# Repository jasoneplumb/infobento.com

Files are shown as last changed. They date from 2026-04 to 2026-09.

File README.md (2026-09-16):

# InfoBento

> _See what matters. Skip the spiral._












A small, solar-powered eInk decorator that lives on a counter, shelf, or windowsill. Configure once on a web page; it shows what matters most: weather, hourly and daily forecasts (configurable, 3 periods by default), air quality, UV index, pollen, quote, countdown, stocks, QR code, text, date, moon phase, sunrise/sunset, year progress, horoscope, on this day, holidays.

**Prototype, not a shipping product.** Firmware is bench-verified on a Seeed reTerminal E1001 (ESP32-S3) development board; the production ESP32-C3 hardware, the solar harvester, and the unattended run time that follows from them are design targets that have not been built or measured. Everything below marked _(target)_ is a specification, not an observed result. The product description is the design intent; [Status](#status) is what exists today.

## Overview

InfoBento is a small calm surface for the room. The information you check most often (whether it's going to rain, whether the air is clear enough to open the windows, days until something you're looking forward to) sits there in crisp eInk, visible at a glance from across the room. One-time Wi-Fi and sign-in setup, then no batteries to swap and nothing to fiddle with day to day.

Building a layout in the web editor needs no account; it saves to your browser.
Binding a device to that layout does: you claim it with a passkey or a Google/Apple
sign-in, so the server knows whose config to render for it.

Set it on a kitchen counter, a desk, or a shelf. The body is its own stand, with a fold-out kickstand to angle the display toward you if needed. The upper portion of the back is a solar panel intended to charge the device from indirect light through a window _(target; no energy balance has been measured)_. It refreshes a few times a day, which is plenty for the things you actually look at it for. Planned Kickstarter pricing: $109 early bird (first 500), $129 standard, or $239 for a pair ($119.50 each; ≈ $46.40 BOM at volume, the 5.76" panel is over half of it).

### Hardware

- **Display:** Good Display GDEH0576T81, 5.76" eInk, 920x680 pixels, 198 DPI, SSD2677 driver
- **Renderer:** eInk framebuffer with antialiased TTF fonts (Inter via opentype.js), SDF-based rounded box borders, configurable corner radius (0-7) and padding (0-10), font size stepper (8-42px)
- **MCU:** ESP32-C3 _(target)_ (Wi-Fi 4 + BLE 5; BLE radio reserved for a possible v2 bridge mode). Firmware bring-up runs on a reTerminal E1001 (ESP32-S3) bench board; the C3 port is pending.
- **Power:** ~100 mAh LiPo + AEM10941 solar harvester _(target)_. Deep-sleep current is still unmeasured: the bench USB meter resolves 10 mA and reads 0.00 A asleep, which cannot confirm a µA-class floor. Unattended run time follows from that measurement and is not yet claimed.
- **Solar panel:** mounted on the upper portion of the back side, ~70×100 mm
- **Connectivity:** Wi-Fi direct + captive-portal setup; no companion phone app. Web editor at `www.infobento.com` is the only configuration surface. See `docs/hardware/CONNECTIVITY.md`.
- **Recovery:** recessed pinhole reset (~2mm) on the back-lower grip area; press with paperclip for 5s = factory reset.
- **Form factor:** monolithic body, no hinge. The body stands on its own, with a fold-out kickstand to angle the display if needed.
- **Orientation:** two ball-in-tube tilt switches mounted at 90° on GPIO interrupts; firmware auto-rotates the layout across landscape, portrait, and inverted variants. Zero standby current, ~$0.10 BOM.
- **Industrial design:** white housing, thin bezel (≤4mm visible)
- **Drop survival:** designed to survive a 4-foot drop onto a hard surface: soft polymer bumper between glass and housing, edge-radiused corners, inset display recess

### Form factor

```
┌────────────────────┐  ◄── thin white bezel
│                    │
│   eInk             │      Front: display recessed below bezel rim
│   panel            │             so the rim shields the glass on
│                    │             a face-down drop
│                    │
└────────────────────┘
       ▲                   Back-upper: solar panel
       │ ~12-15° tilt      Back-lower: ESP32 + battery + grip area
       │ when set down
```

### Architecture

```
┌─────────────────┐    Wi-Fi     ┌──────────────┐
│     Device       │◄────────────►│  Cloud API   │
│  eInk            │              │ Hono + SQLite│
│  ESP32 + solar   │              └──────────────┘
└─────────────────┘                      ▲
                                         │
                                   ┌─────┴─────┐
                                   │  Web UI    │
                                   │  (config)  │
                                   └───────────┘
```

Rendering is a pure function of config: `POST /api/render` takes a BentoConfig and returns a frame buffer, and the web editor's preview uses exactly that path. The device never sends a config; it identifies itself with its device id and the server renders from the config it holds for that device. If Wi-Fi is unavailable the panel keeps showing its last frame (stale display, not blank). eInk holds its image with no power and no redraw. First-time setup via captive portal; on each refresh the device polls `www.infobento.com/api/device/{device-id}/frames` for a freshly rendered frame (both orientations in one response), using its device id as a bearer secret. Both orientations are written to a LittleFS partition so the green button can redraw the other one locally with the radio off ([firmware README](firmware/README.md)); that cache serves the flip, not a fallback render: the device never renders a frame itself. The web editor is where you set up your boxes; configuration lives in browser localStorage, and once a device is paired to an account it is also stored server-side and pushed via `PUT /api/device/{device-id}/config`.

## Quick Start

```bash
# Clone and install
git clone https://github.com/jasoneplumb/infobento.com.git
cd infobento.com
npm install

# Build and verify
npm run build
npm test
npm run lint

# Run the dev servers (two terminals)
npm run dev -w @infobento/api    # Hono API on :4000
npm run dev -w @infobento/web    # Vite editor on :5173, proxies /api to :4000
```

## Monorepo Structure

| Package | Name | Purpose |
| --- | --- | --- |
| `packages/core/` | `@infobento/core` | Types, bento box definitions, layout engine |
| `packages/data/` | `@infobento/data` | Box-data providers (weather, quote, …) + cache |
| `packages/renderer/` | `@infobento/renderer` | eInk frame buffer generation |
| `packages/api/` | `@infobento/api` | Render API, auth + pairing (SQLite), static files |
| `packages/web/` | `@infobento/web` | Web configuration interface |

## Self-hosting & auth env vars

The hosted SaaS (`infobento.com`) is the default path, but the API code is
public so you can run it yourself. The auth flows in `@infobento/api` need
the following env vars at runtime:

| Variable | Purpose |
| --- | --- |
| `SESSION_SECRET` | HMAC key for session + challenge cookies. Required. ≥16 chars, generate randomly. |
| `RP_ID` | WebAuthn Relying Party ID: your domain (e.g. `infobento.com`). |
| `RP_ORIGIN` | Origin(s) the browser will use, comma-separated (e.g. `https://www.infobento.com`). |
| `OAUTH_REDIRECT_BASE`  | Base URL for OAuth callbacks (e.g. `https://www.infobento.com/api/auth/oauth`). |
| `GOOGLE_CLIENT_ID` | Google OAuth client ID. Get from console.cloud.google.com → Credentials. |
| `GOOGLE_CLIENT_SECRET` | Google OAuth client secret. |
| `APPLE_CLIENT_ID` | Apple "Service ID" identifier (e.g. `com.example.signin`). |
| `APPLE_TEAM_ID` | Apple Developer team ID (10-char alphanumeric). |
| `APPLE_KEY_ID` | Apple "Sign in with Apple" private key ID (10-char alphanumeric). |
| `APPLE_PRIVATE_KEY` | PEM-encoded ES256 private key (PKCS8) for Apple. Multi-line; use the literal value. |
| `INFOBENTO_DB_PATH` | (Optional) SQLite file path. Default `/var/lib/infobento/data.db`. |

Setting up the OAuth credentials:

- **Google:** create an OAuth 2.0 Client ID (Web application) at
  [console.cloud.google.com → APIs & Services → Credentials](https://console.cloud.google.com/apis/credentials).
  Authorized redirect URI: `https://<your-domain>/api/auth/oauth/google/callback`.
- **Apple:** at [developer.apple.com → Certificates, Identifiers & Profiles](https://developer.apple.com/account/resources/identifiers/list):
  1. Create an App ID with "Sign in with Apple" capability.
  2. Create a Services ID (this is your `APPLE_CLIENT_ID`); enable Sign in with Apple
     and configure return URLs: `https://<your-domain>/api/auth/oauth/apple/callback`.
  3. Create a Key with "Sign in with Apple" enabled; download the `.p8` and note the
     Key ID (`APPLE_KEY_ID`). Your team ID is in the top-right of the Developer portal.

If neither OAuth provider is configured, the app falls back to passkey-only
auth (still usable on any modern browser/OS). Passkey login does not require
OAuth credentials at all.

## Manufacturing: device stickers

Each device ships with a sticker carrying a QR code that opens its pairing page
(`/pair/<pair_code>`) plus the human-readable pair code as a camera-free fallback.
Generate sticker artwork from a CSV of minted devices:

```bash
# CSV columns: device_id,pair_code  (header row optional)
npm run gen-stickers -- scripts/sample-devices.csv stickers/

# Add a tiled, print-ready batch sheet (A4 by default; --page letter for US):
npm run gen-stickers -- devices.csv stickers/ --sheet --page letter

# Point the QR at a non-production origin (self-host / staging):
npm run gen-stickers -- devices.csv stickers/ --base-url https://staging.infobento.com
```

Output is one `<device_id>.svg` per row (designed to print at 25mm × 25mm) and,
with `--sheet`, page-sized `sheet.svg` (or `sheet-1.svg`, `sheet-2.svg`, … when
the roster spans multiple pages) you can open in a browser and Print → PDF. Pair
codes and device ids are validated, so a typo in the CSV fails loudly instead of
producing an unscannable sticker or escaping the output directory. The QR encodes
only the pair code, never the device id, which is the firmware's bearer secret.

Mint the devices first with [`scripts/mint-device.ts`](scripts/mint-device.ts).

## Documentation

See [docs/README.md](docs/README.md) for the full documentation index.

## Contributing

See [CONTRIBUTING.md](CONTRIBUTING.md) for development workflow and guidelines.

## License

InfoBento is open-source hardware. Each part of the repo uses the license that
fits the work, and **all of them permit building and selling devices based on
this design**:

- **Software** (`packages/`, `scripts/`, root): [Apache-2.0](LICENSE)
- **Hardware** (`hardware/`): [CERN-OHL-P-2.0](hardware/LICENSE)
- **Documentation** (`docs/`): [CC-BY-4.0](docs/LICENSE)

See [LICENSING.md](LICENSING.md) for the full breakdown. Copyright © 2026 Jason
E Plumb and InfoBento contributors.

## Results

| | |
| --- | --- |
| **Contribution** | Sole author of the renderer, web service, device-pairing flow, and firmware sketches, AI-assisted under CI and bench verification. Third-party: the Seeed reTerminal E1001 bench board, Good Display panel, AEM10941 harvester, and the box-data providers' upstream APIs. |
| **Status** | Prototype. Firmware bench-verified on a reTerminal E1001 (ESP32-S3); production ESP32-C3 hardware not built. No manufacturing, no Kickstarter launched, no users. |
| **Verification** | Firmware phases 0–7 bench-verified on the E1001 (epic #106): blink, static frame, Wi-Fi device pull, deep sleep, resilience, captive-portal provisioning, and the integrated build, including `304 -> skip` conditional-refresh behavior, dual-orientation LittleFS caching with radio-off button flip, empty-store guard, and factory reset. Per-phase records in [`firmware/README.md`](firmware/README.md#phase-status). |
| **Reproduction** | Web service: see Quick Start. Firmware: the per-phase procedures in `firmware/README.md` on a reTerminal E1001. Power figures need µA-grade instrumentation the bench does not have. |
| **Limitations**  | Deep-sleep current is unmeasured: the bench USB meter resolves 10 mA and reads 0.00 A asleep, which cannot distinguish ~50 µA from a hidden ~10 mA, and the E1001's always-on peripherals read higher than the C3 target regardless. Solar autonomy and unattended run time are therefore design targets, not results. The firmware's TLS certificate validation gap is a known production-readiness defect (see `firmware/README.md`). Pricing and BOM figures are estimates for hardware that has not been built. |

## Status

Active development. Renderer produces framebuffers with 18 box types. Web editor at localhost:5173 for configuration. Passkey + Apple/Google OAuth and the SaaS device-pairing flow are shipped in `@infobento/api` (epic #77 complete). Firmware bring-up is dev-first on the reTerminal E1001: Phases 0–7 are bench-verified (epic #106) - blink, static-frame, Wi-Fi device-pull, deep-sleep, resilience, captive-portal provisioning, and the integrated firmware ([`firmware/integrated/integrated.ino`](firmware/integrated/integrated.ino), #174). The remaining production-hardware step is sourcing the GDEH0576T81 panel + ESP32-C3 (dev work continues on the E1001). Per-phase status lives in [`firmware/README.md`](firmware/README.md#phase-status).

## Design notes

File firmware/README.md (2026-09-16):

# InfoBento firmware (bench bring-up)

Dev-first firmware for epic #106. These are **bench sketches**, not a structured
firmware project yet: each is a single self-contained Arduino `.ino` that proves
one capability on the dev hardware before the next builds on it.

- **Dev board:** Seeed reTerminal E1001, ESP32-S3, 7.5" 800×480 grayscale panel
  driven by a UC8179 controller.
- **Production target (not yet sourced):** GDEH0576T81 5.76" 920×680 + ESP32-C3
  (#57 closed; 4-level gray proven on the E1001, panel sourcing remains). The
  production port re-points the integrated build to it.

The reTerminal maps 1:1 onto the renderer's 2-bit output and hits the **identical**
cloud endpoints, so everything proven here ports directly to production.

## Toolchain

[`arduino-cli`](https://arduino.github.io/arduino-cli/) with the `esp32` core.
All sketches build for `esp32:esp32:esp32s3` (ESP32S3 Dev Module).

```bash
arduino-cli core install esp32:esp32
arduino-cli compile --fqbn esp32:esp32:esp32s3 firmware/<sketch>
arduino-cli upload  -p /dev/cu.usbserial-XXXX --fqbn esp32:esp32:esp32s3 firmware/<sketch>
arduino-cli monitor -p /dev/cu.usbserial-XXXX -c baudrate=115200
```

Serial routes to UART0 (the onboard USB-UART bridge, `/dev/cu.usbserial-*`) because
the core's `USB CDC On Boot` defaults to Disabled. If you enable CDC-on-boot, Serial
moves to the native USB port (`/dev/cu.usbmodem*`) and bridge-port prints vanish.

## Phase status

| Phase | Sketch | Proves | Status |
| ----- | --- | --- | --- |
| 0 | (server) `scripts/mint-device.ts` | mint device, `/frame` returns 200 | ✅ done (PR #109) |
| 1 | [`blink/`](blink/blink.ino) | toolchain + boot + serial, no panel | ✅ bench-verified |
| 2 | [`static-frame/`](static-frame/static-frame.ino) | framebuffer-translation path: native 2bpp → UC8179 two-plane upload (4-band gray ramp) | ✅ bench-verified |
| 3 | [`device-pull/`](device-pull/device-pull.ino) | Wi-Fi + `GET /api/device/<id>/frame` poll loop with `If-Modified-Since`/304 skip | ✅ bench-verified |
| 4 | [`deep-sleep/`](deep-sleep/deep-sleep.ino) | deep sleep + RTC wake; RTC-persisted `Last-Modified` so a 304 wake skips the refresh | ✅ bench-verified |
| 5 | [`resilient/`](resilient/resilient.ino) | resilience: graceful 404/429/5xx/Wi-Fi-fail handling, brownout recovery, clean draw-abort | ✅ bench-verified |
| 6 | [`provisioning/`](provisioning/provisioning.ino) | captive-portal provisioning: AP-mode first boot, Wi-Fi scan/entry → NVS, OS auto-launch probes, pinhole factory reset → #39 | ✅ bench-verified |
| 7 | [`integrated/`](integrated/integrated.ino) | integrated build → #173: provisioning + dual-orientation deep-sleep pull (`GET /frames`) + green-button flip + two-white-button (5 s) factory reset (#171/#172) | ✅ merged (PR #174) |
| N/A | N/A | port to production GDEH0576T81 + ESP32-C3 (#57 closed; gray proven on the E1001; panel not yet sourced) | ⬜ (awaiting panel) |
| ★ | [`orientation/`](orientation/orientation.ino) | manual orientation toggle → #160: `GET /frames` caches BOTH orientations in LittleFS, green button (GPIO3, ext1) flips locally with Wi-Fi off | ✅ folded into `integrated/` (#174) |

"Bench-verified" = run on real E1001 hardware. Phase 3 evidence lives in the
(gitignored) `dev/serial.log`: a live run shows `GET → 200`, `drew frame in
4486 ms`, then steady `304 → skip refresh`.

**Phase 4 bench-verified on the E1001** (`IB_SLEEP_SECONDS` = 30 s bench cadence).
A live run captured the full state machine on serial:

- each wake boots from deep sleep (`rst:0x5 (DSLEEP)`, `wake cause 4 (RTC timer)`)
  and the `boot #N` counter increments across sleeps, proving the RTC-persisted
  state (`RTC_DATA_ATTR`: boot counter + cached `Last-Modified`) survives;
- steady state (no server change): `GET -> 304 ... skip refresh` then straight
  back to `deep sleep`: **no `drew frame`, panel does not flash**;
- push a new config server-side → the next wake logs `GET -> 200`, the new
  `Last-Modified`, and `drew frame in 4486 ms`; the wake _after_ that returns to
  `304 -> skip`, confirming the new token was cached to RTC and the panel redraws
  exactly once per change.

To reproduce the 200-draw: `firmware/dev/push-config.sh <config> <device-id>`
(point `INFOBENTO_DB_PATH` at the DB the running API opened; `lsof` it if unsure).

Bench power snapshot (USB inline meter, 10 mA resolution, DROK VB26VA), board
level over USB:

- **304 wake** (no redraw): **≈ 80 mA for ~2 s** (the Wi-Fi blip), then sleep.
  ≈ 0.04 mAh per wake.
- **200 wake** (panel refresh): the Wi-Fi blip **plus** a **4.5 s draw at ≈ 60 mA
  sustained, peaking ≈ 150 mA** in the final ~1 s (last waveform phase / booster).
  ≈ 0.15 mAh per wake.
- **Deep sleep:** reads `0.00 A`, i.e. **< 10 mA** at the board level.

So the active side is cheap: even at a worst-case "redraw every wake," 1–2 wakes/
day is well under 1 mAh/day, and the daily budget is dominated entirely by the
sleep floor.

Still open: that floor is **below this meter's 10 mA resolution**, so the real
**single-digit-µA** figure remains unmeasured: the gap is decisive (≈50 µA →
~1 mAh/day vs a hidden ~10 mA → ~240 mAh/day). Capturing it needs a µA-grade
instrument on the **battery/supply line** (not USB): the reTerminal dev board
reads higher than the ~10 µA production target because of its always-on
peripherals + USB-UART bridge, so the definitive number is an ESP32-C3
measurement deferred to the production port.

**Phase 5 bench-verified on the E1001** (`IB_SLEEP_SECONDS` = 30 s bench cadence). A
live run walked all five cases on serial; in every failure case the panel kept its
last good frame and the device slept and recovered on its own:

- **API down** → `GET -> -1` → `keep last frame, retry next wake` → `deep sleep 30 s`;
  restarting the server → a later wake reconnects (`304 -> skip`).
- **Unprovisioned id** (config cleared in the DB) → `GET -> 404 ... unprovisioned ->
keep last frame`, no draw.
- **Wi-Fi failure** (bogus SSID) → `Wi-Fi FAILED -> keep last frame, retry next wake`,
  sleeps without hanging.
- **Rate limit** (device id hammered past 10/min) → `GET -> 429 -> honor Retry-After,
sleep 60 s`; note the **60 s** back-off, distinct from the normal 30 s.
- **Normal** (bumped `last_modified`) → exactly one `GET -> 200 ... drew frame`, then
  `304 -> skip` on the next wake (token committed to RTC only after the confirmed draw).

**Phase 5 bench check (operator).** Flash `resilient/` and force each failure: in
every case the panel must keep its last good frame (never blank/garble) and the
device must sleep and recover on its own:

- **API down:** stop the Hono server → `GET -> <negative>` → `keep last frame,
retry next wake` → `deep sleep`. Restart the server → a later wake draws normally.
- **Unprovisioned id:** point `secrets.h` at a device with no config (or clear it in
  the DB: `UPDATE devices SET config_json=NULL WHERE id=…`) → `GET -> 404 ...
unprovisioned` → sleep, no draw.
- **Wi-Fi failure:** break the **SSID** (point at a non-existent network) → `Wi-Fi
FAILED` → `keep last frame` → sleep (no hang, no crash). Note: breaking `WIFI_PASS`
  does **not** work on an **open** network: an open AP associates with any password
  string, so it would falsely "pass". Break the SSID (works on any network), or break
  the password only against a **WPA2** AP.
- **Rate limit:** hammer the device id past 10/min (e.g. burst `curl …/config` for it)
  → `GET -> 429 ... honor Retry-After, sleep 60 s`. The bucket is per-device-id and
  shared across `/config` + `/frame`, and refills 1 token/6 s, so sustain the burst
  across a wake.
- **Normal:** unchanged config still `304 -> skip`; a pushed config (or a bumped
  `last_modified`) still draws once then returns to 304 (token committed only after
  the confirmed draw).

**Phase 6 bench-verified on the E1001.** A live run walked the full out-of-box
flow on serial: first boot → `no creds -> AP mode, SSID 'InfoBento-C93F'` →
`captive portal up`; an iPhone auto-launched the setup page; scan + join saved
creds and rebooted into `provisioned=1`, which then rejoined silently
(`provisioned + online -> hand off to pull loop`). The pinhole factory reset,
wrong-password rejection, and unreachable-network AP fallback all behaved as
specified (see the checklist below). Two bench notes: the wrong-password path is
only meaningful against a **WPA2** network: an open AP (no auth) associates with
any password string, so test it with a password-protected 2.4 GHz hotspot (the
ESP32-S3 has no 5 GHz radio; on iPhone enable Personal Hotspot → Maximize
Compatibility to force 2.4 GHz). Use a separate device as the portal client: a
phone serving the hotspot can't simultaneously join the `InfoBento-XXXX` AP.

**Phase 6 bench check (operator).** Provisioning needs AP mode + a phone, so it
can't be CI-verified; flash `provisioning/` and walk the out-of-box flow. The
sketch has NO `secrets.h` (it has no creds to begin with). Watch serial at
115200:

- **First boot (no creds):** `no creds -> AP mode, SSID 'InfoBento-XXXX'` then
  `captive portal up`. A factory device must always land here.
- **Auto-launch:** join the open `InfoBento-XXXX` network from a phone/laptop:
  the OS should pop a browser straight onto the setup page (Apple
  `hotspot-detect.html`, Android `generate_204`, Windows `ncsi.txt` all 302 to
  the portal). If it doesn't auto-open, browse to `http://192.168.4.1`.
- **Scan + join:** the network dropdown is populated server-side (no JS). Pick
  your home Wi-Fi, type the password, **Connect** → `joining '<ssid>' ...` →
  `joined, IP …` → `provisioned -> creds saved` → the success page shows the
  Device ID → `rebooting into provisioned mode`. (Pairing actually happens at
  `www.infobento.com/pair/<code>` after sign-in; the sketch still prints a dead
  `infobento.com/onboard?device=<id>` URL here; the sketch-side fix is tracked
  in #241.)
- **Wrong password:** the portal must re-render with a retry banner and NOT
  persist the bad creds (`join FAILED`, no `creds saved`).
- **Returning boot (creds saved):** after the reboot, `provisioned=1` → it
  rejoins the saved network silently (`hand off to pull loop`), no AP. Move the
  device to an unreachable network → it falls back to AP mode for re-setup.
- **Pinhole reset:** ground the pinhole pin for 5 s →
  `PINHOLE 5s hold -> factory reset (clearing creds)` → reboot → back to AP
  mode. A momentary tap must NOT reset (the hold timer resets on release). On the
  E1001 the pinhole maps to **GPIO2** (expansion header J2 pin 4, one pin from
  GND on pin 2; note the header is numbered in reverse of the silk/spec table);
  GPIO9 is the production-C3 pin but on the E1001 it is the panel SPI MOSI line.
- **Page budget:** the setup page is a few KB of inlined HTML/CSS, no JS, no
  external assets, comfortably inside the <30 KB-gzipped target.

`PINHOLE_GPIO` and the AP/NVS specifics are marked MCU-specific in the sketch for
the ESP32-C3 production port. Production uses **GPIO9** (the C3 strapping pin with a
natural pull-up: the reason #39 picked it); the `IB_DEV_E1001` branch swaps in
**GPIO2** for bench bring-up because on the E1001 dev board GPIO9 is the panel SPI
MOSI line (and GPIO0/BOOT is tied to the USB-serial auto-reset), so neither can
serve as the pinhole there. Note the later `integrated/` build (#171/#172) moved
factory reset off the pinhole entirely: holding the **two white buttons** for 5 s
(GPIO4+GPIO5) is now the reset gesture; the pinhole story above applies to this
provisioning-era sketch.

**Orientation toggle (`orientation/`, #160 / RFC 0002).** This behavior now lives
in the integrated sketch (`integrated/`, PR #174); the notes below cover the
standalone bench sketch. Extends the Phase 4 deep-sleep pull: each network wake fetches BOTH orientations in
one `GET /api/device/<id>/frames` and stores them to a LittleFS partition; a green-
button press (GPIO3, ext1 deep-sleep wake) redraws the other cached orientation with
the radio off. The server delivers both frames in the panel's landscape raster
(portrait pre-rotated server-side, PR #164), so `uploadFrame` is orientation-agnostic.
The GPIO2 reset pinhole is untouched: a distinct input from the toggle button.

Flash with the 8 MB partition scheme **and declare `FlashSize=8M`**: the FQBN
defaults to 4 MB, which overflows the `default_8MB` table and boot-loops
(`partition N ... exceeds flash chip size 0x400000`). The E1001 is physically 32 MB;
Seeed's Arduino guidance is to select 8 MB. Then provide `orientation/secrets.h`
(gitignored, mirror `deep-sleep/`'s):

```
arduino-cli compile -u -p /dev/cu.usbserial-XXXX \
  --fqbn 'esp32:esp32:esp32s3:UploadSpeed=115200,FlashSize=8M,PartitionScheme=default_8MB' firmware/orientation
```

(Fallback if that ever boot-loops: drop `FlashSize` and use `PartitionScheme=default`;
the 4 MB scheme still carries a ~1.4 MB LittleFS partition, plenty for the ~192 KB
pair.)

**Orientation bench check (operator).** Watch serial at 115200:

- **First network wake (cold boot / timer):** `GET /frames -> 200` → `stored both
frames` → `drew frame` in landscape. A second wake within the window logs
  `304 -> keep cached frames, no redraw` (the Phase 4 power win still holds).
- **Button flip:** press the green button → `(green button)` wake, `flip landscape to
portrait`, `drew frame`: **with no `GET`** (radio stays off). Press again → flips
  back. Confirm the flip is ~one refresh, not a Wi-Fi cycle.
- **Orientation is up-right:** if portrait shows upside-down, flip the server-side
  rotation direction from `'cw'` to `'ccw'` in `getDeviceFramesForPull` (`device.ts`),
  not a firmware change.
- **Empty store guard:** press the button before the first network wake ever ran →
  `no cached frame to flip to (empty store) -> no-op` (no garbage drawn).
- **Persistence across power loss:** flip to portrait, pull the battery/USB, repower →
  cold boot restores `portrait` from NVS (not silently back to landscape).
- **Reset pinhole unaffected:** the GPIO2 pinhole still factory-resets via the
  provisioning sketch; the toggle button (GPIO3) never clears creds.

MCU-specific for the ESP32-C3 production port: the green-button GPIO and the ext1
wake API (C3 uses `esp_deep_sleep_enable_gpio_wakeup`) are re-mapped; the toggle logic
is otherwise identical.

## Framebuffer translation (the key risk Phase 2 retired)

The renderer emits **native** 2bpp, MSB-first, 4px/byte, `0=white … 3=black`. The
UC8179 grayscale path wants `0=black … 3=white`. Because the packing is identical,
the per-pixel `3 - level` flip is exactly a per-byte bitwise NOT
(`0x00↔0xFF`, `0x55↔0xAA`); see `drawFrame()`. The UC8179 driver (pins, LUTs,
init, two-plane upload, refresh, sleep) is vendored verbatim from Seeed's
`GxEPD2_reTerminal_E1001_Gray4` example, including its internal `3 - gray`
waveform-polarity inversion. Pin map: SCK 7, MOSI 9, CS 10, DC 11, RES 12, BUSY 13.

## Secrets & dev tooling (gitignored)

`device-pull` needs a `secrets.h` in its sketch dir:
`firmware/device-pull/secrets.h` (Arduino resolves `#include "secrets.h"`
relative to the `.ino`). Not committed; `firmware/**/secrets.h` is gitignored:

```c
// LAN dev server (plain HTTP):
#define WIFI_SSID   "your-ssid"
#define WIFI_PASS   "your-pass"
#define IB_API_HOST "192.168.x.x"   // dev machine running the Hono API
#define IB_API_PORT "4000"
#define IB_DEVICE_ID "<id from `npm run mint -w @infobento/api`>"
#define IB_API_TLS  0               // deep-sleep only: 0 = http (LAN dev)
```

For the **production** server (`deep-sleep` sketch), keep the same `WIFI_SSID` /
`WIFI_PASS` as above and change the API fields to point at `www.infobento.com`
over HTTPS (mint the device id on the host; see `docs/DEPLOY.md`):

```c
#define WIFI_SSID   "your-ssid"     // same Wi-Fi creds as above — still required
#define WIFI_PASS   "your-pass"
#define IB_API_HOST "www.infobento.com"
#define IB_API_PORT "443"
#define IB_DEVICE_ID "<id minted on the prod host>"
// IB_API_TLS defaults to 1 (https) — omit, or set explicitly:
#define IB_API_TLS  1
```

`IB_API_TLS` is a build-time **switch**, not a statement about which sketches can
speak HTTPS. How each one chooses its transport:

| Sketch | Transport |
| --- | --- |
| `deep-sleep`, `orientation` | `IB_API_TLS` macro, defaults to `1` (https); set `0` in `secrets.h` for LAN dev |
| `integrated` | runtime: HTTPS iff the stored server URL starts with `https` |
| `device-pull`, `resilient`  | HTTP only, by design (LAN bench tools) |

So three sketches can reach production over TLS, and none of them verifies the
certificate; see the warning below.

> ### ⚠️ These sketches do not verify TLS certificates
>
> Every sketch that speaks HTTPS (`deep-sleep`, `orientation`, `integrated`)
> calls `client.setInsecure()`, which disables certificate validation entirely.
> Combined with the fact that **the device id is a bearer secret carried in the
> URL path** (`/api/device/<device-id>/frames`), an attacker positioned between
> the device and the network (a hostile Wi-Fi access point, a compromised
> router, an ARP-spoofing neighbour) can present any certificate, read the
> device id, and from then on impersonate the device or pull its owner's
> rendered frames.
>
> This is acceptable for **bench work on a network you control**, which is all
> these sketches are currently used for. It is **not** acceptable for firmware
> shipped on hardware in other people's homes.
>
> Hardening is tracked in **#145**: pin the ISRG Root X1 CA via
> `client.setCACert(...)`, add an explicit `http.setTimeout()` so the TLS
> handshake has margin, and optionally persist the TLS session ticket in RTC
> memory across wakes. Anyone building on this firmware for real deployment
> should do that first.

`provisioning` is the **exception**; it has no `secrets.h` and needs none: the
whole point of captive-portal setup is that the device starts with no creds and
obtains them from the user, so it compiles and runs with nothing pre-baked.

`firmware/dev/` (also gitignored) holds bench helpers: `push-config.sh`,
`serial-boot.sh`, `config-e1001.json`, and captured `serial.log`.

## Forward plan

1. **Phase 4 - deep sleep + RTC.** ✅ bench-verified (`deep-sleep/`). The
   `loop()` `delay(IB_POLL_MS)` busy-wait is gone: the whole
   cycle runs in `setup()` and ends in `esp_deep_sleep_start()` for the
   `IB_SLEEP_SECONDS` build constant. `Last-Modified` persists across sleeps in
   RTC slow memory (`RTC_DATA_ATTR`), so a 304 wake returns to sleep without
   touching the panel. This is what makes the solar/battery budget real.
2. **Phase 5 - resilience.** ✅ bench-verified (`resilient/`). Every failure mode
   degrades gracefully: Wi-Fi down / wrong
   creds / 404 (unprovisioned) / 5xx / transport error → don't draw, sleep the
   normal cadence, retry next wake (eInk holds the last good frame for free, so no
   flash framebuffer cache is needed); 429 → honor `Retry-After`; brownout reset →
   skip the fetch and sleep a longer recovery interval. Two correctness fixes over
   Phase 4: `checkBusy` records a timeout so `drawFrame()` aborts cleanly on a stuck
   panel, and the cached `Last-Modified` is committed to RTC **only after a
   confirmed draw** (else a failed refresh would 304 the next wake and strand the
   panel on a frame that never rendered).
3. **Phase 6 - captive portal (#39).** ✅ bench-verified (`provisioning/`).
   AP mode on first boot, on-device no-JS setup
   page (server-side Wi-Fi scan → creds + optional custom server URL self-host
   hatch), NVS storage, OS auto-launch probes, and a pinhole factory
   reset (GPIO2 on the E1001; GPIO9 is the production-C3 pin; see the Phase 6
   bench check above; the later `integrated/` build moved factory reset to the
   two white buttons held 5 s, #171/#172). Creds persist only after a confirmed join, so a wrong password never
   strands un-joinable creds in NVS; a returning device with un-joinable saved
   creds falls back to AP for re-provisioning. The web-side "forget Wi-Fi"
   counterpart (`POST /api/device/:id/forget`, same effect as the pinhole) is
   the server half, merged separately (#39). This is the gate to a shippable
   out-of-box flow.
4. **Phase 7 - integrated build (#173).** ✅ merged (PR #174, `integrated/`):
   provisioning + dual-orientation deep-sleep pull + green-button flip +
   two-white-button factory reset in one sketch.
5. **Production port.** Re-point pins/dimensions to GDEH0576T81
   (920×680, 156,400-byte frame) on ESP32-C3 once the panel is sourced
   (#57 closed; gray rendering proven on the E1001).

### Shared UC8179 driver - extraction deferred (decision)

The UC8179 driver (pins, 5 gray LUTs, `initGrayMode`/`uploadFrame`/`refresh`/
`sleep`) is still copy-pasted across `static-frame`, `device-pull`, `deep-sleep`,
and now `resilient` (5 copies). Phase 4 was the nominal time to extract it, but
**it stays vendored per-sketch on purpose**: Arduino's build model can't share a
header across sibling
sketch folders without breaking the documented zero-flag build. `arduino-cli
compile firmware/<sketch>` only sees the sketch dir (and its `src/` subfolder) plus
_installed_ libraries: a real shared header needs either a library + a
`--libraries firmware/libraries` flag (changes the build command everyone runs and
adds a library-management step that fights the "self-contained bench sketch"
philosophy) or a copy in each sketch's `src/` (not actually shared). The clean home
for this is a proper Arduino library when the firmware graduates from bench sketches
(Phase 6/7), where a real project layout earns the build-command change.

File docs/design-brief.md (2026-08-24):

---
title: 'InfoBento Design Brief'
subtitle: 'UX model, requirements, and design decisions'
date: 'June 2026'
---

# InfoBento Design Brief

_A calm bento dashboard for counters, desks, and shelves._

**Domain:** Consumer electronics
**Phase:** Campaign (pre-Kickstarter)
**Last reviewed:** 2026-08-23, against v0.38.3

---

## Product Overview

InfoBento is a small, solar-powered eInk bento dashboard for counters, desks, and shelves. It is glance-first: a calm multi-box dashboard that configures once and refreshes on schedule.

- **Positioning:** A lean, calm bento dashboard for counters, desks, and shelves.
- **UI model:** Multi-box bento dashboard — up to 10 boxes (no fixed constant: the layout engine derives the row cap as `min(10, max(4, floor(height / (fontSize × 3))))`), multi-column.
- **Display:** Good Display **GDEH0576T81**, 5.76" eInk, **920×680 px**, **198 DPI**, **SSD2677** driver IC, eInk. Framebuffer **156,400 bytes** (packed 2-bit, 4 levels per pixel). Refresh 1–3×/day (default 3); 0.75 s full / 0.3 s partial (datasheet). Active area 117.7×87.0 mm; module 125.4×99.5×0.9 mm.
- **Enclosure:** white monolithic housing ≈14×11 cm sized to fit the GDEH0576T81 closely; thin bezel ≤4 mm; body-as-stand, with a fold-out kickstand to angle it ≈12–15° if needed.
- **MCU:** ESP32-C3 (Wi-Fi + BLE; BLE reserved for a possible v2 bridge). Captive-portal setup; no companion app v1; config via the infobento.com web editor.
- **Power:** ≈70×100 mm solar panel on the upper back + ≈100 mAh LiPo + AEM10941 solar harvester; 1–3 refreshes/day (default 3).
- **Orientation:** two ball-in-tube tilt switches for orientation auto-rotate.
- **Interaction:** minimal device interaction — two controls in the shipped firmware: a green button flips orientation, and holding the two white buttons for 5s factory-resets.

Configure once at the infobento.com web editor; the display then runs quietly on solar power, refreshing on schedule.

---

## 1. Work Roles

### Device Owner

Individual who owns an InfoBento display and places it on a counter, shelf, or windowsill.

**Responsibilities:**

- Configure bento boxes via web UI
- Place device on a counter or shelf with the solar panel exposed to indirect window light
- Complete first-time captive-portal Wi-Fi setup
- Update configuration occasionally as priorities change

### Gifter

Person who purchases and pre-configures an InfoBento as a gift for someone else.

**Responsibilities:**

- Select and order device
- Configure initial bento layout for recipient
- Share config JSON with recipient (export/import in the web editor), or claim the device to an account and save the layout server-side before gifting

---

## 2. User Classes

### Desk Decorator (Primary)

Person who values aesthetic, minimal desk or counter accessories and wants a bento-box-sized eInk display that shows a multi-box dashboard of useful status boxes -- standing on its own, the body is the stand.

**Goals:**

- Have a visually pleasing desk or counter accessory that is also functional
- Show countdown to meaningful events
- Display a personal link or QR code for networking
- A device that charges itself near a window without any cables

**Frustrations:**

- Digital photo frames are too large and power-hungry
- Sticky notes with countdowns look unprofessional
- No small, elegant way to display a personal QR code
- Desk gadgets always need cables or batteries

### Daily Glancer (Secondary)

Busy professional who wants a calm passive display of key daily info -- weather, next event, a quote -- visible at a glance from across the room. The founder is this user.

**Goals:**

- See today's weather and schedule without picking up a phone
- Reduce screen time by offloading ambient info to a passive display
- Customize what info matters most to them

**Frustrations:**

- Checking phone for simple info leads to distraction rabbit holes
- Smart home displays are too expensive and power-hungry
- Existing e-paper gadgets are not customizable
- Every phone interaction is an attention trap

### Gift Giver

Someone who wants to give a thoughtful, personalized tech gift that is useful without being overwhelming.

**Goals:**

- Give a unique gift that feels personal and curated
- Pre-configure the device so the recipient can use it immediately
- Gift something that does not require technical knowledge to enjoy

**Frustrations:**

- Most tech gifts require complex setup
- Generic gifts lack personal touch
- Subscription-based gifts feel like an obligation

---

## 3. Design Principles

### Zero Device Interaction

> InfoBento has no buttons. The entire loop is configure once, glance often.

Zero interaction remains the design ideal, but the shipped firmware keeps two deliberate controls: the green button flips orientation, and holding the two white buttons for 5s factory-resets. Nothing on the device configures content. The display charges via solar passively and refreshes on schedule; everything else happens in the web editor.

| Do | Don't |
| --- | --- |
| Glance at counter display from across the room | Require a button press to refresh |
| Configure once in the web editor | Dedicated companion app |
| Solar charging near a window without cables | Manual charging schedule or cable |
| Captive-portal first-time setup, no app | Notification stream or buzzer |

### Pure Function Architecture

> The API must be stateless -- same config in, same frame buffer out, every time.

No server-side state, no user accounts, no databases. Config lives on the client. Device caches last framebuffer in flash for offline resilience.

> **⚠️ Superseded (epic #77).** The principle above is retained as the original design record. It no longer describes the shipped system: the API stores accounts, device pairings, and per-device config in SQLite, and auth is passkey + Apple/Google OAuth. What survives is narrower — _rendering_ is still a pure function (`POST /api/render`: config in, frame buffer out), and the web editor's preview uses exactly that path. The device-facing `/frames` path is stateful by design: the device sends only its id, and the server renders from stored config. The flash-cache claim above also turned out to be unnecessary: eInk holds its last image with no power, so offline resilience needs no stored framebuffer (see `docs/hardware/CONNECTIVITY.md`).

### Visual Restraint

> A tight, intentional tonal palette used with discipline. Every tone earns its place.

The palette is deliberately restrained: a few intentional tones rather than a gradient, applied to express a clear visual hierarchy. Think newspaper print, not a photograph. Tone and contrast distinguish hero text, body text, and metadata — hero/display text reads large without needing maximum contrast, body text carries the most important content, and metadata sits quietly in support.

### Free by Default

> All box types must work without accounts, API keys, or subscriptions.

All box types use free data sources or local computation. Weather, forecasts, sunrise/sunset, air quality (AQI), UV, and pollen use Open-Meteo cloud data. Quotes use a quotable mirror (api.quotable.kurokeita.dev), stocks use Yahoo Finance, horoscope uses api-ninjas, on-this-day uses Wikipedia, and holidays use Nager.Date. The rest — QR, text, date, moon phase, countdown, and year progress — are pure local computation.

### Web-Only Configuration

> InfoBento is configured exclusively from a web browser. No native phone app required.

The web editor at infobento.com is the only configuration surface. No companion iOS or Android app for v1. This removes ≈6+ months of engineering scope and the iOS background BLE risk.

### Solar-Powered Counter Display

> A single monolithic body that stands on its own, with a fold-out kickstand to angle it if needed.

White monolithic enclosure ≈14×11 cm sized to fit the GDEH0576T81 (5.76", 920×680) closely, with a thin bezel (≤4 mm) and a fold-out kickstand for ≈12–15° tilt. Solar panel on the upper back, with the AEM10941 harvester topping up the ≈100 mAh LiPo. Two ball-in-tube tilt switches drive orientation auto-rotate.

---

## 4. Requirements

| ID | Statement | Priority |
| --- | --- | --- |
| REQ-001 | User can configure up to 10 bento boxes via web interface | Must |
| REQ-002 | Device syncs via Wi-Fi direct, no companion phone app | Must |
| REQ-003 | Display refreshes 1–3x/day on solar power alone (default 3, configurable) | Must |
| REQ-004 | 18 box types without user accounts; derived cap of 10 | Must |
| REQ-005 | Web UI and API served from same port in production | Must |
| REQ-006 | Config persists in localStorage with JSON export/import | Must |
| REQ-007 | QR code gets ≈half display height for scannability | Must |
| REQ-008 | Live PNG preview before syncing to device | Must |
| REQ-009 | V1 uses an eInk panel (display color capability TBD) | Must |
| REQ-010 | Enclosure ≈14x11cm, fits GDEH0576T81 panel closely | Must |
| REQ-011 | Display >=198 DPI, <=4mm visible bezel | Should |
| REQ-012 | Auto-rotate via two tilt switches, 4 orientations | Must |
| REQ-013 | Minimal interaction — orientation + factory reset buttons | Must |

---

## 5. Scenarios

### Morning Glance at Kitchen Counter

**User class:** Daily Glancer
**Setting:** Kitchen counter near window, 7:15 AM, making coffee

Sam's InfoBento is standing on the kitchen counter near the window, its solar panel catching the morning light. The crisp 5.76" eInk display shows a multi-box dashboard: weather (62F, partly cloudy), a countdown (14 days to vacation), today's date, and a motivational quote. Sam grabs a jacket based on the weather and notes the vacation countdown. The display refreshed on schedule at 6 AM via Wi-Fi.

**Preconditions:** Device completed captive-portal Wi-Fi setup; config has weather, countdown, date, and quote boxes; device refreshed on schedule.

**Postcondition:** User has ambient awareness of weather, date, and upcoming event without touching any device.

### First-Time Web Configuration

**User classes:** Daily Glancer, Desk Decorator
**Setting:** Home office, laptop open, just unboxed the device

Alex opens infobento.com. The web UI shows a live eInk preview on the left with the editor on the right. They add Weather (type Portland -- geocoded via Nominatim), add Countdown (anniversary date), add a Date box, and a Quote box. The live preview updates after each change. They click Export Config and save the JSON as a backup. The config stays server-side: Alex signs in and claims the device by its Device ID, while the device's captive-portal setup takes only Wi-Fi credentials and that Device ID — no config is ever uploaded to the device.

### Gifting a Pre-Configured Device

**User class:** Gift Giver
**Setting:** Living room, wrapping gifts

Jordan buys an InfoBento for their friend who loves hiking. They configure 3 boxes: weather for the friend's city, a countdown to their next planned hike, and a QR code linking to their shared trail playlist. Jordan signs in, claims the device to an account by its Device ID, and saves the layout server-side, then includes a card with setup instructions. The friend opens the gift, connects to the device's captive portal, enters their Wi-Fi password and the Device ID from the sticker, and the display pulls Jordan's curated layout from the server within a minute.

---

## 6. Wireframes

### Device Display

Single eInk panel (Good Display GDEH0576T81, 5.76", 920×680, 198 DPI), enclosure ≈14x11cm (fits the panel closely with a thin bezel). Tilt switches detect orientation -- layout auto-rotates.

**Elements:**

- Up to 10 boxes filling the panel area (row cap derived from panel height and font size; minimum 4 rows)
- Inter TTF hero font for primary data, body font for labels
- SDF-antialiased rounded box borders on grey background
- Configurable corner radius (0-10) and padding (0-10)
- 4-level grayscale: anti-aliased fonts, grey labels for hierarchy
- Multi-column layouts via horizontal splits
- Auto-rotate based on tilt switch orientation

### Web Configuration Editor

Two-column layout at ≥1024px: preview on the left, editor on the right (stacking to a single column on narrow screens). Vanilla TS with reactive state, no framework.

**Elements:**

- Live eInk preview (server-rendered PNG, portrait + landscape); the simulator defaults to the reTerminal E1001 800×480 profile, with switchable resolutions
- Box list with up/down reordering, remove button, inline-editable labels
- Add-box chip palette (all 18 types, one click to add)
- Per-box config forms (location for weather, date for countdown, URL for QR, etc.)
- Consent dialog (Privacy + Terms) on first load
- Font size, corner radius, and padding slider controls
- JSON import/export via Menu dropdown
- Browser geolocation on first load for auto-detected weather
- Debounced auto-fetch (500ms) on city input

---

## 7. Config Delivery

```
User                          Cloud                        Device
  |                              |                            |
  |-- configure on web --------->|                            |
  |                              |                            |
  |   [first time]               |                            |
  |                              |<--- captive portal --------|
  |                              |     (Wi-Fi creds +         |
  |                              |      Device ID only)       |
  |                              |                            |
  |   [updates]                  |                            |
  |-- push config to cloud ----->|                            |
  |                              |<- poll /api/device/ID/frames -|
  |                              |---- framebuffer binary --->|
  |                              |                            |
  |                              |     [no flash cache: eInk  |
  |                              |      retains the image;    |
  |                              |      RTC memory keeps      |
  |                              |      Last-Modified + a     |
  |                              |      boot counter]         |
```

---

## 8. Rendering Pipeline

```
BentoConfig (JSON)
    |
    v
Zod validation
    |
    v
Layout engine (vertical stack + horizontal splits)
  - Configurable padding (0-10)
  - Content-aware height allocation
  - QR boxes get ≈50% display height
    |
    v
Box renderers (18 types)
  - Inter TTF via opentype.js
  - Hero (bold) + body (regular) weights
  - 3-tier contrast: hero (dark grey), body (black), metadata (light grey)
    |
    v
Draw primitives
  - SDF-antialiased rounded rectangle borders
  - Configurable corner radius (0-10)
  - Grey background (GRAY_LIGHT) with white box interiors
    |
    v
eInk framebuffer (156,400 bytes, 920×680)
    |
    v
PNG export (4-level grayscale mapping)
```

---

## 9. Design Decisions

### Type System

The `BentoBox` interface uses a discriminated union pattern -- each box type gets its own interface pairing type with config -- so type/config mismatches (`{ type: weather, config: { type: text } }`) are caught at compile time.

### eInk Design Research

Research across Tidbyt, Watchy, TRMNL, thermal printer art, and eInk phone accessories yielded key patterns that drive the rendering model:

1. One dominant element -- a single large hero element taking 40-50% of height
2. Two font sizes max -- large hero + small data, no medium
3. Whitespace beats borders -- generous padding between sections
4. Receipt-style layout -- label left-aligned, value right-aligned
5. 3-4 data items max per frame
6. Static > interactive -- single-purpose static frames work best
7. No touch required -- treat the display as output-only

---

## 10. Cost and Pricing

Total BOM is approximately **$46.40** at Kickstarter volume (qty ≈1k), dominated by
the 5.76" panel at over half the cost.

| Component | Est. cost | Basis |
| --- | --- | --- |
| GDEH0576T81 panel | ≈$24 | $26.82 single-unit retail; $23–26 wholesale |
| ESP32-C3-MINI-1 | ≈$2.80 | $2.79 LCSC, $3.26 DigiKey |
| ≈100 mAh LiPo | ≈$2 | estimate |
| Solar panel | ≈$3 | estimate |
| AEM10941 energy harvester | ≈$4.40 | €4 direct, at EUR/USD ≈1.10 |
| USB-C charge | ≈$2 | estimate |
| PCB + passives | ≈$3 | estimate |
| Housing | ≈$5 | estimate |
| Tilt switches | ≈$0.20 | estimate |

Panel, MCU, and harvester were priced against distributor listings on 2026-08-19;
the rest remain estimates. No volume quote has been obtained, and the panel is
the only line where that materially changes the total.

**Price target:** $109 early bird (first 500) / $129 standard / $239 gift pair
(Kickstarter), shipping charged at cost.

### Where the tiers come from

The market was surveyed on 2026-08-19:

| Product | Price | Display | Power |
| --- | --- | --- | --- |
| TRMNL OG | $139 | 7.5" eInk  | 1800 mAh battery, 3–6 months  |
| TRMNL X | $219 | 10.3" eInk | battery (duty cycle unstated) |
| Tidbyt Gen 2  | $189 | 64×32 LED  | mains |
| LaMetric Time | $199.99 | LED | mains |

The category floor is **$139**, not the $129 previously assumed. That leaves
headroom, but InfoBento's panel is the smallest in the set (5.76" against
TRMNL's 7.5"), so the standard tier is set to undercut the closest comparable
rather than match it. $109 early bird is a 22% undercut of the floor — a real
hook that still clears the margin the campaign needs.

### Unit economics

Shown in full, because the totals matter more than the prose:

| Per pledge |  $109 tier |  $129 tier | $239 pair (2 units) |
| --- | ---: | ---: | ---: |
| Pledge | $109.00 | $129.00 | $239.00 |
| Platform + payment fees (8%) | −$8.72 | −$10.32 | −$19.12 |
| BOM | −$46.40 | −$46.40 | −$92.80 |
| Packaging | −$3.00 | −$3.00 | −$6.00 |
| Replacement allowance | −$5.00 | −$5.00 | −$10.00 |
| **Net per pledge** | **$45.88** | **$64.28** | **$111.08** |
| **Net per device** | **$45.88** | **$64.28** | **$55.54** |

A 500/500 split across the two single-unit tiers yields about **$55k** — enough
to absorb the one-time costs (injection-mould tooling, FCC/CE, UN38.3) that no
per-unit line covers.

The original $49–69 target was negative on the same inputs once ≈$15 of absorbed
worldwide shipping was added: about **−$7 at $69** and **−$25 at $49**. No volume
fixed that, because the shortfall scaled with units sold.

Two changes were needed, not one. Charging shipping at cost is necessary but not
sufficient: without it, $69 clears only ≈$8 and $49 is still ≈$10 in the red. The
price increase is what creates the headroom.

---

## 11. Open Items

| Item | Status | Blocking |
| --- | --- | --- |
| Hardware dev kit validation (#57) | Closed — validated on E1001 | Resolved |
| Grey fallback -- Floyd-Steinberg dithering (#56) | Deferred | Grey proven on E1001  |
| Wire 5 new boxes into web UI (#53) | Done — all 18 wired | Resolved |
| Content-aware layout for all types (#54) | Shipped v0.13.0 | Resolved |
| Price validation at volume | Needs quotes | Kickstarter pricing |
| SCAD enclosure model (#199, supersedes #50) | Open | Prototype photography |
| Captive-portal firmware (#39) | Bench-verified | Resolved |
| Tilt switch hardware (#48) | Open | Auto-rotate |

---

_InfoBento -- A calm bento dashboard for counters, desks, and shelves._
_Phase: Campaign | Authored June 2026 | Last reviewed 2026-08-23 against v0.38.3_

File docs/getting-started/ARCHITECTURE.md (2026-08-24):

# Architecture

## System Overview

InfoBento is a small, solar-powered eInk decorator that lives on a counter, shelf, or windowsill. Configure once on the web; the device fetches server-rendered frames from the cloud API and shows what matters most — weather, air quality, a countdown, a quote — refreshing a few times a day (default 3, configurable) on solar power alone.

```
┌──────────────┐    Wi-Fi     ┌─────────────┐
│    Device     │◄────────────►│  Cloud API  │
│  eInk         │              │ (Hono on DO)│
│  ESP32-C3     │              │ + SQLite    │
└──────────────┘              └─────────────┘
                                      ▲
                                      │
                                ┌─────┴─────┐
                                │  Web UI    │
                                │  (config)  │
                                └───────────┘
```

Device makes outbound HTTPS calls to the cloud API. No companion phone app; the web editor at `infobento.com` is the only configuration surface. First-time setup uses a captive-portal Wi-Fi pairing flow; recovery via a factory reset (hold both white buttons for 5 seconds). See `docs/hardware/CONNECTIVITY.md`.

### Operating Profile

Single mode: counter-standing. Refreshes 1–3× per day (default 3) on solar power. There is no phone-mounted mode. Native phone apps + BLE bridge are deferred to a possible v2 (see `docs/hardware/CONNECTIVITY.md`'s "v2 path" section).

### Data Flow

1. **User** configures bento boxes via the **Web UI** (browser localStorage, plus server-side storage once the device is paired to an account). The device is pointed at its device id during captive-portal setup, then polls `infobento.com/api/device/{device-id}/frames` each refresh cycle for a server-rendered frame.
2. **Device** stores its Wi-Fi credentials, device id, and server URL in ESP32 NVS — not the bento config, which lives server-side.
3. **Device** wakes on RTC alarm, joins saved Wi-Fi, and issues `GET /api/device/{device-id}/frames` over HTTPS, sending `If-Modified-Since` so an unchanged frame costs a 304.
4. **Cloud API** looks up the device's stored config, hydrates live box data, renders both orientations, and returns them.
5. **Device** writes the framebuffer to the eInk display and returns to deep sleep. The framebuffer itself does not survive sleep — only `Last-Modified` and a boot counter persist, in RTC slow memory (`RTC_DATA_ATTR`).
6. **Offline resilience:** if Wi-Fi is unavailable, the panel simply keeps showing the last frame it was given (stale content, not blank). This is a physical property of eInk, not a cache — no flash copy of the framebuffer is needed. (The `integrated`/`orientation` sketches do keep a LittleFS copy of both orientations, but that exists to serve the local orientation flip with the radio off, not for offline resilience.)

### Key Design Decisions

- **Pure-function rendering** — `POST /api/render` is config in, frame buffer out, with no state involved. The device-facing path is not stateless: since epic #77 the server stores accounts, device pairings, and per-device config in SQLite, and renders from that.
- **eInk rendering** — production target is the GDEH0576T81 panel driven via SSD2677 partial-refresh waveforms (panel not yet sourced); bench-verified today on the reTerminal E1001.
- **Solar-only power** — refresh budget sized to the solar harvest budget for moderate indoor light; USB-C tops up the battery when needed.
- **Wi-Fi direct + web-only config** — no native phone app for v1. Captive-portal setup, web editor handles configuration.
- **Minimal device interaction** — configure once via web, glance forever. The only physical affordances are the green button (orientation flip) and the two white buttons (held 5 s, factory reset for Wi-Fi recovery); day-to-day use needs none of them.
- **Drop survival** — designed for a 4-foot drop onto a hard surface (bumper layer, edge-radiused corners, recessed display).

## Package Architecture

| Package | Depends on | Role |
| --- | --- | --- |
| `@infobento/core` | — | Types, constants, layout engine  |
| `@infobento/data` | core | Box-data providers + cache |
| `@infobento/renderer` | core | eInk framebuffer generation |
| `@infobento/api` | core, data, renderer | Hydrates box data, then renders  |
| `@infobento/web` | core, data | Config UI; reaches api over HTTP |

Dependencies flow strictly downward in that table — nothing depends on a package
listed below it, and there are no cycles.

- **data** is browser- and edge-safe: pure `fetch`, no DOM or `window` — that
  holds for the barrel; the `@infobento/data/safe-fetch` subpath (the SSRF
  guard) is Node-only and deliberately kept out of the barrel
- **web** reaches `api` over HTTP and never imports it directly
- **web** does **not** depend on `renderer`: the editor previews by calling
  `POST /api/preview`, so nothing is rasterized in the browser

## Server Architecture

Same-port pattern (like phasebot): Hono serves both API and web UI.

```
Development:
  Vite (:5173)  ──proxy /api──►  Hono (:4000)
   └── HMR                         └── API routes only

Production:
  Internet
     │
     ▼
  DigitalOcean droplet (co-tenant with tiles- and webmap.dev)
     │
     ▼
  nginx (TLS termination, reverse proxy) — host-managed, not provisioned from this repo
     │
     ▼
  Hono on Node, bound to 127.0.0.1:4000, managed by systemd
     ├── /api/*  → API routes
     └── /*      → Static files from web/dist (SPA fallback)
```

The apex `infobento.com` 301-redirects to `www.infobento.com`, which is the
canonical host. See [DEPLOY.md](../DEPLOY.md) for the host layout, the
version-controlled systemd unit, and the required secrets.

- **Hono** chosen for: lightweight, pure-function friendly, runs unchanged on Node
- **Vite proxy** in dev: `/api` requests forwarded to Hono; all other requests served by Vite with HMR

## Deployment

- **DigitalOcean droplet** ($6/mo tier handles 10K-100K devices comfortably; co-tenant with tiles- and webmap.dev so marginal cost for InfoBento is ~$1-2/mo)
- **nginx** on the droplet terminates TLS and reverse-proxies to Hono on `127.0.0.1:4000`. It is configured on the host, not from this repo — the only deploy-managed server config here is [`deploy/infobento.service`](../../deploy/infobento.service).
- **Single port:** Hono serves API + web UI from one port (default 4000), behind nginx
- **Migration path:** the pure render path (`POST /api/render`, `/api/preview`, `/api/validate`) is portable to Workers/Deno/Bun unchanged. The auth, pairing, and device-config paths are **not** — `better-sqlite3` is a native module, so those are Node-bound until the store is swapped.
- **Device firmware:** in this repo under [`firmware/`](../../firmware/README.md) — Arduino sketches for the ESP32-S3 dev board (reTerminal E1001), targeting ESP32-C3 for production.

**Not yet built:** there is no OTA firmware distribution — no `/api/firmware/*`
route exists, and nothing serves `.bin` files. Firmware is flashed over USB
(see [`firmware/README.md`](../../firmware/README.md)). There is also no
Cloudflare proxy in front of the origin today; the droplet's nginx is reached
directly.

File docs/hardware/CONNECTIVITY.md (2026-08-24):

# Connectivity

## Decision (locked 2026-04-22)

InfoBento v1 ships **Wi-Fi direct + web-only** (a plain SPA — no PWA manifest or service worker). No native phone app. The web editor at `infobento.com` is the only configuration surface. Native apps and BLE bridging are deferred to a possible v2 if backers fund them.

### Why

The box types InfoBento ships (weather, countdown, quote, holidays, qr, among 18 types) all work fine at 1–3 refreshes per day (default 3, configurable). There is no real-time latency requirement, so the entire native-app stack stays off v1's critical path.

This walks back two earlier-considered options:

- **Phone-bridged BLE** would require iOS + Android companion apps, carry iOS background-BLE risk, and add ~6+ months of engineering before launch
- **Hybrid (BLE when phone present, Wi-Fi when not)** would require both stacks plus the dual-platform native app investment

Pure Wi-Fi-direct + web app cuts the engineering scope to something a solo founder can ship pre-Kickstarter, while still meeting all the user needs the box types actually serve.

### What this means concretely

- **MCU:** ESP32-C3 (Wi-Fi 4 + BLE 5). BLE radio is on the chip but unused in v1; remains available for a v2 BLE bridge without a hardware refresh.
- **Connectivity:** device makes outbound HTTPS calls to the cloud API. Cloud API hosted on DigitalOcean droplet (co-hosted with tiles- and webmap.dev) with Cloudflare in front for DNS + CDN + DDoS + TLS edge.
- **Configuration surface:** web editor at `infobento.com`. Browser localStorage for state. JSON import/export already shipped.
- **Companion app:** none.
- **Setup:** captive-portal Wi-Fi pairing on first boot.
- **Recovery:** recessed pinhole reset on the back-lower (grip area), centered, ~2mm hole. Press with paperclip for 5 seconds = factory reset (clears Wi-Fi credentials and any device-side config; device re-enters captive-portal AP mode). Documented on a small label on the back.

---

## First-time setup flow (captive portal)

Standard pattern, well-trod in IoT (every smart bulb does this):

1. Device boots. Finds no saved Wi-Fi credentials in NVS flash.
2. Device enters AP mode and advertises an SSID like `InfoBento-A1B2` (last 4 bytes of MAC).
3. User joins that network from any phone or laptop.
4. The OS detects a captive network (no internet) and auto-launches a browser to the device's setup page.
5. The device serves a small HTML setup page from its onboard web server. The page scans for nearby Wi-Fi networks, presents a dropdown, accepts a password.
6. User selects their home Wi-Fi, types the password, hits Connect.
7. Device saves credentials to NVS, joins the home network, AP mode shuts down.
8. The portal's success page shows the Device ID; the user then signs in at `www.infobento.com` and pairs the device at `www.infobento.com/pair/<code>`. (The shipped firmware still prints a dead `/onboard` URL on this page — the sketch-side fix is tracked in #241.)

The captive-portal HTML is part of the firmware — small enough to fit in flash without bloat.

## Config delivery

Config flows to the device in two stages:

1. **First-time (captive portal):** During AP-mode setup, the user enters Wi-Fi credentials, the Device ID from the pairing sticker, and optionally a custom server URL for self-hosting. The device stores those three values in ESP32 NVS. The bento config itself is never uploaded to the device — it lives server-side, bound to the account that claimed the device.
2. **Ongoing (cloud poll):** The device polls `infobento.com/api/device/{device-id}/frames` on each refresh cycle, sending `If-Modified-Since` so an unchanged frame costs a 304. The server renders from the config it holds for that device; the device redraws only when the frame changes (a 304 sends it straight back to sleep without touching the panel).

### Server-side rendering

The device does not render locally. On each refresh cycle it sends only its device id — the bearer secret — and the server renders from the config it holds for that device, returning a framebuffer. If Wi-Fi is unavailable, the panel shows stale content rather than going blank — eInk holds its last image with no power and no stored copy, so no flash framebuffer cache is required. Only `Last-Modified` and a boot counter persist across sleeps, in RTC slow memory. (The `integrated`/`orientation` sketches additionally cache both orientations in LittleFS, so the green-button flip can redraw with the radio off.)

### Storage

- **Wi-Fi credentials, device id, server URL:** ESP32 NVS (survives deep sleep and power loss; cleared by factory reset)
- **Config:** server-side only — stored against the device row in SQLite, never written to NVS
- **Last framebuffer:** none — the eInk panel itself retains the last image with no power, so no flash frame cache is needed; only `Last-Modified` and a boot counter persist across sleeps, in RTC slow memory

## Recovery (pinhole reset)

The shipped device has three buttons: a green orientation-flip button and two white buttons that, held together for 5 seconds, perform the factory reset (#171/#172). The pinhole reset described below remains on the provisioning-era sketch (GPIO2 on the E1001) and as the original design rationale.

- **Location:** back-lower (grip area), centered, ~2mm diameter, recessed
- **Action:** press with paperclip for 5 seconds
- **Effect:** factory reset — clears Wi-Fi credentials and any device-side cached config; device re-enters captive-portal AP mode on next boot
- **Why pinhole vs button:**
  - Smaller stress concentrator on a 4-foot drop than a clickable button
  - Doesn't require a separate housing opening (just a small recess in the bumper)
  - Industry-standard interaction (routers, smart speakers, mesh nodes — users won't be confused)
  - Can't be triggered accidentally
  - Documented on a small label on the back so users know what it's for

A web-side "forget Wi-Fi" command from the editor is also possible (`infobento.com` → device-status page → "forget Wi-Fi" button), but only works while the device has Wi-Fi. The pinhole is the dead-device backstop.

## Power profile (for reference)

See `docs/hardware/POWER.md` for the full breakdown. Summary per refresh on Wi-Fi:

- ~70 mA active for ~10-20s during Wi-Fi connect + frame fetch
- Per-refresh budget: ~1.5-2.5 mAh
- Daily budget: ~4.5-7.5 mAh at the default 3 refreshes/day (~3.5 mAh at 2/day)
- Inside the solar harvest budget (5-15 mAh/day from indirect window light), with less margin in low-light placements

## v2 path (post-Kickstarter, if funded)

If backers want the calendar / real-time / phone-integration story later, the architecture supports it without a hardware refresh:

- **Native iOS / Android apps** as a v2 product — same hardware, new firmware track that uses the unused BLE radio
- **BLE bridge mode** can coexist with Wi-Fi-direct: device tries BLE first when phone is in range, falls back to Wi-Fi
- **Calendar box** that pulls from EventKit (iOS) / CalendarContract (Android) and pushes to device via BLE — this is what would actually motivate adding the native apps

None of this changes the v1 device. It's a firmware update + companion app, both shippable post-launch as a stretch goal or follow-on product.

## What's NOT in v1

- Native iOS app
- Native Android app
- BLE pairing flow
- Calendar / next-event box (no source-of-truth without phone integration)
- Real-time push from phone to device

These were all considered and consciously deferred to v2. (User accounts, originally deferred here too, have since shipped — epic #77: passkey + Google/Apple OAuth sign-in, device claiming, and a per-account Devices list, with each device's config stored server-side against the account that claimed it.)

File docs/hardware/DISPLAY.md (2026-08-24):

# Display Specifications

## eInk Module

InfoBento targets a Good Display GDEH0576T81 eInk panel mounted on the front of a monolithic counter device. The GDEH0576T81 purchase is currently deferred; initial development runs on off-the-shelf 7.5" panels — see [Prototyping Hardware](#prototyping-hardware) below.

- **Panel:** Good Display GDEH0576T81
- **Type:** eInk (electrophoretic)
- **Resolution:** 920x680 pixels, 198 DPI
- **Driver IC:** SSD2677
- **Active area:** 117.7 x 87.0 mm
- **Module size:** 125.4 x 99.5 x 0.9 mm
- **Refresh rate:** 1-3x per day (default 3, configurable) (matches the device's solar power budget and the calm-display use case)

Resolution, frame buffer size, and levels are defined by `DISPLAY_WIDTH` / `DISPLAY_HEIGHT` / `DEFAULT_FRAME_BYTES` constants in `packages/core/src/constants.ts`.

## Prototyping Hardware

The GDEH0576T81 (5.76", 920×680) is the production target. Until that panel is sourced, development and the web simulator run on the **Seeed reTerminal E1001** — a 7.5", 800×480 ePaper display with 4-level grayscale and an integrated ESP32-S3. (The standalone Seeed XIAO 7.5" panel is the same 800×480 panel on a XIAO driver board.) The reTerminal's 4-level grayscale maps 1:1 onto the renderer's 2-bit output.

The web simulator switches between display resolutions via the **Display** dropdown (driven by `DEVICE_PROFILES` in `@infobento/core`, default = reTerminal E1001 800×480; the GDEH0576T81 920×680 target is also selectable). Add new panels by appending to that list — the renderer honors per-config `width`/`height`, so any profile renders at its native resolution and aspect ratio.

## Form Factor

Single front-mounted panel inset into a white housing with a thin bezel (<=4 mm visible on all sides). The recess is deep enough that the bezel rim shields the glass on a face-down drop. `hardware/infobento.scad` is a legacy dual-display clamshell mockup from an earlier design direction; the SCAD model for the current 5.76" monolithic body is planned (#199). See `docs/hardware/DROP-TEST.md` (planned, #36) for the drop survival protocol.

## Frame Buffer Format

The renderer outputs a packed 2-bit-per-pixel frame buffer:

- **Bit depth:** 2 bits per pixel (4 levels)
- **Packing:** 4 pixels per byte, MSB-first
- **Byte order:** packed left-to-right, no alignment padding within a row
- **Total size:** 156,400 bytes for 920x680 (920 \* 680 / 4)
- **Level values (current renderer):** 0 = white, 1 = light gray, 2 = dark gray, 3 = black. The panel's grayscale runs the opposite way (0 = black … 3 = white), so firmware applies a per-pixel `3 − level` flip when uploading.

## Refresh Strategy

Single mode, calm and infrequent.

| Mode | Refresh Rate | Refresh Time | Use Case |
| --- | --- | --- | --- |
| Counter (default and only) | 1-3x per day (default 3) | 0.75s full, 0.3s partial | Kitchen counter / desk / shelf -- solar powered |

The SSD2677 driver IC supports both full and partial refresh. Full refresh clears ghosting artifacts; partial refresh is faster and used when only a subset of the display content changes. The 0.75s/0.3s figures are production-panel datasheet numbers, not yet validated on hardware; the measured full 4-gray refresh on the E1001 dev panel is ~3.6–4.5s. Either way, refreshes are infrequent enough at the 1-3x per day cadence not to matter.

## Bento Box Layout

The 5.76" 920x680 landscape panel supports comfortable multi-column layouts. There is no fixed box cap; `packages/core/src/layout.ts` derives the row budget as `MAX_ROWS = min(10, max(4, floor(totalHeight / (fontSize * 3))))`, so it scales with panel height and font size, with configurable padding and corner radius. Layout is handled by the layout engine in `@infobento/core`.

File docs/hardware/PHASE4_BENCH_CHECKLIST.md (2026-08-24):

# Phase 4 — Operator Bench-Verification Checklist

Deep sleep + RTC wake on the reTerminal E1001 (`firmware/deep-sleep/deep-sleep.ino`,
epic #106). This expands the "Phase 4 bench check" note in
[`firmware/README.md`](../../firmware/README.md) into a step-by-step the operator
runs at the bench.

A Claude session can write, compile, flash, and read serial — but the
**panel-visual** and **power-draw** confirmations need your eyes and a meter.
Those are the items only you can sign off.

## A. Pre-flight

- [ ] reTerminal E1001 connected via USB to the bench machine.
- [ ] `firmware/deep-sleep/secrets.h` present (gitignored) with **real** values:
      `WIFI_SSID`, `WIFI_PASS`, `IB_API_HOST` (the Hono API on your LAN or prod),
      `IB_API_PORT`, `IB_DEVICE_ID` (mint one: `npx tsx scripts/mint-device.ts`).
- [ ] Server reachable from the device:
      `curl http://<host>:<port>/api/device/<id>/frame` returns `200`.
- [ ] Serial monitor open at **115200** on the bridge port (`/dev/cu.usbserial-*`).
- [ ] **USB inline power meter** (or PSU mA readout / Nordic PPK2) between USB and
      the board — this is the one instrument that proves Phase 4 worked.
- [ ] `IB_SLEEP_SECONDS` is the bench default (~30 s) so you aren't waiting the
      production ~8 h between wakes (default 3 refreshes/day).

## B. Functional checks (serial-observable)

- [ ] Builds + flashes clean; cold boot prints `boot #1, wake cause 0 (cold boot)`
      (the `wake cause N` number helps diagnose unexpected wakes).
- [ ] **Cold cycle:** Wi-Fi connect → `GET -> 200` → `drew frame in ~4500 ms` →
      `deep sleep for 30 s` → goes quiet.
- [ ] **Timer wake:** ~30 s later it wakes on its own and prints
      `boot #2 … (RTC timer)` — confirms real deep sleep + timer wake, not a `delay()`.
- [ ] **304 skip (the important one):** with nothing changed server-side, the wake
      logs `GET -> 304` then `304 not modified -> skip refresh` (two separate lines)
      and returns straight to `deep sleep` —
      **no `drew frame` line, and the panel does not flash.**
- [ ] **Boot counter climbs** (`#1`, `#2`, `#3`, …) across wakes → proves the
      `RTC_DATA_ATTR` state (including the cached `Last-Modified`) survived deep
      sleep. A reset back to `#1` means RTC state was lost — that would also force a
      needless `200`/redraw every wake.
- [ ] **200 draw:** change the device config (web editor → edit a box, or re-run
      `setConfig`) so the frame is newer; a later wake logs `GET -> 200` + a fresh
      `drew frame` + the new `Last-Modified`.

## C. Physical / instrument checks (only you can do these)

- [ ] **Panel correct:** image matches the config, sharp 4-level gray; it updates
      **only** on a `200` wake and never flickers/redraws on a `304`.
- [ ] **Current drops between wakes:** active (Wi-Fi + draw) is tens of mA; during
      deep sleep it falls to the board's floor. **On the reTerminal dev board the
      floor is NOT single-digit µA** — the board carries a USB-UART bridge and other
      peripherals. You're confirming a clear, repeatable **active → sleep drop**, not
      an absolute number. The production single-digit-µA target is an ESP32-C3
      measurement verified in the production port, not here.
- [ ] **Wake spike is brief:** current rises only for the fetch/draw window each
      cycle, then settles back to the floor.

## D. Sign-off

- [ ] One full run observed: cold draw → sleep → (`304` → sleep) ×N **with the boot
      counter climbing** → config change → `200` → draw → sleep.
- [ ] Record the `IB_SLEEP_SECONDS` used and the measured active / sleep currents in
      the Phase 4 PR.

---

**If a check fails**, capture the serial around it plus the meter reading and hand it
back to the session. Likely culprits:

| Symptom | Likely cause |
| --- | --- |
| Boot counter resets to `#1` each wake | `RTC_DATA_ATTR` state not persisting across sleep |
| `200` / redraw on every wake | cached `Last-Modified` not surviving sleep (`If-Modified-Since` sent empty) |
| Current doesn't drop in sleep | Wi-Fi modem / EPD not powered down before `esp_deep_sleep_start()` |
| Panel flashes on a `304` wake | refresh not gated on the `200` path |

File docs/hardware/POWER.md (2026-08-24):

# Power Budget

InfoBento runs on a small rechargeable LiPo battery topped up by a solar panel on the upper back of the enclosure. It is a calm dashboard: the display refreshes only a few times a day (default 3, configurable), and day-to-day use involves no interaction. The only loads are the eInk refresh and a Wi-Fi cloud poll per refresh, so the daily energy budget is small and comfortably covered by a ≈100 mAh LiPo with solar margin to spare.

## Design Constraints

- **Form factor:** countertop bento device. Front: Good Display GDEH0576T81 5.76" eInk (920×680, 198 DPI, SSD2677). Back-upper: solar panel. Back/side: ESP32-C3, LiPo, charging port, pinhole reset. A fold-out kickstand props the device at a viewing tilt on the countertop.
- **MCU:** ESP32-C3 (Wi-Fi for config + frame fetch; BLE reserved for v2)
- **Power source:** rechargeable ≈100 mAh LiPo + solar panel (≈70×100 mm, upper back) via an AEM10941 harvester
- **Display:** Good Display GDEH0576T81, 5.76" eInk, 920×680, 198 DPI, SSD2677 driver. ≈0.75 s full refresh, ≈0.3 s partial refresh, 1–3 refreshes/day (default 3). Exact refresh energy is unmeasured (TBD), but a full-panel refresh dominates the daily display energy at that cadence.
- **Interaction:** minimal. Three buttons — a green orientation-flip button and two white buttons whose 5-second combined hold performs a factory reset — plus two tilt switches that detect landscape vs portrait for auto-rotate. Otherwise the device wakes on a schedule, fetches a frame, refreshes, and returns to deep sleep.
- **Connectivity:** Wi-Fi direct (locked 2026-04-22 — see `docs/hardware/CONNECTIVITY.md`); BLE reserved for v2

## Daily Budget Summary

| Load | Daily mAh |
| --- | --- |
| eInk refresh (1–3× full + on-demand partial on alerts) | TBD; full-panel refresh dominates display energy at 1–3×/day |
| Wi-Fi connect + cloud poll (per refresh) | ≈0.5 |
| MCU active during refresh | ≈0.5 |
| **Total** | **TBD after panel + ESP32 validation; well under 100 mAh** |

With no always-on loads, the daily total is dominated by the eInk refresh and the Wi-Fi poll, both incurred only 1–3×/day (default 3). Between refreshes the ESP32-C3 sits in deep sleep at single-digit µA. A ≈100 mAh LiPo covers many days of operation on a single charge, and the solar panel keeps it topped up.

## Operating Profile

The device has a single power profile: countertop bento mode, refreshing 1–3×/day (default 3) plus partial refreshes for alerts or view cycling.

### Countertop Bento Mode

Display facing the room, propped on the fold-out kickstand. Rechargeable battery topped up by the upper-back solar panel. The MCU wakes on a deep-sleep RTC alarm, connects to Wi-Fi, fetches a cloud-rendered frame, performs a full or partial refresh, and returns to deep sleep.

| Component | Active | Sleep  | Duration |
| --- | --- | --- | --- |
| eInk full refresh (5.76") | TBD | 0 mA | ≈0.75 s (partial: ≈0.3 s) |
| Wi-Fi connect + fetch frame | ≈70 mA | ≈10 µA | ≈10–20 s |
| MCU active (during refresh) | ≈5 mA  | ≈10 µA | ≈15 s |

Wi-Fi is the dominant power cost per cloud-rendered refresh. With no always-on subsystems, the deep-sleep current floor sets the only continuous draw, and it is negligible against the daily budget.

## Power Sources

### Solar Harvesting

A ≈70×100 mm solar panel (≈$3) on the upper back of the enclosure feeds an AEM10941 harvester (≈$4.40) that tops up the rechargeable LiPo. Because the only loads are 1–3 refreshes/day (default 3), the harvest target is modest and the solar margin remains generous in indoor light — though thinner at the default 3×/day than at the original 1–2×/day design point. Panel placement should favor the upper-back facet so a kickstand-tilted device still catches ambient light.

## Open Questions

- Final battery + solar capacity for ESP32-C3 + GDEH0576T81 5.76" panel under the calm 1–3×/day profile (default 3)
- Measured full-panel and partial refresh energy for the GDEH0576T81 (SSD2677) under the current render pipeline
- How much daily margin the ≈100 mAh LiPo + solar harvest leaves after the refresh + Wi-Fi budget
- Cold-start behavior when the battery is fully depleted (especially in low-light placements)
- Refresh-time tolerance — if the device is in shade for a week, does it skip refreshes silently or surface a low-power state?
- Deep-sleep RTC alarm cadence and whether to align refreshes to solar-favorable hours

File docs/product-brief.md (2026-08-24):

---
title: 'InfoBento Product Brief'
subtitle: 'See what matters. Skip the spiral.'
date: 'June 2026'
---

# InfoBento Product Brief

**See what matters. Skip the spiral.**

A solar-powered eInk bento dashboard that sits on your counter, desk, or shelf. Weather, a countdown, a quote, air-quality status — visible at a glance from across the room, in crisp eInk. Built around a Good Display GDEH0576T81 5.76" panel (920×680, 198 DPI) driven by an ESP32-class controller. No cables, no app, no plugin marketplace.

---

## Product Overview

InfoBento is a calm surface for the room. The information you check most often — whether it's going to rain, air-quality status from cloud data, days until something you're looking forward to — sits there in sharp eInk, visible at a glance from across the room. The display is a multi-box bento dashboard (up to 10 boxes — the row cap is derived from panel height and font size, with a minimum of 4 rows — multi-column, with big glanceable numbers). Configure once on a web page; it sips light from the window and refreshes on its own.

Tidbyt and TRMNL are the ambient-display references. Against Tidbyt ($189), the contrast is the display itself: calm eInk rather than a glowing LED matrix. Against TRMNL ($139), also eInk and also battery-powered, the contrast is that InfoBento harvests its own power from window light instead of asking for a recharge every few months — on a smaller panel, at a lower price.

**Target price:** $109 early bird (first 500) / $129 standard / $239 gift pair — $119.50 per unit (Kickstarter), shipping at cost
**Distribution:** Kickstarter campaign

---

## Hardware Specifications

| Spec | Value |
| --- | --- |
| **Display** | Good Display GDEH0576T81 panel, ≈$24 |
| **Size** | 5.76" diagonal |
| **Resolution** | 920 × 680 pixels |
| **DPI** | 198 |
| **Display tech** | eInk (electrophoretic) |
| **Driver IC** | SSD2677 |
| **Active area** | 117.7 × 87.0 mm |
| **Module size** | 125.4 × 99.5 × 0.9 mm |
| **Refresh time** | 0.75s full / 0.3s partial (datasheet); 1–3 refreshes/day (default 3) |
| **MCU** | ESP32-C3-MINI-1, ≈$2.80, Wi-Fi + BLE (BLE reserved for a possible v2 bridge) |
| **Battery** | ≈100 mAh LiPo (≈$2); covers display + Wi-Fi only (no always-on sensors) |
| **Solar** | ≈70×100 mm amorphous-Si (≈$3) + AEM10941 harvester (≈$4.40, upper back) |
| **Charging** | USB-C, ≈$2 |
| **PCB + passives** | ≈$3 |
| **Enclosure** | ≈14 × 11 cm white monolithic housing (≈$5) sized to fit GDEH0576T81 closely; thin bezel ≤4 mm |
| **Orientation** | 2× ball-in-tube tilt switches (≈$0.20 total) drive orientation auto-rotate |
| **Stand** | Body-as-stand; fold-out kickstand angles it ≈12–15° if needed |
| **Connectivity** | Wi-Fi direct, captive portal setup |

**Total device BOM ≈ $46.40 at Kickstarter volume (qty ≈1k):** GDEH0576T81 panel ≈$24 (dominates), ESP32-C3-MINI-1 ≈$2.80, ≈100 mAh LiPo ≈$2, solar panel ≈$3, AEM10941 harvester ≈$4.40, USB-C charge ≈$2, PCB + passives ≈$3, housing ≈$5, 2× tilt switches ≈$0.20.

Priced against distributor listings on 2026-08-19: the panel is $26.82 at single-unit retail from Good Display (list $29.80), with wholesale listings at $23–26, so ≈$24 is a reasonable qty-1k figure; ESP32-C3-MINI-1-N4 is $2.79 at LCSC and $3.26 at DigiKey; the AEM10941 is ≈€4. The panel, MCU, and harvester are now grounded in real listings; LiPo, solar cell, USB-C, PCB, housing, and switches remain estimates. **Still pending a manufacturer quote at volume** — the panel is the line that matters, since it is over half the BOM.

---

## Form Factor

```
+-----------------------+
|                       |
|   eInk panel          |   Front: display nearly fills the face
|   920 x 680           |          minimal bezel (<=4mm)
|   198 DPI             |
|                       |
+-----------------------+
       ^                    Back-upper: solar panel (≈70x100mm)
       | ≈12-15 deg tilt    Back-lower: ESP32-C3 + LiPo + USB-C
       | body-as-stand
```

- Monolithic white housing, no hinge; fold-out kickstand to angle it
- Fold-out kickstand angles the display ≈12-15 deg toward a standing viewer
- Designed to survive a 4-foot drop (bumper layer, radiused corners, recessed display)
- Solar panel on the upper back
- USB-C charging port on bottom edge; factory reset by holding the two white buttons for 5s (the recessed pinhole reset survives only on the provisioning-era sketch)

---

## Software Architecture

```
+--------------------+   Wi-Fi      +--------------+
|       Device       |<------------>|  Cloud API   |
|   eInk             |              |  (Hono +     |
|   ESP32-C3         |              |  SQLite;     |
|                    |              |  renders)    |
+--------------------+              +--------------+
                                           ^
                                           |
                                     +-----+------+
                                     |  Web UI     |
                                     |  (config)   |
                                     +------------+
```

**Pure function API:** Config JSON in, framebuffer binary out — on the render path. ⚠️ No longer true API-wide: since epic #77 accounts, device pairings, and per-device config live in SQLite, and claiming a device requires a passkey or Google/Apple sign-in (see the note under "Pure Function Architecture" below).

**On-device mapping:** After the cloud returns the framebuffer, the firmware maps it to the 920×680 panel and applies orientation from the tilt switches.

**Config delivery:**

1. First-time: captive portal (device broadcasts `InfoBento-XXXX` SSID, user enters Wi-Fi credentials + the Device ID from the sticker)
2. Ongoing: device polls `infobento.com/api/device/{device-id}/frames` for a server-rendered frame
3. Wi-Fi credentials and device id stored in ESP32 NVS; config held server-side; no framebuffer cache needed (eInk holds the last image unpowered)

---

## Rendering Pipeline

| Stage | Detail |
| --- | --- |
| **Input** | BentoConfig (Zod-validated JSON) |
| **Layout** | Vertical stack + horizontal splits, configurable padding (0-10), content-aware height allocation |
| **Font** | Inter TTF via opentype.js, configurable 8-42px body, hero = body x 2.6 |
| **Borders**  | SDF-antialiased rounded rectangles, configurable corner radius (0-10) |
| **Contrast** | 3-tier: hero text (dark grey), important body (black), metadata (light grey) |
| **Output** | eInk framebuffer (packed 2-bit, 4 levels per pixel; 156,400 bytes for 920x680) |
| **Export** | PNG with 4-level grayscale mapping |

---

## Box Types (18 total)

| Category | Types | Data Source |
| --- | --- | --- |
| **Weather** | Current weather, hourly forecast (1–24h), daily forecast (1–20d) | Open-Meteo (free, no key) |
| **Environment** | Sunrise/sunset, air quality (AQI), UV index, pollen, moon phase  | Open-Meteo cloud data + local computation |
| **Personal** | Countdown, year progress, date | Local computation |
| **Content** | Quote, text | quotable mirror (free) / user input |
| **Utility** | QR code | User input |
| **Data** | Stocks | Yahoo Finance (free) |
| **Entertainment** | Horoscope, on this day | api-ninjas / Wikipedia |
| **Calendar** | Public holidays | Nager.Date (free, no key) |

The AQI, UV, and pollen boxes draw Open-Meteo cloud data — cloud data boxes like weather, not local sensor readings. Pollen is the one box with a regional limit: the upstream serves it for Europe during pollen season, and the box shows "No data" elsewhere rather than a misleading zero. All box types work without accounts, API keys, or subscriptions. The 5.76" panel hosts a multi-box bento dashboard (up to 10 boxes, depending on font size; multi-column) with big glanceable numbers. The hourly forecast is configurable from 1 to 24 hours and the daily forecast from 1 to 20 days (both default to 3). Quote and horoscope responses fall back to a bundled local set on upstream failure (≈50KB built-in).

---

## Web Editor

- Live preview (server-rendered PNG, landscape + portrait)
- Debounced auto-fetch for location-based boxes (500ms)
- Browser geolocation on first load (auto-detect user's city)
- Auto-fetch random quote on box add
- Configurable: font size (8-42px), corner radius (0-10), display padding (0-10)
- Show/hide box headers toggle
- Config persists in browser localStorage
- JSON import/export for portability
- No account required to build a layout (an account is required to claim a device)
- Deployed at infobento.com

---

## Power Budget

| Component | Active | Sleep | Duty |
| --- | --- | --- | --- |
| eInk full refresh | ≈25 mA | 0 mA | ≈0.75s full, ≈0.3s partial |
| Wi-Fi connect + frame fetch | ≈70 mA | ≈10 µA | ≈10–20s, per refresh |
| MCU active (during refresh) | ≈5 mA  | ≈5–10 µA | ≈15s, per refresh |
| Tilt switches | 0 | 0 | passive (orientation only) |

**Battery sizing:** ≈100 mAh LiPo plus solar harvest (5–15 mAh/day) covers the 1–3 refreshes/day display budget (default 3). With no always-on sensors, the only meaningful draw is the ESP32 radio during a refresh, which the panel sleeps between.

---

## User Classes

**Desk Decorator (primary):** Values aesthetic, minimal desk accessories. Wants a bento-box-sized eInk display showing a quote, countdown, weather, or QR code — standing on its own, solar-powered.

**Gift Giver / Daily Glancer (secondary):** Wants a thoughtful, personalized tech gift that works immediately, or ambient weather, schedule, and quotes visible without picking up a phone. Pre-configures via web UI.

---

## Competitive Positioning

| | Tidbyt / TRMNL | InfoBento |
| --- | --- | --- |
| **Display** | LED matrix / e-paper | Good Display GDEH0576T81, 5.76" eInk, 920×680, 198 DPI |
| **MCU** | ESP32 / ESP8266 / RP2040 class | ESP32-C3 controller |
| **Power** | Mains (Tidbyt) / 1800 mAh battery, recharge every 3–6 mo (TRMNL) | Solar-harvesting; no scheduled recharge |
| **Plugin/box** | DIY scripts or app marketplace | 18-box multi-box bento dashboard, up to 10 boxes |
| **Account** | App + account | Web page, no app; passkey/OAuth sign-in to claim |
| **Price** | $189 Tidbyt Gen 2 / $139 TRMNL OG | $109–129 (Kickstarter) |

InfoBento is a calmer, solar take on the ambient-display category: no wall cable, no app, no plugin marketplace — just a glanceable 5.76" eInk bento dashboard that refreshes itself on window light. Every tier undercuts the table on a per-unit basis — $109 early bird, $129 standard, and $119.50 each in the gift pair, against TRMNL's $139 as the closest comparable — though note InfoBento's panel is the smaller of the two (5.76" vs 7.5"), which is the trade a buyer is making.

Solar is the durable differentiator, and it is narrower than it first appears: TRMNL is battery-powered and runs 3–6 months per charge, so the honest claim is _never recharge_ versus _recharge twice a year_, not _cable-free_ versus _tethered_. Worth noting the closest competitor also has no subscription, so "no subscription" is table stakes here rather than a differentiator.

---

## Key Design Principles

1. **Multi-Box Bento Dashboard** — The 5.76" panel hosts a multi-box dashboard (up to 10 boxes, depending on font size; multi-column) with big glanceable numbers.
2. **Minimal Device Interaction** — No taps, no gestures, no screens to configure. The shipped firmware keeps two controls: the green button flips orientation, and holding the two white buttons for 5s factory-resets. Configure once at the web editor; the device just shows what matters.
3. **Pure Function Architecture** — Rendering is a pure function: same config in, same frame out (`POST /api/render`). ⚠️ Superseded in part by epic #77 — the API as a whole is no longer stateless; accounts, device pairings, and per-device config live in SQLite, and the device-facing path renders from stored config given only a device id.
4. **Free by Default** — All 18 dashboard box types work without accounts or API keys.
5. **Visual Restraint** — Four shades used with intention. Hero data, body text, and metadata each earn their contrast level.
6. **Web-Only Configuration** — Browser is the only config surface. No companion app.
7. **Solar-Powered Counter Display** — Monolithic white body, no hinge. Body stands on its own, with a fold-out kickstand to angle it.

---

## Open Items

- **Hardware validation** — Dev kit acquired and bench-proven (#57 closed): 4-level grey rendering validated on the reTerminal E1001. Remaining hardware step is sourcing the production GDEH0576T81 panel.
- **Grey fallback** — If 2-bit grey looks bad on hardware, Floyd-Steinberg dithering to 1-bit as fallback (#56).
- **Orientation auto-rotate** — Validate 2× ball-in-tube tilt switches drive reliable landscape/portrait detection.
- **Price validation:** the ≈$46.40 BOM is grounded in distributor listings for the panel, MCU, and harvester, but no volume quote has been obtained. It is the input the $109/$129 pricing depends on — if the panel quotes above ≈$32, revisit the tiers rather than absorbing it.
- **Certification + tooling NRE** — FCC/CE for a Wi-Fi device, UN38.3 for the lithium cell, and injection-mold tooling are unbudgeted. These are recovered from per-unit margin, which is why pricing at or near BOM does not work at any volume.
- **Firmware:** Captive portal provisioning, Wi-Fi connect, config poll, framebuffer write, and the deep-sleep cycle are all bench-verified — shipped as the integrated sketch (Phases 3–7, PR #174), including dual-orientation frame pull and the two-white-button factory reset.
- **Enclosure:** SCAD model (#199) for ≈14×11 cm housing, ≤4 mm bezel, solar cavity, fold-out kickstand.
- **Founder bio** — locked 2026-08-19. Career detail sourced from the founder's own resume; origin section built on minimal / simple / seamless.
- **Content-aware layout:** Height allocation for all 18 box types — shipped in v0.13.0 via `computeMinHeight` per renderer.

---

## Monorepo Structure

```
infobento.com/
  packages/core/      Types, layout engine, validation (Zod)
  packages/data/      Box-data providers (weather, quote, …) + cache
  packages/renderer/  eInk framebuffer generation
  packages/api/       Hono server (render API, auth/pairing, static files)
  packages/web/       Vite web editor (vanilla TS, no framework)
```

**Current version:** v0.38.3
**Tests:** 58 test files across `packages/*/src/**/*.test.ts`
**Quality gate:** `npm run build && npm test && npm run lint && npm run format:check`

---

_InfoBento — See what matters. Skip the spiral._

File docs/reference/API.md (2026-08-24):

# API Reference

The InfoBento API is a **Hono** HTTP server. The rendering endpoints below are stateless pure functions; the auth, pairing, and device-config endpoints added by epic #77 are backed by SQLite and are **not** documented here yet (see the endpoint-coverage note at the end). In production, it serves both API routes and the built web UI from a single port (default 4000).

## Design Principles

These describe the five endpoints documented below — three rendering endpoints (validate, render, preview) plus health and box-types — not the API as a whole:

1. **Pure functions** — Same input always produces same output
2. **No server state on the render path** — the config is supplied in the request body, not read from a database. This does **not** hold API-wide: the auth, pairing, and device-config endpoints added by epic #77 are backed by SQLite.
3. **Edge-deployable render path** — the rendering endpoints run unchanged on Node, Cloudflare Workers, Deno, or Bun. The stateful endpoints do not: `better-sqlite3` is a native module, so they are Node-bound as written.
4. **Binary output** — Frame buffers are packed 2-bit-per-pixel arrays (4 pixels per byte, 4 levels per pixel)
5. **Same-port serving** — API + static web UI from one server (like phasebot)

## Running

```bash
# Development (API only, Vite proxies /api)
npm run dev -w @infobento/api     # tsx watch on :4000

# Production (API + static web UI)
npm run build
npm start -w @infobento/api       # Hono on :4000
```

## Endpoints

### GET /api/health

Health check endpoint.

**Response:** `{ status: "ok", version: "<package version>" }` — e.g. `"0.38.3"`.

The version is read at **server startup**, not at build time: `server.ts` resolves
`../package.json` relative to the compiled entrypoint and `readFileSync`s it. A
deployment that ships `dist/` without the adjacent `package.json` therefore fails
at startup rather than falling back to a default.

### GET /api/box-types

List available bento box types.

**Response:** Array of `{ type, label, requiresAuth }` objects. Currently returns a
hardcoded subset — 8 of the 18 box types — with no configuration options; the
drift is tracked in #240.

### POST /api/validate

Validate a bento config without rendering.

**Request:** `BentoConfig` JSON
**Response:** `{ valid: boolean, errors: { path, message }[] }`

### POST /api/render

Render a bento config into a binary frame buffer.

**Request:** `BentoConfig` JSON
**Response:** Binary frame buffer (156,400 bytes for 920x680, packed 2-bit, 4 levels)
**Headers:** `X-Frame-Width`, `X-Frame-Height`

### POST /api/preview

Render a bento config into a PNG preview image. Supports an optional `scale` query parameter for upscaling (default: 3). `scale` must be an integer from 1 to 8 — anything else is a 400.

**Request:** `BentoConfig` JSON
**Query:** `?scale=N` (integer 1–8, optional, default 3); `?dual=1` (optional)
**Response:** PNG image (`image/png`)

With `?dual=1` the response is JSON instead of a PNG: `{ landscape, portrait, landscapeIds, portraitIds }` — both orientations as base64-encoded PNGs plus the box ids rendered in each.

---

## Endpoint coverage

⚠️ **This reference documents 5 of the API's 28 routes.** The five above are the stateless
endpoints — three rendering endpoints plus health and box-types. Undocumented, all added
after this file was written:

| Group | Routes |
| --- | --- |
| Auth — passkey | `POST /api/auth/passkey/{register,login}/{options,verify}` |
| Auth — OAuth | `GET /api/auth/oauth/:provider/{start,callback}` |
| Auth — session | `GET /api/auth/session`, `POST /api/auth/signout` |
| Pairing | `POST /api/pair` |
| Account | `GET /api/me/devices`, `GET /api/me/device/:id/config` (session-gated), `DELETE /api/device/:id/owner` |
| Device (firmware-facing) | `GET /api/device/:id/{config,frame,frames}`, `PUT /api/device/:id/config`, `POST /api/device/:id/forget` |
| Rendering | `POST /api/render-dual` |
| Data proxies | `GET /api/{quote,horoscope,stocks,onthisday,geolocate}` |

Authoritative source is `packages/api/src/server.ts`. Documenting these matters most for
self-hosters, since the auth env vars in the README are useless without the routes they
configure. Tracked as follow-up work.

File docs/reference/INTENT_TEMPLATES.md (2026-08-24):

# Intent Documentation Templates

Templates for adding intent-driven inline documentation throughout the codebase.

## Module/File Header Template

Use at the top of each module to explain its purpose:

```typescript
/**
 * Intent: [Why this module exists - 1 sentence]
 * Context: [Where it's called from, dependencies]
 * Pattern: [Key architectural pattern used]
 * Future: [Known limitations or planned improvements]
 */
```

### Example

```typescript
/**
 * Intent: Convert bento box layouts into eInk-compatible frame buffers
 * Context: Called by @infobento/api to generate display data sent to the device
 * Pattern: Pure functions — all rendering is deterministic with no side effects
 * Future: Add partial refresh and per-box refresh cadence
 */
```

## Function/Method Rationale Template

Use for complex functions or non-obvious design decisions:

```typescript
/**
 * intent: [Why this function exists]
 * method: [How it accomplishes the goal - high level]
 * effect: [Measurable impact or performance characteristic]
 * context: [Where it's used in the system]
 */
```

### Example

```typescript
/**
 * intent: Create an empty (white) frame buffer for the target display
 * method: Allocates a Uint8Array sized for 2-bit-per-pixel packing (4 pixels/byte)
 * effect: (width * height) / 4 bytes — 156,400 bytes for 920x680
 */
```

## Inline Decision Comments

Use for tradeoffs and constraints:

```typescript
// tradeoff: [decision made] because [constraint/goal]
// constraint: [limitation that shapes the solution]
// future: [known tech debt or planned improvement]
```

### Examples

```typescript
// tradeoff: 2-bit (4 levels) for minimal power draw during refresh
// constraint: frame is 156,400 bytes; the device pulls it over HTTPS in one GET
// future: add partial refresh to update only changed bento boxes
```

## Semantic Tags Reference

- **`intent:`** — Why something exists (purpose, problem being solved)
- **`method:`** — How it works (high-level approach)
- **`effect:`** — Measurable impact (performance, power, correctness)
- **`context:`** — Where it fits in the system (dependencies, callers)
- **`tradeoff:`** — What was sacrificed for what gain
- **`constraint:`** — What limits the solution space
- **`future:`** — Known tech debt or planned improvements
- **`pattern:`** — Architectural pattern used (pure function, observer, etc.)

## Quick Start

### Adding Intent Headers to Existing Files

1. Read the file to understand its purpose
2. Fill out the module header template
3. Add inline decision comments for non-obvious code
4. Keep it concise — aim for 3-5 lines per header

### Creating New Files

1. Start with the module header template
2. Add intent comments before complex functions
3. Document tradeoffs inline as you make decisions

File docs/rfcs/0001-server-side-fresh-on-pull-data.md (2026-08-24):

# RFC 0001 — Server-side fresh-on-pull data resolution

| | |
| --- | --- |
| **Status** | Implemented — shipped as `@infobento/data` + pull-time hydration (PRs #138–#151) |
| **Issue** | [#135](https://github.com/jasoneplumb/infobento.com/issues/135) |
| **Author** | jasoneplumb |
| **Created** | 2026-06-19 |
| **Supersedes / relates** | client-side fetching #55, #58; fresh-on-fetch box types #62 (#59/#60/#61) |

## Summary

Move live box-data fetching (weather, forecast, AQI, stocks, sun/moon, quote, joke,
horoscope, on-this-day) from **the web editor at edit time** to **the API at
device-pull time**, so a device shows current data on each scheduled refresh
without anyone re-opening the editor. The render pipeline and the device firmware
are unchanged; the work is a new shared data layer, a hydrate step in the frame
handler, a cache, and a freshness rule that still respects the deep-sleep budget.

## Motivation

Today data is resolved **client-side** and baked into `config_json` as a snapshot:

- `packages/web/src/api.ts` resolves data two ways: **5 boxes call external
  providers directly from the browser** — weather/forecast/forecast3d/sun/aqi via
  Open-Meteo + Nominatim — and **5 call the Hono API's own proxy routes** —
  joke/horoscope/onthisday/quote/stocks hit `/api/{joke,horoscope,onthisday,quote,
stocks}` (`server.ts:186,235,285,320,375`), whose real provider logic + bundled
  quota fallbacks already live server-side in `api/src/server.ts` and
  `api/src/fallback/`.
- On save, `PUT /api/device/:id/config` stores the resolved values. The box configs
  literally carry the data — `WeatherBoxConfig.data?`, `ForecastBoxConfig.entries?`
  (`packages/core/src/types.ts:24,49`).
- `getDeviceFrameForPull` (`packages/api/src/device.ts:67`) just `JSON.parse`s the
  config and calls `renderBoth(config)` — it draws whatever was baked in.
- `Last-Modified` = `devices.last_modified`, bumped **only** by `setConfig`
  (`packages/api/src/db.ts:252`). So a polling device gets `304 → skip` forever
  until someone edits the config.

**Net:** the display is a static snapshot of the last edit. A device left alone
shows day-old weather.

## Goals

- On each scheduled refresh (production cadence ~1–2×/day), live boxes show current
  data, no manual edit.
- The renderer stays pure (data in → pixels out); no network in `@infobento/renderer`.
- Upstream providers hit at most once per cache window regardless of device count.
- A provider outage never strands the panel — always return a drawable frame.
- The Phase 4 `304`-skip still protects the solar/battery budget between windows.

## Non-goals

- Real-time / streaming / sub-refresh freshness.
- Changing the eInk cadence or the deep-sleep/RTC model.
- Removing the editor's fetching — it stays for live previews.

## Detailed design

### Key enabler: the schema is already split

The box configs already separate **user params** from **resolved data**:

```ts
interface WeatherBoxConfig {
  type: 'weather';
  city: string;
  lat?: number;
  lon?: number;
  data?: WeatherData;
}
interface ForecastBoxConfig {
  type: 'forecast';
  city: string;
  lat?: number;
  lon?: number;
  hours?: number;
  entries?: readonly ForecastEntry[];
}
```

`data?`/`entries?` are optional. So the change is: instead of the **web client**
populating them and persisting them, the **API** populates them at render time
from params. Minimal schema churn — mostly making the optionality the contract
("params are authored; data is server-resolved").

### 1. `@infobento/data` — shared provider package

Consolidate provider logic into a new pure package. **The extraction is
asymmetric** — the 10 fetchers split by where their real logic lives today:

- **5 direct fetchers** (`fetchWeather`, `fetchForecast`, `fetchForecast3D`,
  `fetchSunTimes`, `fetchAirQuality`) call Open-Meteo/Nominatim straight from the
  browser. These move from `web/src/api.ts` into `@infobento/data` as a near-pure
  lift.
- **5 proxy fetchers** (`fetchJoke`, `fetchHoroscope`, `fetchOnThisDay`,
  `fetchQuote`, `fetchStocks`) are thin `fetch('/api/…')` wrappers; their provider
  logic is in `server.ts` handlers + `api/src/fallback/`. The `api` package **cannot
  call its own HTTP routes** for hydration, so the underlying logic must be pulled
  out of those handlers into `@infobento/data`. The `server.ts` routes then become
  thin wrappers over `@infobento/data` (exactly what the web editor calls), and
  `hydrateConfig` calls `@infobento/data` directly. The `fallback/` quota-fallback
  data follows the logic into `@infobento/data` (or stays in `api` as an explicit
  fallback layer above it — decide during Step 1).

So Step 1 is **not** a uniform "pure move": only the 5 direct fetchers are
behavior-neutral; the 5 proxy ones require restructuring `server.ts` (logic out,
routes become wrappers) to avoid a second copy of the provider code.

Requirements:

- No DOM/`window`; `fetch` only (Node 18+, edge runtimes, and the browser all
  provide global `fetch`).
- Keep the existing **return-`null`-on-failure** contract — it's already the
  resilience primitive we need.
- `web` imports it for editor previews; `api` imports it for pull-time hydration
  **and** for its (now thin) proxy routes.

**Module boundary update** (CLAUDE.md): `data` imports nothing from siblings;
`api` and `web` may import `data`. `core` stays leaf.

### 2. Hydration at `GET /frame`

Add a `hydrateConfig(config, deps): Promise<BentoConfig>` step in
`getDeviceFrameForPull`, before `renderBoth`:

```
getDevice → parse config_json → hydratedConfig = await hydrateConfig(config) → renderBoth(hydratedConfig) → frame
```

`hydrateConfig` walks the boxes; for each live box it resolves data from
`@infobento/data` (via the cache, §4) and produces a box that carries the fresh
`data`/`entries`. **Box config fields are `readonly` (`core/src/types.ts`)**, so
this is an immutable transform — `hydrateConfig` returns a **new** `BentoConfig`,
spreading/reconstructing each box that gains data, rather than mutating in place.
It takes an injected resolver so it stays unit-testable.

Which boxes need the network: live boxes are weather, forecast, forecast3d,
**sun** (sunrise/sunset via `fetchSunTimes` → Nominatim + Open-Meteo), aqi, stocks,
quote, joke, horoscope, on-this-day. Genuinely static/computed — no network —
are text, countdown, qr, date, and **moon** (phase is computed from the UTC date
alone).

**Invariant — always replace, never fill-absent.** For every live box,
`hydrateConfig` unconditionally reconstructs the box with fresh `data`/`entries`
from the cache/fetcher, regardless of whether a seed is already present. A
`if (!box.data) …` fill-absent-only implementation would silently keep stale baked
data when a seed exists in `config_json` — the exact bug this RFC exists to kill.
Persisted `config_json` holds **params only**; baked `data`/`entries` is a
discardable seed. (Open question: strip `data` on `PUT` to keep rows small, vs.
ignore-and-overwrite on read. Lean: overwrite on read, strip opportunistically.)

### 3. Caching

A TTL cache keyed by `(provider, normalized-params)` — e.g.
`weather:lat,lon,units` — shared across all devices, so 1,000 devices in the same
city cause one upstream call per window. Per-provider TTLs (weather ~30–60 min,
on-this-day/horoscope ~24 h, stocks ~15 min). Stale-while-revalidate so a slow
upstream never blocks a frame.

**Single-flight (thundering herd).** Devices on the same cadence wake nearly
simultaneously, so at a bucket boundary every concurrent request for the same key
sees an expired entry and fires its own upstream call before any refresh lands.
Stale-while-revalidate alone doesn't fix this. The `Cache` interface must do
**promise deduplication**: if a refresh is already in-flight for a key, later
callers await the same `Promise`.

Per-key dedup is necessary but **not sufficient** for Nominatim, which enforces
1 req/sec (`web/src/api.ts:35`) and backs five fetchers. Devices in N different
cities produce N distinct geocode keys that all cache-miss at a boundary — dedup
doesn't apply across keys, so the herd still exceeds 1 req/sec. `@infobento/data`
needs a **Nominatim-global serial queue / rate limiter** in addition to per-key
dedup: per-key for the same-city case, global throttle for the cross-key case.
(Caching resolved coordinates aggressively — geocodes rarely change — also shrinks
the problem.)

**Edge concern:** the API is designed stateless/edge-deployable (Cloudflare/Deno/
Bun). In-process Map cache works for a single Node host now; a durable shared cache
(Workers KV / Deno KV / Redis) is needed if/when horizontally scaled. Phase the
durable cache; ship in-process first behind a small `Cache` interface (single-flight
included from day one).
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

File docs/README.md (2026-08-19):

# Documentation

> _See what matters. Skip the spiral._

Most documentation lives **inline with the code** using intent headers (see [INTENT_TEMPLATES.md](reference/INTENT_TEMPLATES.md)). This directory contains the reference docs you'll need alongside the source.

---

## Where to Start

### New Contributors

1. [Setup](getting-started/SETUP.md) — clone, install, verify
2. [Architecture](getting-started/ARCHITECTURE.md) — system design and data flow
3. [Development](getting-started/DEVELOPMENT.md) — workflows and conventions
4. [Contributing](../CONTRIBUTING.md) — PR guidelines

### Documentation Writers

1. [Intent Templates](reference/INTENT_TEMPLATES.md) — inline documentation standard

---

## Documentation Map
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

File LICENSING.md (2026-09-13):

# Licensing

InfoBento is open-source hardware. Different parts of this repository are
released under different licenses, each chosen for the kind of work it covers.
**All three permit commercial use, including manufacturing and selling devices
based on this design.**

| Part of the repo | License | SPDX identifier  |
| --- | --- | --- |
| Software (`packages/`, `scripts/`, repo root) | Apache License 2.0 | `Apache-2.0` |
| Hardware design files (`hardware/`) | CERN Open Hardware Licence v2 — Permissive | `CERN-OHL-P-2.0` |
| Documentation (`docs/`) | Creative Commons Attribution 4.0 | `CC-BY-4.0` |

License texts:
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

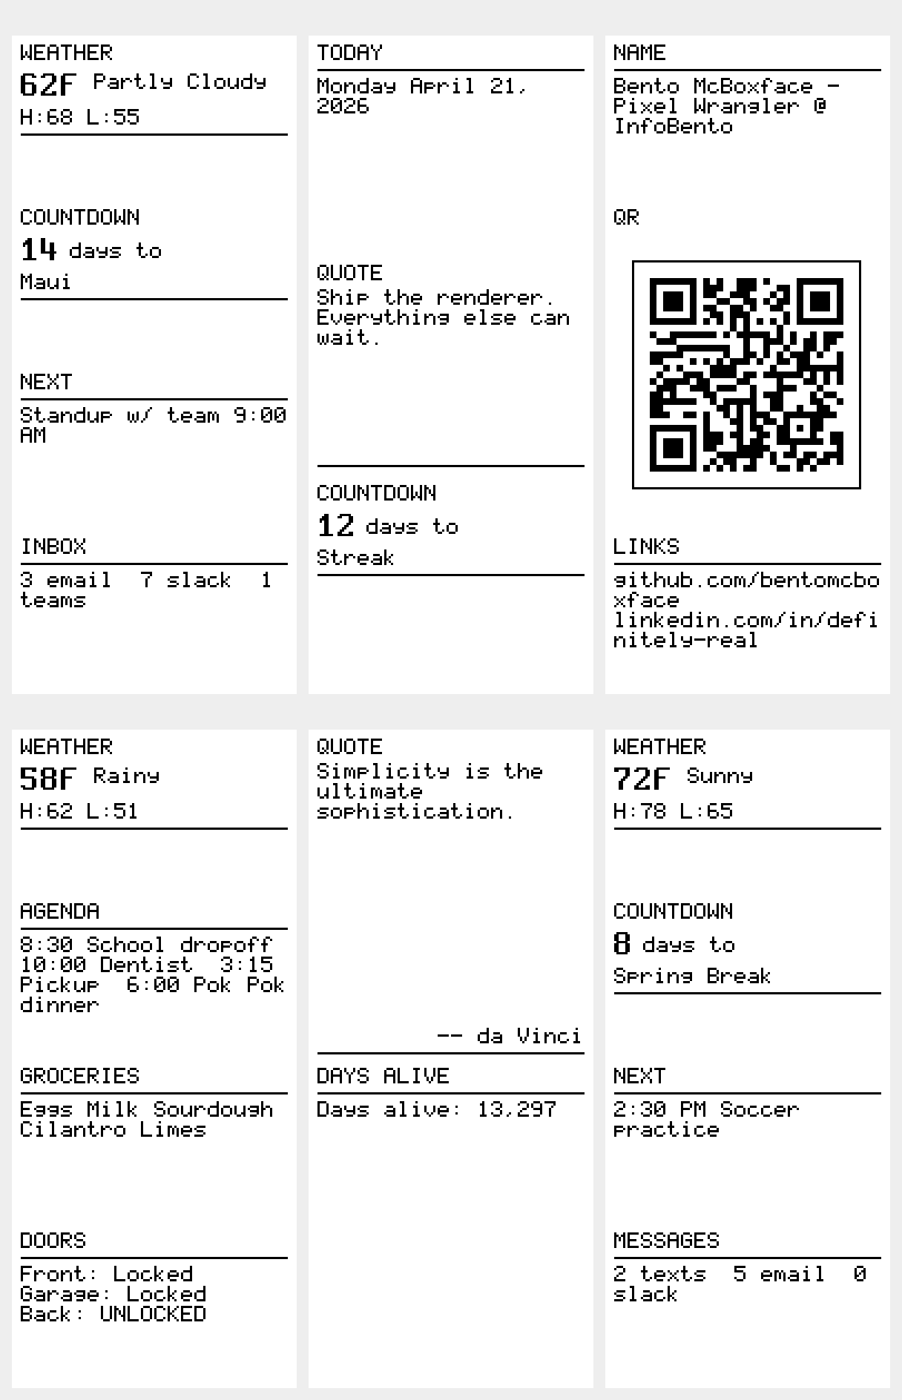
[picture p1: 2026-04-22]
preview.png

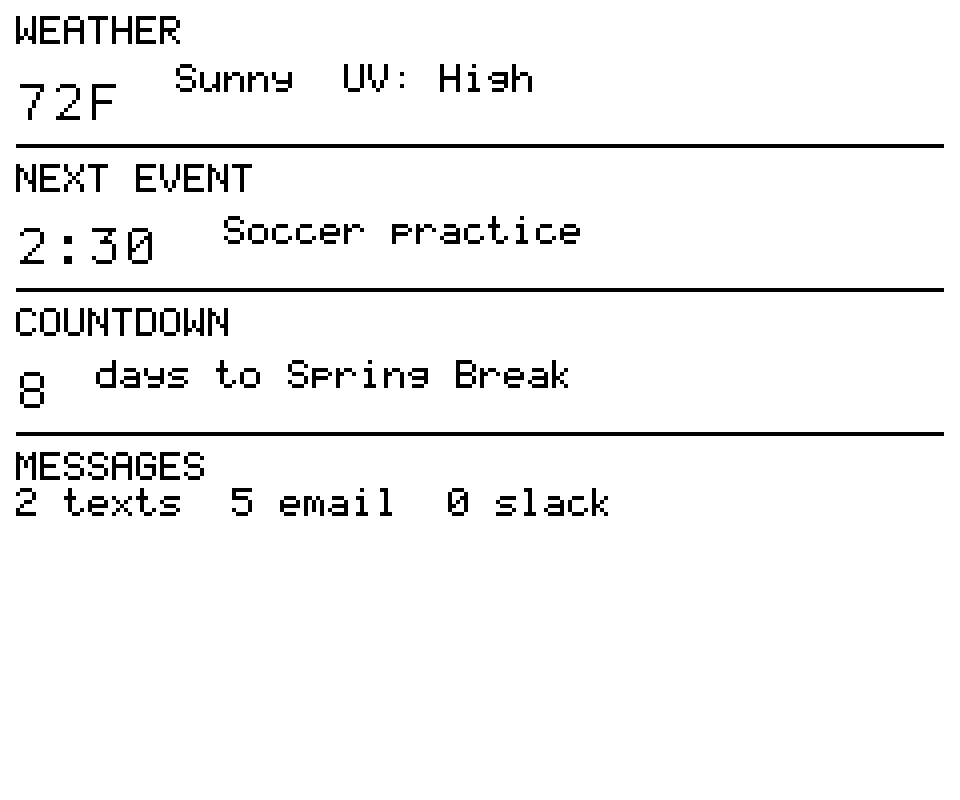
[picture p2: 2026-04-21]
previews/F-tamzen-8x16.png

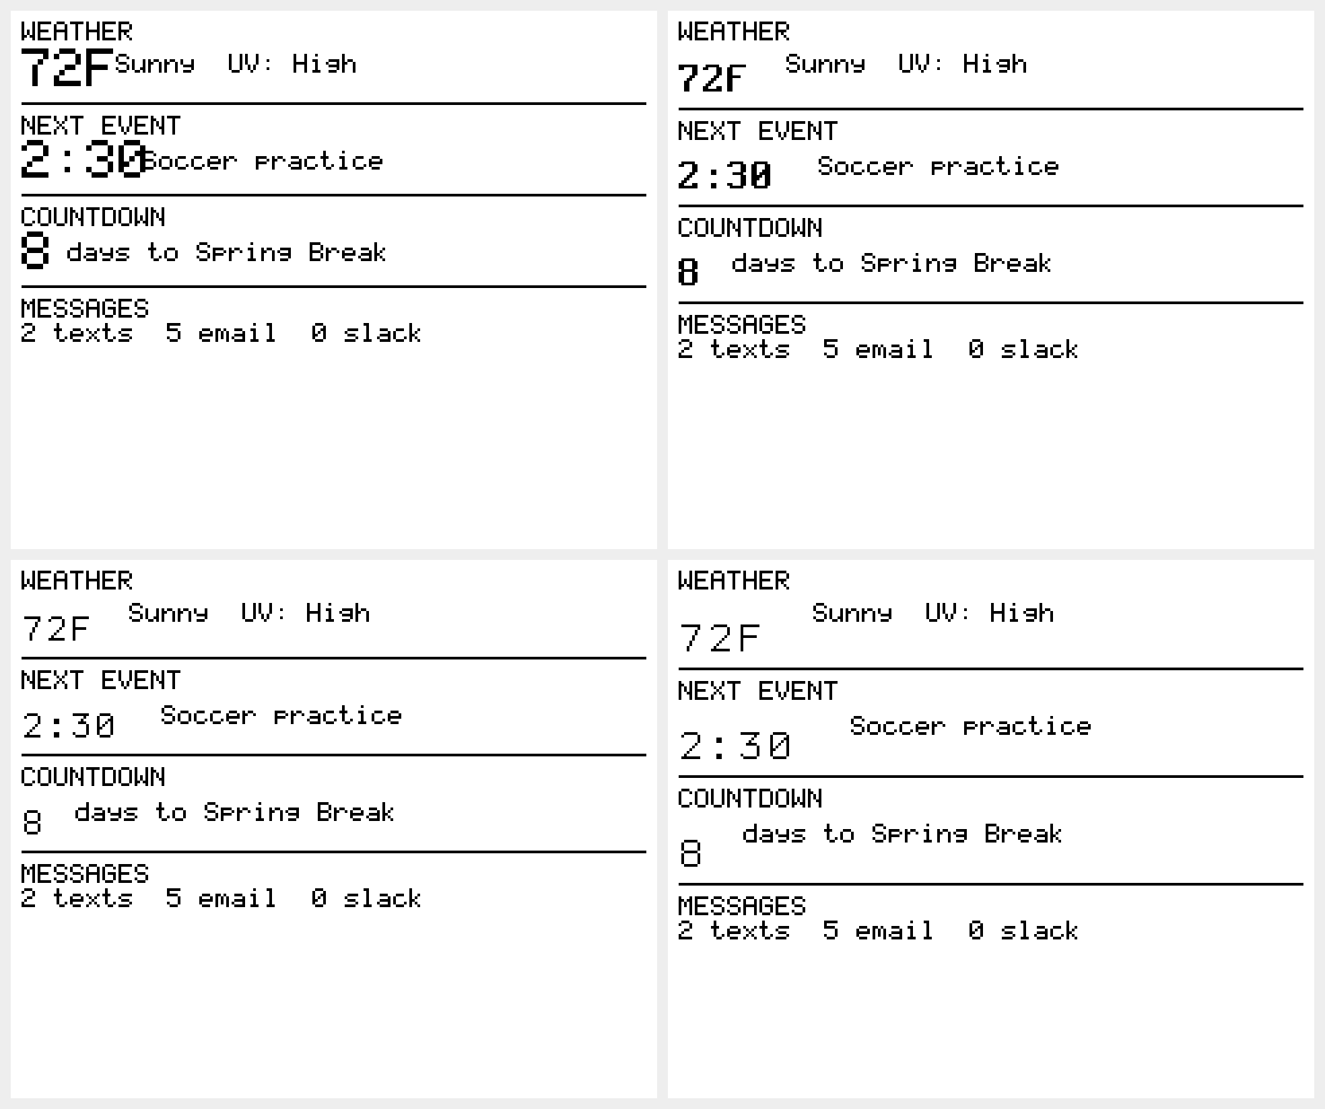
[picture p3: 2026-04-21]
previews/F-font-comparison.png

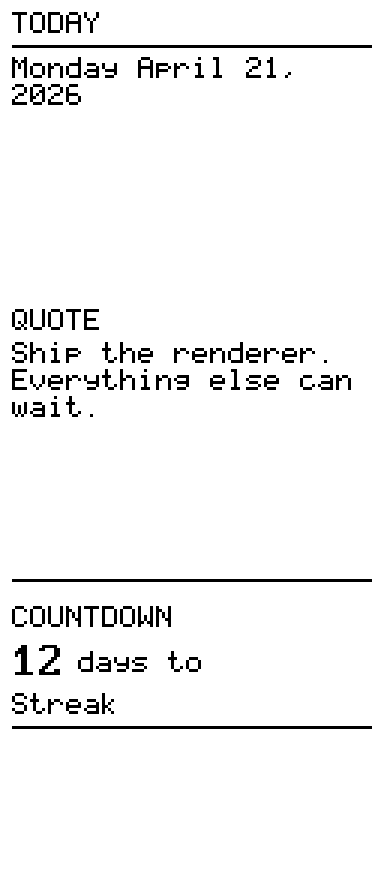
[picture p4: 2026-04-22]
previews/B-desk.png

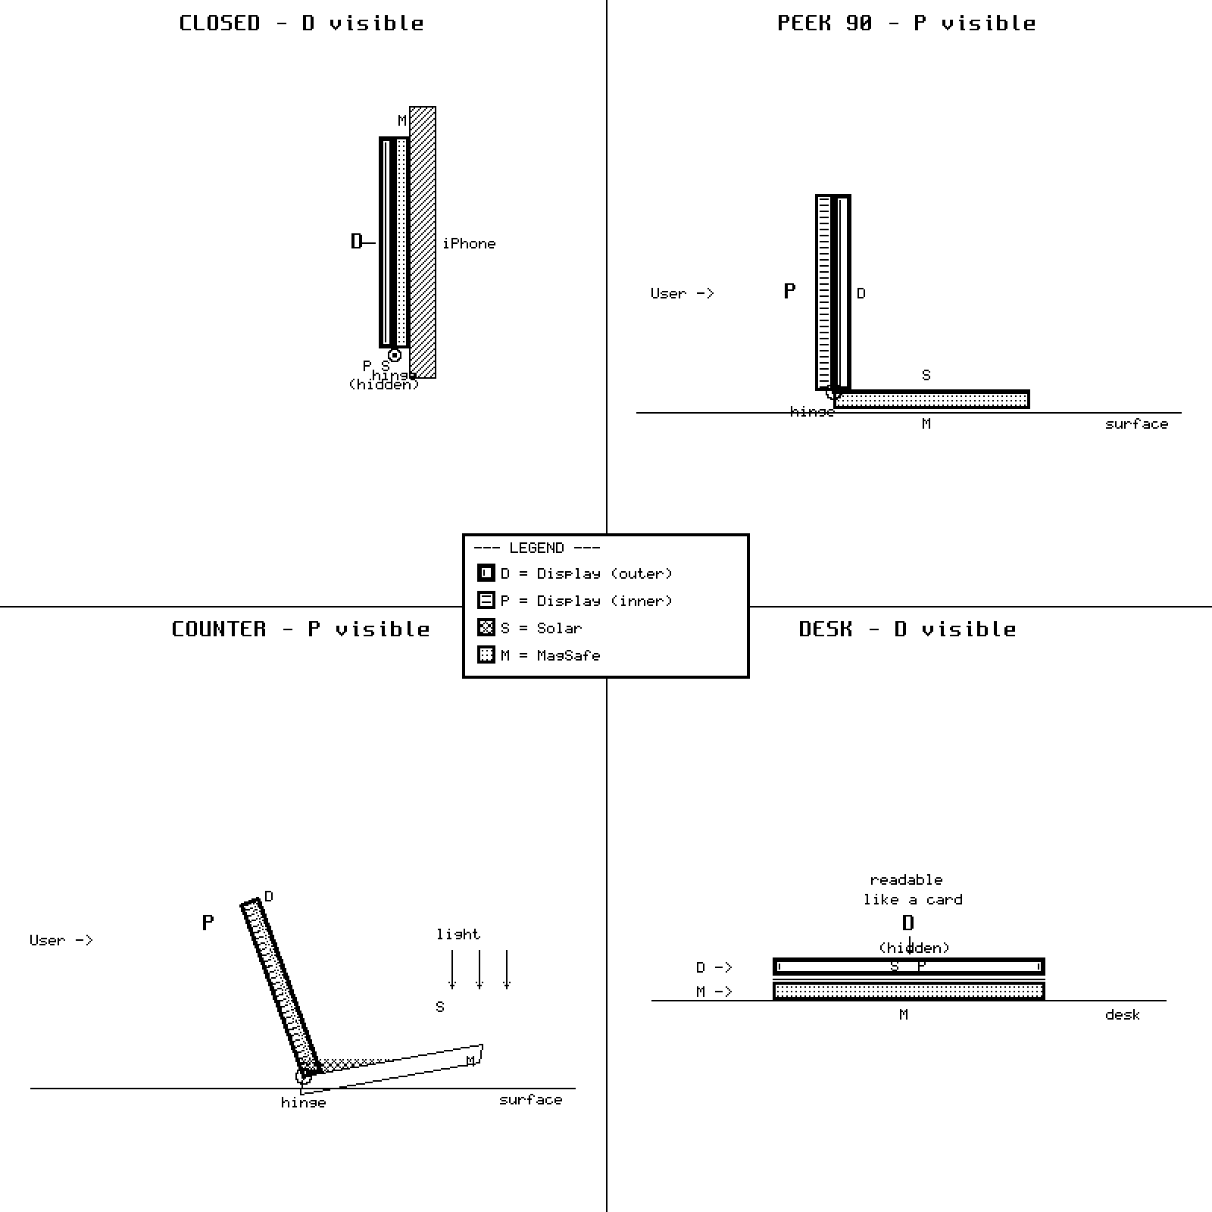
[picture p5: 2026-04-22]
previews/dual-display-modes.png

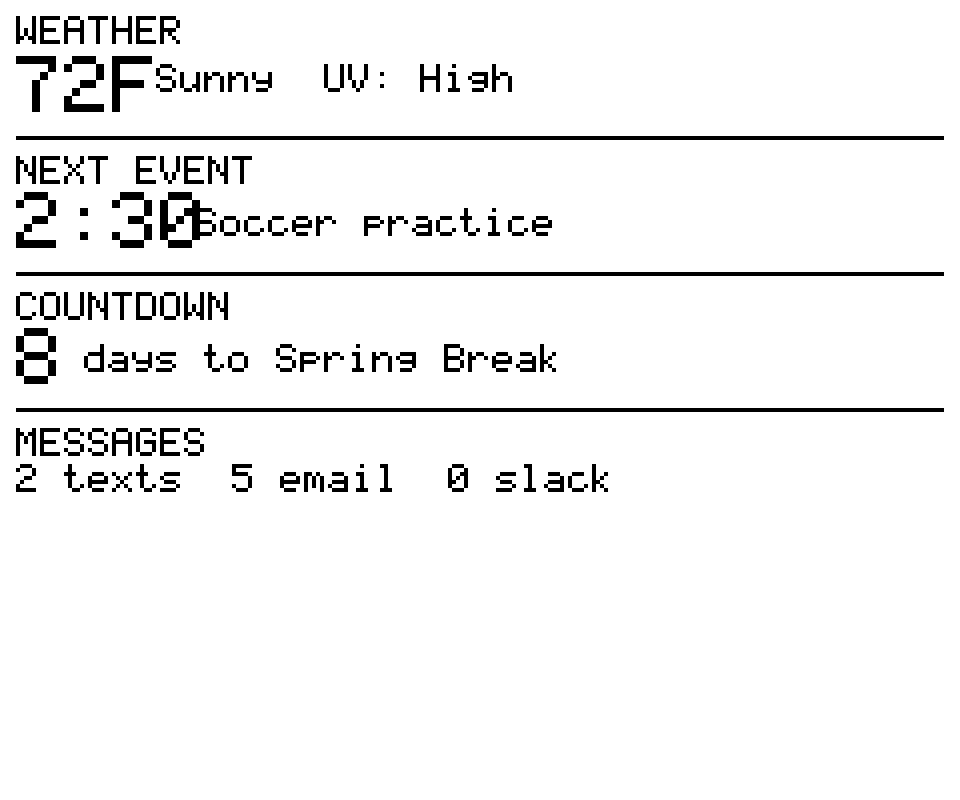
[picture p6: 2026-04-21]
previews/F-baseline-2x5x7.png

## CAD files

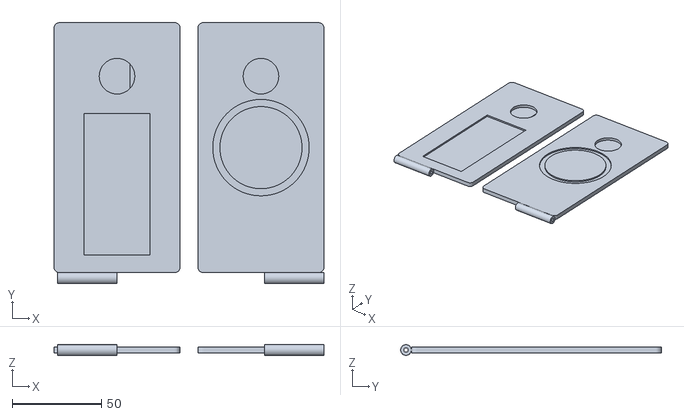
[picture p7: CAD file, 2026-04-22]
hardware/infobento001.stl
151.2 x 146.0 x 6.02

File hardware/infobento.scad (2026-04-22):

// InfoBento Dual-Display Clamshell Mockup
// For 3D printing (FDM, PLA/PETG) via PCBWay
// Units: millimeters
//
// Two halves connected by a hinge channel along the short edge.
// Print each half separately, connect with a Reell TI-C5M hinge
// or a simple pin hinge for the mockup.
//
// Display half: 3.2mm — two full-size eInk panels back-to-back + ESP32-C3
// Battery on solar half — avoids grip flex stress on the LiPo cell.
// Power routed through hinge FPC (2 wires, ~100mA, proven safe).

// === Device dimensions ===
device_width = 70.6;      // Short edge (matches iPhone 15 Pro width)
device_height = 140;       // Long edge (slightly shorter than iPhone)
corner_radius = 3;         // Rounded corners

// === Display half ===
display_half_thickness = 3.2;  // 1.2mm D panel + 0.8mm PCB + 1.2mm P panel

// eInk panel recesses (both sides)
panel_width = 37;          // 2.9" panel short dimension (portrait)
panel_height = 79;         // 2.9" panel long dimension
panel_depth = 1.2;         // Glass panel thickness
panel_x_offset = (device_width - panel_width) / 2;  // Centered horizontally
panel_y_offset = 10;       // Offset from hinge edge

// ESP32-C3-MINI-1 recess (between panels, beside eInk area)
// Positioned at board edge for antenna clearance from MagSafe metal
esp_width = 13.2;
esp_height = 16.6;
esp_depth = 2.4;
esp_x_offset = 5;          // Near board edge for antenna clearance
esp_y_offset = panel_y_offset + panel_height + 5;

// === Solar half ===
// Battery lives here — mechanically isolated from hand-grip forces
// GM251534: 2.5mm thick, 100mAh, 15x34mm
battery_width = 15;
battery_height = 34;
battery_depth = 2.5;
battery_x_offset = 4;
battery_y_offset = 15;

// Thicker to accommodate battery between solar panel and MagSafe/Qi layers
solar_half_thickness = 4.0;  // 0.8 PCB + 2.5 battery + 0.5 solar + 0.2 margin

// Solar panel recess (inner face, S-side)
solar_width = device_width - 8;   // Nearly full width
solar_height = 100;
solar_depth = 0.5;                 // Shallow recess for thin film
solar_x_offset = 4;
solar_y_offset = 15;

// MagSafe ring recess (outer face, M-side)
magsafe_od = 54;
magsafe_id = 46;
magsafe_depth = 1.0;       // Recess for magnet ring
magsafe_center_x = device_width / 2;
magsafe_center_y = device_height / 2;

// === Hinge ===
hinge_diameter = 6;         // Barrel diameter for pin hinge
hinge_length = device_width - 4;  // Slightly shorter than device width
hinge_pin_diameter = 2.5;  // Pin that connects the two halves

// === Weight insert holes (simulate battery/PCB mass) ===
// Use coins or steel washers — 20mm diameter, 2mm deep
weight_hole_diameter = 20;
weight_hole_depth = 2;

// === Modules ===

module rounded_rect(w, h, t, r) {
    // Rounded rectangle as a hull of 4 cylinders
    hull() {
        translate([r, r, 0]) cylinder(h=t, r=r, $fn=32);
        translate([w-r, r, 0]) cylinder(h=t, r=r, $fn=32);
        translate([r, h-r, 0]) cylinder(h=t, r=r, $fn=32);
        translate([w-r, h-r, 0]) cylinder(h=t, r=r, $fn=32);
    }
}

module hinge_barrel(is_left=true) {
    // Half-barrel with pin hole
    difference() {
        // Barrel
        translate([0, 0, 0])
            rotate([0, 90, 0])
                cylinder(h=hinge_length/2, d=hinge_diameter, $fn=32);
        // Pin hole
        translate([-1, 0, 0])
            rotate([0, 90, 0])
                cylinder(h=hinge_length/2 + 2, d=hinge_pin_diameter, $fn=24);
    }
}

// === Display Half ===
module display_half() {
    difference() {
        // Main body
        rounded_rect(device_width, device_height, display_half_thickness, corner_radius);

        // D-side panel recess (top face, outer display)
        translate([panel_x_offset, panel_y_offset, display_half_thickness - panel_depth])
            cube([panel_width, panel_height, panel_depth + 0.1]);

        // P-side panel recess (bottom face, inner display)
        translate([panel_x_offset, panel_y_offset, -0.1])
            cube([panel_width, panel_height, panel_depth + 0.1]);

        // ESP32 recess (between panels, near board edge for antenna)
        translate([esp_x_offset, esp_y_offset, display_half_thickness/2 - esp_depth/2])
            cube([esp_width, esp_height, esp_depth]);

        // Weight insert hole (D-side, for mockup mass simulation)
        translate([device_width/2, device_height - 30, display_half_thickness - weight_hole_depth])
            cylinder(d=weight_hole_diameter, h=weight_hole_depth + 0.1, $fn=32);
    }

    // Hinge barrel (at y=0 edge, left side)
    translate([2, -hinge_diameter/2, display_half_thickness/2])
        hinge_barrel(true);
}

// === Solar Half ===
module solar_half() {
    difference() {
        // Main body
        rounded_rect(device_width, device_height, solar_half_thickness, corner_radius);

        // Solar panel recess (inner face, S-side, bottom)
        translate([solar_x_offset, solar_y_offset, -0.1])
            cube([solar_width, solar_height, solar_depth + 0.1]);

        // Battery recess (internal, between solar panel and MagSafe layers)
        // Mechanically isolated from grip forces — solar half is never squeezed
        translate([battery_x_offset, battery_y_offset, solar_half_thickness/2 - battery_depth/2])
            cube([battery_width, battery_height, battery_depth]);

        // MagSafe ring recess (outer face, M-side, top)
        translate([magsafe_center_x, magsafe_center_y, solar_half_thickness - magsafe_depth]) {
            difference() {
                cylinder(d=magsafe_od, h=magsafe_depth + 0.1, $fn=64);
                translate([0, 0, -0.1])
                    cylinder(d=magsafe_id, h=magsafe_depth + 0.3, $fn=64);
            }
        }

        // Weight insert hole (M-side)
        translate([device_width/2, device_height - 30, solar_half_thickness - weight_hole_depth])
            cylinder(d=weight_hole_diameter, h=weight_hole_depth + 0.1, $fn=32);
    }

    // Hinge barrel (at y=0 edge, right side)
    translate([device_width/2 + 2, -hinge_diameter/2, solar_half_thickness/2])
        hinge_barrel(false);
}

// === Assembly view ===
// Lay both halves side by side for printing, or use the closed view

// Print layout: both halves flat, separated
module print_layout() {
    display_half();
    translate([device_width + 10, 0, 0])
        solar_half();
}

// Closed view: stacked (for visualization)
module closed_view() {
    display_half();
    translate([0, 0, display_half_thickness + 0.5])
        mirror([0, 0, 1])
            translate([0, 0, -solar_half_thickness])
                solar_half();
}

// === Render ===
// Uncomment the view you want:

print_layout();      // For 3D printing — two halves side by side
// closed_view();    // For visualization — stacked as if closed

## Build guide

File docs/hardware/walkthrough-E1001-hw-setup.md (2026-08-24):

# reTerminal E1001 — Hardware Setup Walkthrough

> _Companion to [FIRMWARE_BRINGUP.md](FIRMWARE_BRINGUP.md). Records the **actual,
> verified** bench setup for bringing up InfoBento firmware on the Seeed
> reTerminal E1001 (7.5" 800×480, ESP32-S3, 4-level grayscale). Commands here
> were run and confirmed on a macOS host — not theoretical._

## Bench facts (this rig)

| Thing | Value |
| --- | --- |
| Host | macOS (Apple Silicon) |
| Device port | `/dev/cu.usbserial-1430` — a **USB-UART bridge** (CP210x/CH34x class), _not_ native USB CDC (`cu.usbmodem`) |
| Board profile (FQBN) | `esp32:esp32:esp32s3` ("ESP32S3 Dev Module") — no dedicated E1001 profile exists; this is what Seeed's own docs select |
| Toolchain | `arduino-cli` 1.5.1 in `~/.local/bin` |
| ESP32 core | `esp32:esp32` 3.3.8 (shared with the Arduino IDE via `~/Library/Arduino15`) |
| eInk library | `GxEPD2` 1.6.9 (+ `Adafruit GFX` 1.12.6 dependency) |

## Gotchas (learned the hard way)

1. **Upload speed.** The default `921600` baud **fails** over this UART bridge —
   sync succeeds and the stub flasher runs, then "chip stopped responding" mid-write.
   Flash at **`115200`** instead: `--fqbn esp32:esp32:esp32s3:UploadSpeed=115200`.
2. **Serial routing.** With the esp32 core's default **`CDCOnBoot=Disabled`**,
   `Serial` goes to **UART0 → the bridge** (this `cu.usbserial` port). If you flip
   the board option to "USB CDC On Boot: Enabled", `Serial` moves to the native USB
   port (`cu.usbmodem*`) and your prints vanish from the bridge port.
3. **Don't `cat` the raw port to read serial.** A bare `cat /dev/cu.usbserial-*`
   holds **DTR/RTS asserted**, which on the ESP32-S3 auto-reset circuit can pin
   GPIO0 low and trap the chip in the ROM bootloader (no app output). Use
   `arduino-cli monitor` — it manages DTR/RTS so the app actually runs.
4. **The dev API binds loopback by default.** `npm run dev -w @infobento/api`
   listens on **`127.0.0.1:4000`**, so the device (on Wi-Fi) can't reach it and a
   LAN `curl http://<mac-ip>:4000/…` returns `000`. Start it with **`HOST=0.0.0.0`**
   to bind all interfaces: `HOST=0.0.0.0 npm run dev -w @infobento/api`. macOS may
   prompt to allow incoming connections for `node` — allow it. (The device must also
   be on the **same 2.4 GHz** SSID — the ESP32-S3 has no 5 GHz radio.)
5. **Point the API at the right DB.** The server opens
   `/var/lib/infobento/data.db` by default, but a bench device is usually minted into
   a local `dev.db`. If `/frame` returns `404` for a known-good device id, the API is
   on the wrong DB — start it with **`INFOBENTO_DB_PATH=…/dev.db`**. To confirm which
   device ids exist: `sqlite3 dev.db "SELECT id, CASE WHEN config_json IS NULL THEN
'no-config' ELSE 'ok' END FROM devices;"`.

## Phase 0 — prerequisites (host side) ✅

```bash
# arduino-cli (standalone, into a dir already on PATH)
mkdir -p ~/.local/bin
curl -fsSL https://raw.githubusercontent.com/arduino/arduino-cli/master/install.sh \
  | BINDIR="$HOME/.local/bin" sh

# ESP32 core (skip if the Arduino IDE already installed it — it's shared)
arduino-cli core list | grep esp32 || {
  arduino-cli config init
  arduino-cli config add board_manager.additional_urls \
    https://espressif.github.io/arduino-esp32/package_esp32_index.json
  arduino-cli core update-index
  arduino-cli core install esp32:esp32
}

# eInk library (+ Adafruit GFX pulled automatically)
arduino-cli lib install GxEPD2
```

## Phase 1 — toolchain + blink ✅ (serial verified)

Sketch: [`firmware/blink/blink.ino`](../../firmware/blink/blink.ino) — serial boot
banner + 1 Hz LED toggle + `alive #N` heartbeat.

```bash
cd <repo-root>
arduino-cli compile --fqbn esp32:esp32:esp32s3 firmware/blink
arduino-cli upload  -p /dev/cu.usbserial-1430 \
  --fqbn 'esp32:esp32:esp32s3:UploadSpeed=115200' firmware/blink
arduino-cli monitor -p /dev/cu.usbserial-1430 -c baudrate=115200   # expect: alive #N (uptime Ns)
```

**Verified output:**

```
alive #85 (uptime 86s)
alive #86 (uptime 87s)
alive #87 (uptime 88s)
```

**Remaining for Phase 1:** confirm the onboard LED blinks (the `LED_BUILTIN`
GPIO is a guess on the generic profile — a wrong pin just means no visible LED,
serial is the real proof), then flash **Seeed's official reTerminal E1001 GxEPD2
example** to (a) draw _anything_ to the panel and (b) capture the **authoritative
driver class + SPI/BUSY/RST/DC pin map** — both are required before Phase 2.

> Do not guess the GxEPD2 driver class or pins. They must come from Seeed's
> example for this exact board; a wrong class smears or shows nothing.

## Panel facts (verified from Seeed's E1001 example)

| Thing | Value |
| --- | --- |
| Panel | **GDEY075T7** (7.5", 800×480) |
| Controller | **UC8179** |
| GxEPD2 class | `GxEPD2_750_GDEY075T7` |
| Grayscale | **4 levels — but only via Seeed's fork** (`Seeed_GxEPD2`, `initGrayMode(GRAY_LEVEL4)`, palette `TFT_GRAY_0..3`). Upstream GxEPD2 drives this class **1-bit B/W only**. |
| SPI pins | `SCK=7  MOSI/DIN=9  CS=10  DC=11  RST=12  BUSY=13` (no power-enable pin) |

> **Course-correction vs project docs.** `CLAUDE.md` + `FIRMWARE_BRINGUP.md` state
> the E1001 is "4-level grayscale, maps 1:1 onto the renderer's 2-bit output."
> That is achievable **only on Seeed's fork** — stock upstream GxEPD2 would flatten
> our 4 levels to black/white. The 1:1 mapping the design assumes requires
> `Seeed_GxEPD2` (or `Seeed_GFX`) grayscale mode, not the `GxEPD2` library installed
> in Phase 0.

## Display library — committed path

- **Library:** `Seeed_GxEPD2` fork (`github.com/Seeed-Projects/Seeed_GxEPD2`),
  cloned into `~/Documents/Arduino/libraries/Seeed_GxEPD2`. It self-identifies as
  `name=GxEPD2 version=1.6.9`, so **uninstall upstream GxEPD2 first** or they collide.
- **Grayscale demo:** `examples/GxEPD2_reTerminal_E1001_Gray4` — flashed + verified
  compiling/uploading. Draws a 4-level test image once at boot (`loop(){}` idles).
  **✅ Panel confirmed showing 4 distinct gray shades** — Phase 1 complete; the
  grayscale LUT + two-bit-plane path is proven working on hardware.

```bash
arduino-cli lib uninstall GxEPD2                       # remove upstream
git clone --depth 1 https://github.com/Seeed-Projects/Seeed_GxEPD2.git \
  ~/Documents/Arduino/libraries/Seeed_GxEPD2
EX=~/Documents/Arduino/libraries/Seeed_GxEPD2/examples/GxEPD2_reTerminal_E1001_Gray4
arduino-cli compile --fqbn esp32:esp32:esp32s3 "$EX"
arduino-cli upload -p /dev/cu.usbserial-1430 --fqbn 'esp32:esp32:esp32s3:UploadSpeed=115200' "$EX"
```

## Phase 2 — framebuffer translation reference (the high-risk step, de-risked)

The Gray4 example **is** the translation spec. Findings to carry into InfoBento firmware:

- **Canvas:** 2bpp, `800×480/4 = 96,000` bytes — **byte-for-byte the same size** as
  the renderer's output (`packages/core/src/constants.ts`: `ceil(w/4)*h`).
- **Gray mapping — INVERTED, must remap.** Renderer (`packages/renderer/src/draw.ts:23`)
  is `0=white 1=light 2=dark 3=black`; the panel is `0=black 1=dark 2=light 3=white`.
  They are flipped → the unpacker MUST apply **`panel_level = 3 − renderer_level`**
  (0↔3, 1↔2), else the image renders as a photo-negative.
- **Source pixel extraction:** 2bpp **MSB-first** — pixel 0 of each byte is in bits 7-6.
  For pixel x: `byteIndex = y*ceil(w/4) + (x>>2)`, `shift = (3 − (x & 3)) * 2`,
  `level = (byte >> shift) & 0x03`. (Matches `setPixel`/`getPixel` in `draw.ts`.)
- **Encoding:** UC8179 grayscale wants **two bit-planes**, packed per Seeed_GFX's
  `EPD_PUSH_NEW_GRAY_COLORS` truth table — **not** a naive MSB/LSB split. The example
  carries the verified table + the VCOM/WW/KW/WK/KK LUTs verbatim. Phase 2 = feed our
  framebuffer through this same plane-packing instead of the demo's drawn canvas.
- **SPI:** HSPI, `hspi.begin(EPD_SCK=7, -1, EPD_MOSI=9, -1)`, manual CS/DC/RST/BUSY.

## Phase 2 — IMPLEMENTED + flashed (`firmware/static-frame/`)

A self-contained sketch pushes an InfoBento-native frame to the panel:

- `firmware/static-frame/ramp_frame.h` — a 4-band vertical gray ramp generated in
  the renderer's exact 2bpp format (gen step embedded in the walkthrough history).
- `firmware/static-frame/static-frame.ino` — vendors Seeed's UC8179 driver (LUTs,
  init, two-plane upload **with its internal `3 - gray` waveform inversion kept**)
  and adds the InfoBento→panel convention flip.

**Translation, distilled:** renderer (`0=white..3=black`) → panel canvas
(`0=black..3=white`) is a per-pixel `3 − level` flip. Because both buffers are
identical 2bpp MSB-first layouts, that flip is exactly **a per-byte bitwise NOT**
(`canvas[i] = ~IB[i]`; `0x00↔0xFF`, `0x55↔0xAA`). The vendored upload then applies
its own polarity inversion for the panel waveform — two distinct, both-necessary
transforms.

**Verified serial trace** (full boot caught via DTR/RTS reset):

```
[IB] Translated 96000 bytes
[IB] UC8179 gray mode init done
[IB] Frame uploaded (2 bit planes)
[IB] Refresh 3610 ms        <- full 4-gray refresh ~3.6 s (Phase 4 power input)
[IB] Done. Expect 4 bands L->R: WHITE LIGHT DARK BLACK
```

**✅ Panel confirmed: 4 clean bands WHITE→LIGHT→DARK→BLACK (correct order).**
Framebuffer-translation risk (the plan's highest-uncertainty item) is **closed**.

### Serial tooling (use for Phases 3–6)

Two readers, **never both at once** (the port is exclusive — they'll fight over it):

- **Steady-state loop** (`200`/`304` pulls): `arduino-cli monitor -p <PORT> -c baudrate=115200`.
  Zero setup, manages DTR/RTS correctly. But it attaches _after_ the post-flash
  reset, so it **misses one-shot boot prints** (Wi-Fi connect, panic backtraces,
  early `setup()` failures).

- **Boot + loop** (debug a crash-on-boot or Wi-Fi failure): open the port _first_,
  pulse RTS(EN) to reset into the app, then read forever. Captures boot **and**
  every subsequent pull. One-time venv (system pip is PEP-668 blocked):

  ```bash
  python3 -m venv ~/.venvs/ibserial && ~/.venvs/ibserial/bin/pip install pyserial
  firmware/dev/serial-boot.sh                 # auto-detects /dev/cu.usbserial*, tees to firmware/dev/serial.log
  firmware/dev/serial-boot.sh /dev/cu.usbserial-1430 115200   # or pass port/baud explicitly
  ```

  `firmware/dev/serial-boot.sh` is a local bench helper (gitignored, like the rest
  of `firmware/dev/`). It resets the board on every run, so it's a debugging tool —
  for passive observation of a running device, prefer `arduino-cli monitor`.

## Phase 3 — Wi-Fi + device-pull loop ✅ (flashed + verified on hardware)

**Host side (all verified):**

- API binds loopback by default — must export **`HOST=0.0.0.0`** so the device can
  reach it on the LAN. Also `INFOBENTO_DB_PATH` must match between mint + server.
- Renderer honors `config.width`/`config.height`, so a device minted with an
  **800×480** config yields a 96,000-byte landscape frame (`X-Frame-Width: 800`).

```bash
# 800x480 config = reference config + dimensions
node -e "const c=require('./docs/reference/infobento-config.json');c.width=800;c.height=480;require('fs').writeFileSync('firmware/dev/config-e1001.json',JSON.stringify(c,null,2))"
export INFOBENTO_DB_PATH=~/.infobento/dev.db
npx tsx scripts/mint-device.ts --db "$INFOBENTO_DB_PATH" --config firmware/dev/config-e1001.json   # -> device id
HOST=0.0.0.0 npm run dev -w @infobento/api    # serves on 0.0.0.0:4000
# verify from the device's vantage point:
curl -sI "http://192.168.1.150:4000/api/device/<id>/frame?orientation=landscape"   # 200, x-frame-width:800
```

Verified: LAN fetch → `200, content-length 96000, x-frame-width 800`; repeat with
`If-Modified-Since` → `304`.

**Firmware:** `firmware/device-pull/device-pull.ino` — Wi-Fi connect, poll loop
(`IB_POLL_MS=15s`), `If-Modified-Since` caching, draw on 200 / skip on 304. Reuses
the vendored UC8179 path. Secrets live in **`firmware/secrets.h`** (gitignored;
device id + API host pre-filled, Wi-Fi creds blank).

> **Build note:** `secrets.h` sits in `firmware/`, not the sketch dir, so compile
> with `--build-property "compiler.cpp.extra_flags=-I<repo>/firmware"`:
>
> ```bash
> arduino-cli compile --fqbn esp32:esp32:esp32s3 \
>   --build-property "compiler.cpp.extra_flags=-I$PWD/firmware" firmware/device-pull
> # upload takes NO --build-property (compile-only flag); it just flashes the built binary:
> arduino-cli upload -p /dev/cu.usbserial-1430 \
>   --fqbn 'esp32:esp32:esp32s3:UploadSpeed=115200' firmware/device-pull
> ```

**✅ Verified on hardware (2026-06-15):** flashed via `arduino-cli upload` (hash
verified), reTerminal joined Wi-Fi and reached the LAN API. Full cycle observed on
serial: steady `304 → skip refresh`, then after bumping the device's `last_modified`
a `200 → frame OK → drew frame in 4486 ms` (full 4-gray eInk redraw), settling back
to `304`. Wi-Fi join, `200`-draw, and `If-Modified-Since` → `304`-skip paths all
confirmed end-to-end.

## Phase 4+

This walkthrough intentionally stops at Phase 3. Phases 4–7 (deep sleep, resilience, captive-portal provisioning, and the merged integrated build) have since landed and are documented in [FIRMWARE_BRINGUP.md](FIRMWARE_BRINGUP.md) and [`firmware/README.md`](../../firmware/README.md).

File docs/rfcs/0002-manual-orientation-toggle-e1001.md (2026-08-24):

# RFC 0002 — Manual orientation toggle on the E1001 (cache both frames, redraw locally)

| | |
| --- | --- |
| **Status** | Implemented — `/frames` endpoint (#163/#164), firmware toggle (#165), folded into the integrated build (#174) |
| **Issue** | [#160](https://github.com/jasoneplumb/infobento.com/issues/160) |
| **Author** | jasoneplumb |
| **Created** | 2026-06-30 |
| **Supersedes / relates** | shared enabler for auto-rotate #49; tilt hardware #48; Phase 7 C3 port #57 |

## Summary

On the E1001 test device, let the user **flip display orientation locally** —
landscape ⇄ portrait — by redrawing a **cached** frame, with **no network round
trip**. Each scheduled (network) wake fetches **both** orientation framebuffers
and persists them to flash; a manual trigger then wakes the device, reads the
_other_ orientation from flash, and refreshes the panel. The cloud render
pipeline is essentially unchanged; the work is one new combined raw endpoint, a
flash-backed frame store on the device, a dedicated **green-button** wake source,
and a redraw-from-flash path. The "cache both frames + redraw locally" machinery is a
deliberate **shared enabler** for the tilt-driven auto-rotate in #49.

## Decisions

| # | Question | Recommendation |
| --- | --- | --- |
| 1 | Both-frames delivery | **New combined `GET /api/device/:id/frames`** returning both raw buffers in one response. The frame handler already renders both orientations; two `/frame` calls double the render, hydration, TLS, and rate-token cost for nothing. |
| 2 | Storage across sleep | Persist both raw frames in a **LittleFS data partition** (`/orient/frames.bin`, 2× the panel frame). Written **only on a network wake** (1–2×/day) → wear is decades; read on a button wake. |
| 3 | Manual trigger input | Use the E1001's **dedicated green user button** as a single-purpose orientation toggle on **its own GPIO**. **Do not overload the reset pinhole** — factory reset stays GPIO2-only and unchanged. The button's exact GPIO and idle polarity are a bench-confirm item (not documented in-repo); it **must** be an RTC-capable pin so it can wake the device from deep sleep (Q4). |
| 4 | Wake source | **ext1 deep-sleep wake** on the **green-button GPIO** (polarity per the button's wiring — confirm at bench; likely active-LOW → `ESP_EXT1_WAKEUP_ANY_LOW`), alongside the existing RTC-timer wake. On a button wake, redraw the other cached orientation from flash with the radio off. The reset pinhole keeps its own wake/reset behavior, separate and unchanged. |

MCU-specific items (ext1 → C3 GPIO-wake API; the green-button GPIO is re-mapped
for the production board) are marked for the Phase 7 ESP32-C3 port (#57). The
reset **pinhole** keeps its own GPIO2-vs-GPIO9 split
(`firmware/provisioning/provisioning.ino`); the toggle button is a **separate**
input from the pinhole on both boards.

> **Post-implementation note.** The bench-confirm items resolved as: green button
> on **GPIO3**, ext1 deep-sleep wake, flashed with the 8 MB `default_8MB`
> partition scheme — documented in `firmware/README.md`. Separately, the later
> integrated build (#171/#172) moved factory reset from the GPIO2 pinhole to
> holding the **two white buttons** for 5 s; the "factory reset stays GPIO2-only"
> statements throughout this RFC describe the state at the time of writing.

## Motivation

`renderBoth` (`packages/renderer/src/index.ts:366`) already produces a
landscape **and** a portrait `FrameBuffer` from one config, and
`getDeviceFrameForPull` (`packages/api/src/device.ts:126`) already calls it on
every 200 wake, then **discards one** orientation
(`device.ts:169` — `orientation === 'portrait' ? dual.portrait : dual.landscape`).
So the server is already paying to render both; the device just never receives
the unused half.

Today's firmware (`firmware/deep-sleep/deep-sleep.ino`) fetches a single
orientation (`?orientation=landscape`, line 261), draws it, and deep-sleeps.
Heap/RAM — including the 96 KB framebuffer — is cleared on deep sleep; only
`RTC_DATA_ATTR` survives, and RTC slow memory (8 KB on the S3) cannot hold a
frame. To flip orientation on a button wake **without** re-fetching, the second
frame must already be on the device, in non-volatile storage. That is the whole
problem this RFC solves.

## Goals

- A manual trigger flips landscape ⇄ portrait by redrawing a cached frame, **Wi-Fi
  off**, in roughly one eInk refresh time (~0.3–0.75 s).
- Each network wake delivers both frames in **one** request (one rate token, one
  hydration, one TLS handshake), preserving the 1–2×/day solar/battery budget.
- The 304-skip power win (RFC 0001 §4) is preserved unchanged.
- The persistence + redraw machinery is reusable by #49 (auto-rotate) with only a
  different _trigger_.

## Non-goals

- Web-side toggle persistence (which orientation a device "prefers" across config
  edits) — explicitly out of scope per the issue; separate issue.
- Full 4-orientation auto-rotate and tilt hardware (#49 / #48) — this RFC is the
  **manual** trigger and the shared enabler only.
- The production enclosure hole / button placement for the toggle button (SCAD
  #50 / Phase 7).
- Changing the eInk cadence or the deep-sleep/RTC model.

## Question 1 — Both-frames delivery

**Recommendation: add a new combined raw endpoint `GET /api/device/:id/frames`**
returning both framebuffers in one response. Keep the existing single-orientation
`GET /api/device/:id/frame?orientation=` for the web editor and backward compat.

### Why not two `/frame` requests (option a)

It needs no API change, but it is the wrong tradeoff on a once-or-twice-daily
power budget:

- **Doubles the server-side work.** Each `/frame` call runs the full
  `hydrateConfig → renderBoth` pipeline (`device.ts:154–168`) and throws away one
  orientation. Two calls = two hydrations (2× upstream provider load, the exact
  thing RFC 0001's cache exists to avoid) and two dual renders.
- **Two rate tokens.** `GET /api/device/:id/frame` calls `consumeToken(id)`
  (`server.ts:480`); two requests per wake double the device's rate-limit
  footprint.
- **Two TLS handshakes + two HTTP round trips.** Wi-Fi active time dominates the
  per-wake energy (`docs/hardware/POWER.md`: ~70 mA for ~10–20 s, full TLS
  handshake every wake since deep sleep clears the session). Doubling the network
  phase is the most expensive way to get the second frame.
- **Two-step 304 reasoning.** Conditional-GET gating would have to agree across
  two independent requests.

`POST /api/preview?dual=1` (`server.ts:128`) is **not** a candidate: it returns
base64-encoded **PNG** for the web editor (`generateDualPreview`), not raw 2bpp
framebuffers, and it is a `POST` that carries the full config in the body. Same
for `POST /api/render-dual` (`server.ts:145`) — base64 JSON, validated, no
device auth via the bearer-id URL, no `Last-Modified`/304 gating. Neither suits a
deep-sleep device.

### Wire format / API contract for `/frames`

The handler mirrors `getDeviceFrameForPull` exactly, except it returns **both**
buffers instead of selecting one. It reuses the same device lookup, rate token,
`effectiveLastModified` 304 gate, `hydrateConfig`, and `renderBoth` — so the new
code is thin and the freshness semantics are identical to `/frame`.

- **Method/path:** `GET /api/device/:id/frames` (bearer id in the URL, like
  `/frame`).
- **304 gating:** identical to `/frame` — `If-Modified-Since` vs
  `effectiveLastModified(device, now)` (`device.ts:87`), evaluated **before**
  parse/hydrate so a skip stays allocation-free. A 304 returns no body; the
  device keeps both cached frames.
- **200 body:** the two raw buffers **concatenated, landscape first, then
  portrait**, `Content-Type: application/octet-stream`. For the E1001
  (800×480) that is `96000 + 96000 = 192000` bytes; for the production
  GDEH0576T81 (920×680) it is `156400 + 156400 = 312800` bytes.
- **Headers** (so the device can split the body without assuming the two halves
  are equal — they are equal for these panels, but the contract should not bake
  that in):
  - `Content-Length: <landscapeLen + portraitLen>`
  - `X-Frame-Landscape-Width`, `X-Frame-Landscape-Height`,
    `X-Frame-Landscape-Bytes`
  - `X-Frame-Portrait-Width`, `X-Frame-Portrait-Height`,
    `X-Frame-Portrait-Bytes`
  - `Last-Modified`, `X-Refresh-Interval`, `X-Device-Forget` — carried through
    unchanged from the `/frame` path (`server.ts:496–505`).

The device reads `X-Frame-Landscape-Bytes` of landscape, then
`X-Frame-Portrait-Bytes` of portrait, validating each against the expected
`w*h/4` exactly as `deep-sleep.ino` already validates a single frame
(`deep-sleep.ino:291`). On a size mismatch it skips the write (keeps the prior
cached pair), matching the existing "bad size → skip draw" guard.

> Design-only sketch of the server handler (not to be implemented in this RFC):
>
> ```ts
> // analogous to getDeviceFrameForPull, returns both buffers
> export async function getDeviceFramesForPull(...): Promise<DeviceFramesResult> {
>   // ... same 404 / 304 / parse / hydrate guards ...
>   const dual = renderBoth(hydrated);
>   return { status: 200, landscape: dual.landscape, portrait: dual.portrait,
>            lastModifiedMs: effectiveMs, refreshIntervalSec };
> }
> ```

## Question 2 — Storage across deep sleep

**Recommendation: persist both raw frames in a LittleFS data partition**, written
**only on a network (timer) wake**, read on a button wake.

### Why flash, and why a filesystem

- RAM/PSRAM is cleared on deep sleep; RTC slow memory is 8 KB on the ESP32-S3 —
  three orders of magnitude too small for one 96 KB frame, let alone two. The
  issue's premise (flash is the only option) is correct.
- The provisioning sketch already uses **NVS** (`Preferences`,
  `provisioning.ino:91`) for small key/values. NVS is the wrong store for ~192 KB
  blobs — it is a key/value page store tuned for small entries. Use a separate
  **LittleFS** data partition for the frame blobs; keep NVS for creds and small
  state. LittleFS gives wear-leveling and a trivial file API
  (`/orient/frames.bin`, or two files `/orient/landscape.bin` +
  `/orient/portrait.bin`).
- A tiny persisted **`currentOrientation`** flag (which frame is on the panel
  now) lives in `RTC_DATA_ATTR` (survives deep sleep, free) with an NVS mirror for
  the cold-boot/brown-out case. On a button wake the device redraws
  `other(currentOrientation)` and flips the flag.

### Flash budget

- E1001 frame pair: **~192 KB**. Production GDEH0576T81 pair: **~313 KB**
  (920×680, the 156,400-byte frame from `DISPLAY.md`/`constants.ts`). Size the
  partition for the **production** figure with margin — recommend a **≥ 512 KB**
  LittleFS partition so the same layout carries from the E1001 prototype to the
  C3 production board with no re-partition.
- **Open item for the maintainer (bench-only, repo can't tell us):** confirm the
  E1001's ESP32-S3 flash size and the **currently flashed partition table**.
  `firmware/blink/blink.ino:26` prints `ESP.getFlashChipSize()`; the production
  C3 flash size is a Phase 7 input. A 512 KB data partition is trivial against the
  4–16 MB typical on these modules, but the active `partitions.csv` (or the
  selected Arduino partition scheme) must actually reserve it.

### Wear implications

- Flash endurance on these parts is ~100 K erase cycles per sector, and LittleFS
  wear-levels writes across the partition. The critical design choice that makes
  wear a non-issue: **frames are written to flash only on a network wake**, i.e.
  the 1–2×/day scheduled refresh — **never** on a button toggle (a toggle only
  _reads_ flash). So the write rate is the refresh cadence: ~2 writes/day →
  ~730/year → well under endurance limits for the device's entire service life,
  before wear-leveling even helps.
- Only rewrite when the frame actually changed — gate the flash write on the
  `Last-Modified`/304 result. A 304 wake (within a freshness window) writes
  nothing; only a 200 wake (config edit or data-bucket boundary, RFC 0001 §4)
  replaces the cached pair. This further reduces writes below the nominal cadence.

### Read-on-wake path

```
button (ext1) wake
  -> (radio stays off)
  -> mount LittleFS
  -> next = other(currentOrientation)
  -> read /orient/frames.bin at next's offset into g_fb
  -> drawFrame()            // existing init/upload/refresh/sleep
  -> currentOrientation = next   (RTC_DATA_ATTR + NVS mirror)
  -> re-arm both wake sources, deep sleep
```

If LittleFS is unmounted/empty (e.g. button pressed before the first network
wake ever populated it), the device logs and sleeps without drawing — same
"degrade to no-op, retry/ignore" discipline as the Phase 5 resilient path.

## Question 3 — Manual trigger input

**Recommendation: use the E1001's dedicated green user button as a
single-purpose orientation toggle, on its own GPIO — and leave the reset pinhole
alone.** A debounced press flips orientation; the recessed pinhole keeps its sole
job (≥5 s hold = factory reset), untouched. Two physical inputs, two unambiguous
meanings.

### Rationale and tradeoffs

- **Clean, single-purpose affordance.** A real front/side button is a far better
  "flip my screen" control than a paperclip pinhole, and it removes the safety
  hazard of an everyday gesture sharing an input with destructive factory reset.
  No press-duration guessing, no dead-band, no risk of a held toggle wiping creds.
- **The reset pinhole is unchanged.** `checkPinhole` (`provisioning.ino:398`) and
  its ≥5 s factory-reset hold keep working exactly as bench-verified in PR #134.
  This RFC adds an **independent** GPIO; it does not modify the pinhole path at all.
- **Hard requirement — the button's GPIO must be RTC-capable.** To wake the device
  from deep sleep (Question 4) the green button must sit on an RTC IO (ESP32-S3 RTC
  GPIOs are GPIO0–21). If the board wires the green button to a non-RTC pin it
  cannot be a deep-sleep wake source as-is — see the open question; the fallback
  (a non-deep-sleep poll) costs power and is undesirable on the 1–2×/day budget.
- **Bench-confirm items (not in repo).** The repo documents the panel SPI bus
  (`SCK 7, MOSI 9, CS 10, DC 11, RES 12, BUSY 13`), GPIO0 (BOOT/USB-DTR),
  GPIO19/20 (native USB), and GPIO2 (pinhole) — but **not** the green button's
  GPIO. Per the hardware walkthrough's "do not guess pins" rule, the exact pin, its
  idle polarity (active-low pull-up vs. active-high pull-down), and its
  RTC-capability must be read from Seeed's reTerminal E1001 schematic / pinout and
  verified at the bench before implementation. Firmware should name it via an
  `IB_DEV_E1001` constant (mirroring the existing pinhole split), not a magic
  number. _(Resolved at bench: GPIO3, ext1 wake — see `firmware/README.md`.)_

### MCU-specific (mark for Phase 7 C3 port #57)

- The green button's GPIO is **board-specific**; the production ESP32-C3 re-maps it
  to whatever free RTC/GPIO-wake-capable pin the production layout exposes, via the
  same `IB_DEV_E1001`-style constant split. Only the pin number and the wake API
  (Question 4) change; the single-tap toggle logic is identical. The reset
  **pinhole**'s own GPIO2→GPIO9 split is orthogonal and unaffected.

## Question 4 — Wake source

**Recommendation: enable the green-button GPIO as an ext1 deep-sleep wake
source** on the S3, **in addition to** the existing RTC-timer wake, and branch on
`esp_sleep_get_wakeup_cause()`.

### Mechanism (E1001 / ESP32-S3)

- Configure ext1 on the green-button pin: e.g.
  `esp_sleep_enable_ext1_wakeup(BIT(TOGGLE_BTN_GPIO), ESP_EXT1_WAKEUP_ANY_LOW)`
  for an active-LOW button (internal pull-up, reads LOW when pressed). If the board
  wires the button active-HIGH, use `ESP_EXT1_WAKEUP_ANY_HIGH` — confirm the idle
  polarity at the bench (Question 3). The pin must be RTC-capable (GPIO0–21 on the
  S3) for ext1 to use it.
- Keep the existing `esp_sleep_enable_timer_wakeup(...)`
  (`deep-sleep.ino:327`) armed too. Both sources coexist; the wake cause
  distinguishes them, exactly as `setup()` already inspects the cause today
  (`deep-sleep.ino:337`). The reset pinhole stays on its own pin and path,
  independent of the toggle button.

### Redraw-from-flash flow

```
setup() on wake:
  cause = esp_sleep_get_wakeup_cause()

  if cause == EXT1 (green button):
     debounce the press           // confirm a real toggle, not noise
     load other(currentOrientation) from LittleFS -> g_fb
     drawFrame(); flip currentOrientation
     // NB: NO Wi-Fi this path; factory reset is NOT here (pinhole owns it)

  else (TIMER or cold boot):   // existing network pull, extended
     pullBothFrames()          // GET /api/device/:id/frames
     on 200: write both frames to LittleFS; draw currentOrientation
     on 304: keep cached frames; no draw (unchanged power win)

  re-arm ext1 + timer; esp_deep_sleep_start()
```

The button path never touches the radio — that is the entire point: a flip costs
one eInk refresh and a flash read, not a Wi-Fi cycle. Factory reset is left
entirely to the pinhole's existing `checkPinhole` path, unchanged.

### MCU-specific (mark for Phase 7 C3 port #57)

- The **ESP32-C3 has no ext1**; use
  `esp_deep_sleep_enable_gpio_wakeup(BIT(TOGGLE_BTN_GPIO), ESP_GPIO_WAKEUP_GPIO_LOW)`
  instead. Same branch-on-wake-cause logic; only the enable call and the
  board-specific pin differ.

## Coordination with #48 (tilt hardware) and #49 (auto-rotate)

#160 is the **manual** trigger; #49 is the **automatic** (tilt-switch) trigger.
Everything _between_ the trigger and the panel is shared:

- **Shared enabler = "fetch both → store in flash → redraw locally."** Define a
  small firmware interface so both issues reuse it:
  - `storeFrames(landscape, portrait)` — write the pair to LittleFS (Question 2).
  - `redrawFromFlash(orientation)` — read one orientation and `drawFrame()`
    (Question 2 read path).
  - a single persisted `currentOrientation` slot (`RTC_DATA_ATTR` + NVS mirror)
    that both triggers read/write. #49's issue independently says it will "store
    current orientation in RTC memory" — this RFC's slot **is** that slot; they
    must not define two.
  - the combined `GET /api/device/:id/frames` endpoint (Question 1) — #49 fetches
    the same way.
- **Only the trigger differs.** #160: the green user button on ext1/GPIO-wake, a
  debounced single-tap toggle. #49: two tilt-switch GPIOs as wake sources,
  debounced, decoded to a 4-orientation enum (its issue's `(A,B)` table).
- **4 orientations from 2 stored frames.** #49 wants four orientations
  (landscape, portrait, and both inverted); this RFC caches only the two base
  orientations. Recommend `/frames` stay a **2-frame** contract and the firmware
  derive the inverted variants by a **180° rotation of the cached buffer on the
  device** (a byte-reverse + in-byte 2bpp-pixel-reverse of the packed buffer),
  rather than the API shipping four frames (which would double bandwidth and
  flash). This keeps #160's flash budget at 2× and gives #49 all four cheaply.
  Flag as a cross-cutting decision to confirm with #49's owner; #49's separate
  server-side `rotateFrameBuffer()` plan (its issue body) would then apply to the
  _web preview_ path, while the _device_ does its own 180° flip for the inverted
  cases. (90° transpose is **not** needed on-device — the server already renders
  true portrait via `renderBoth`; only the 180° invert is a local transform.)

## Scope / phasing

**In scope for #160:**

1. **API** — add `GET /api/device/:id/frames` (combined raw, Question 1) + tests.
   Server-only; no firmware dependency, lands first.
2. **Firmware flash store** — add a ≥512 KB LittleFS data partition;
   `storeFrames` on a 200 network wake; bench-verify both halves written and
   re-readable (Question 2).
3. **Firmware button wake + redraw** — ext1 wake on the green-button GPIO,
   debounced single-tap → `redrawFromFlash` (Questions 3–4); bench-verify a tap
   flips orientation with Wi-Fi off, and that the reset pinhole still
   factory-resets independently.
4. **Extract the shared interface** (`storeFrames` / `redrawFromFlash` /
   `currentOrientation`) so #49 plugs in its tilt trigger.

**Deferred / out of scope:**

- Web-side toggle persistence (per the issue — separate issue).
- 4-orientation auto-rotate and tilt hardware (#49 / #48), beyond designing the
  shared interface here.
- The production enclosure hole / button placement (SCAD #50); the Phase 7
  ESP32-C3 port (#57) re-maps the toggle-button GPIO and the wake API
  (ext1→GPIO-wake) — only the MCU-specific deltas above. (The reset pinhole's own
  GPIO2→GPIO9 split is separate and already tracked.)
- Any change to the eInk cadence or RTC freshness model (RFC 0001 stands).

## Open questions for the maintainer

- **Flash/partition (bench-only):** what is the E1001 ESP32-S3 flash size and the
  currently flashed partition table? Is there room to add a ≥512 KB LittleFS data
  partition (there should be, but the active `partitions.csv` / Arduino partition
  scheme must reserve it)? Confirm via `ESP.getFlashChipSize()` at the bench.
  _(Resolved: flashed with `FlashSize=8M` + the `default_8MB` partition scheme —
  see `firmware/README.md`.)_
- **Green-button GPIO (bench-only):** which GPIO is the E1001 green user button
  on, what is its idle polarity, and is it RTC-capable (GPIO0–21 on the S3) so it
  can be an ext1 deep-sleep wake source? If it is **not** RTC-capable we need a
  fallback (alternate pin, or a non-deep-sleep poll) — confirm from Seeed's
  schematic and at the bench before implementation. _(Resolved: GPIO3,
  RTC-capable, ext1 wake — see `firmware/README.md`.)_
- **Inverted orientations:** derive on-device via 180° rotation (keep the 2-frame
  `/frames` contract) vs. have the API return all four? (Affects #49; recommend
  on-device rotation.)
- **`/frames` 304:** confirm it should gate identically to `/frame` on the shared
  `Last-Modified` (recommended — keeps the power model consistent).
- **Store format:** one `/orient/frames.bin` (offset split) vs. two files? (Minor;
  recommend one file with header-declared lengths to mirror the wire format.)

## Testing

- **API unit:** `getDeviceFramesForPull` returns both buffers; 404/304/500 guards
  match `/frame`; 304 within a window, 200 at a data-bucket boundary; headers
  declare correct per-orientation byte lengths.
- **API integration:** `GET /frames` with mocked hydration → concatenated body of
  the expected total length; `If-Modified-Since` → 304 no body.
- **Firmware (bench, operator):** a 200 network wake writes both halves to
  LittleFS and they re-read byte-identical; a green-button tap with Wi-Fi off flips
  the panel orientation; the reset pinhole's ≥5 s hold still factory-resets
  (independent input, unchanged); a tap before the first network wake (empty store)
  no-ops without drawing.

## Security & privacy

- `/frames` reuses the existing trust boundary: the bearer device id in the URL,
  the same rate limiter (`consumeToken`), and the same `Last-Modified`/forget
  ride-along (`server.ts:505`). No new auth surface.
- Cached frames in flash are already-rendered public panel pixels (weather, etc.),
  not credentials; they carry no secret beyond what the panel already displays.
- The button-wake path makes **no** network call, so it adds no external
  exposure; the device still only ever talks to the InfoBento API (unchanged).

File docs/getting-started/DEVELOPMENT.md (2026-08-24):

# Development

## Common Workflows

### Building

```bash
npm run build        # Build all packages (tsc -b with project references)
npm run typecheck    # Type-check only (no emit)
```

Packages build in dependency order: core -> data -> renderer -> api.
The web package builds separately via Vite.

### Running the app

```bash
npm run dev -w @infobento/api    # Hono API on :4000 (tsx watch)
npm run dev -w @infobento/web    # Vite HMR on :5173, proxies /api to :4000
```

Run both (two terminals) and open http://localhost:5173.

### Testing

```bash
npm test             # Run all tests
npm test -- --watch  # Watch mode for TDD
```

Tests live alongside source files as `*.test.ts`.

### Linting & Formatting

```bash
npm run lint         # ESLint (strict TypeScript rules)
npm run format       # Auto-format with Prettier
npm run format:check # Check formatting without writing
```

## Coding Conventions

### Import Extensions

**Relative** imports in `core`, `data`, `renderer`, and `api` must include `.js`
extensions — `module: "Node16"` with no bundler means extensionless relative
imports fail at runtime:

```typescript
import { splitLeftFraction } from './constants.js';
```

**Cross-package** imports use the bare specifier. Each package exports only `"."`
— with one deliberate exception: `@infobento/data` also exports `./safe-fetch`,
the Node-only SSRF guard kept out of the browser-safe barrel. Any other subpath
import throws `ERR_PACKAGE_PATH_NOT_EXPORTED`:

```typescript
import type { BentoBox } from '@infobento/core';
```

The `web` package uses Vite's bundler and does NOT require extensions.

### Intent Documentation

Add intent headers to new files:

```typescript
/**
 * Intent: [Why this module exists]
 * Context: [Where it's called from]
 * Pattern: [Key architectural pattern]
 * Future: [Known limitations or plans]
 */
```

Use inline tags for decisions:

- `// tradeoff:` — What was sacrificed for what gain
- `// constraint:` — What limits the solution
- `// future:` — Known tech debt

See [docs/reference/INTENT_TEMPLATES.md](../reference/INTENT_TEMPLATES.md) for the full standard.

### Type-Only Imports

Use `import type` for type-only imports (enforced by `verbatimModuleSyntax`):

```typescript
import type { BentoBox } from '@infobento/core';
```

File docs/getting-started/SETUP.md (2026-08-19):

# Setup

Get InfoBento running locally in under 5 minutes.

## Prerequisites

- Node.js 20+
- npm 10+
- Git

## Steps

```bash
# 1. Clone
git clone https://github.com/jasoneplumb/infobento.com.git
cd infobento.com

# 2. Install
npm install

# 3. Verify
npm run build        # Compile all packages
npm test             # Run tests
npm run lint         # Check linting
npm run format:check # Check formatting
```

All four commands should pass with zero errors. If they do, you're ready to contribute.

## Package Overview

| Package | What it does |
| --- | --- |
| `@infobento/core` | Types, bento box definitions, layout engine |
| `@infobento/data` | Box-data providers (weather, quote, …) + cache |
| `@infobento/renderer` | eInk frame buffer generation |
| `@infobento/api` | Render API, auth + pairing (SQLite) |
| `@infobento/web` | Web configuration interface |

## Next Steps

- [Architecture](ARCHITECTURE.md) — understand the system design
- [Development](DEVELOPMENT.md) — learn the workflow
- [Contributing](../../CONTRIBUTING.md) — PR guidelines

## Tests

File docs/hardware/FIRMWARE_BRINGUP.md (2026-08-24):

# Firmware Bring-Up Plan

> _Path to a first working firmware: prove the full loop on the reTerminal E1001 dev hardware, then port to the production GDEH0576T81._

**Status (2026-08):** **Phases 0–6 are ✅ bench-verified on the reTerminal E1001** — the first-working-flash milestone (end of Phase 4) plus resilience (Phase 5) and captive-portal provisioning (Phase 6) — and **Phase 7 has ✅ shipped as the merged integrated build** (`firmware/integrated/`, PR #174, issue #173): provisioning + dual-orientation deep-sleep pull + green-button orientation flip + two-white-button factory reset in one sketch. What remains is porting to the production GDEH0576T81 + ESP32-C3 once the panel is sourced (**#57** is closed — 4-level gray is proven on the E1001). Authoritative per-phase sketch status, serial traces, and the bench power snapshot live in [`firmware/README.md`](../../firmware/README.md#phase-status); operator bench checklists in [PHASE4_BENCH_CHECKLIST.md](PHASE4_BENCH_CHECKLIST.md) and the [E1001 walkthrough](walkthrough-E1001-hw-setup.md).

## Why dev-first

The production panel (Good Display GDEH0576T81, 5.76" 920×680, SSD2677) is **not yet sourced** — its purchase is deferred (see [DISPLAY.md](DISPLAY.md)). The Seeed reTerminal E1001 (7.5" 800×480, ESP32-S3, 4-level grayscale) is in hand and maps 1:1 onto the renderer's 2-bit output. The cloud-side contract (`/api/device/:id/frames` + `/frame` + `/config`) is identical for both panels, so everything proven on the reTerminal ports directly. We bring up firmware on the reTerminal, then swap panel + MCU for production.

## What the firmware talks to (already built)

The cloud half of the contract is implemented and stable — firmware can be written against it today:

- `GET /api/device/:id/config` — config JSON, `If-Modified-Since`/`304`, `Last-Modified` (`packages/api/src/server.ts:607`)
- `GET /api/device/:id/frame?orientation=landscape|portrait` — raw 2-bit framebuffer (`application/octet-stream`), `X-Frame-Width` / `X-Frame-Height` headers, `If-Modified-Since`/`304` (`server.ts:629`)
- `GET /api/device/:id/frames` — **both** orientation framebuffers in one response (portrait pre-rotated server-side); this is the endpoint the current integrated firmware pulls
- Device id **is** the bearer secret (opaque token, no auth header). Rate limit 10/min per device.
- Framebuffer format: 2-bit packed, 4 px/byte, `ceil(width/4) * height` bytes (`packages/core/src/constants.ts:15`). reTerminal: `ceil(800/4)*480 = 96,000` bytes. Production: `ceil(920/4)*680 = 156,400` bytes.

## Repo-side gaps the firmware needs (not yet built)

These are not firmware code but block an end-to-end provisioned device. Most are now built:

1. **Device-minting path** — ✅ **done** (PR #109). `mintDevice()` (`packages/api/src/mint.ts`) wraps `createDevice` + `setConfig` atomically with pair-code generation + collision retry; the bring-up CLI `scripts/mint-device.ts` mints a device, seeds a config (`--config`), and prints the device id + pair code + `/frame` URL. A deployable operator mint CLI for the prod host followed (PR #142, see [DEPLOY.md](../DEPLOY.md)). QR sticker generator done (#78, PR #121); the physical sticker spec remains (sticker epic #80, #79).
2. **`POST /api/pair` HTTP route + web `/pair/:code` page** — ✅ **done** (#74, PR #112). The claim flow (`claimDevice` + HTTP route + web page) is wired end-to-end for real onboarding.
3. **Captive-portal provisioning** — ✅ firmware sketch **bench-verified** (Phase 6 below; PR #133, #134). Remaining provisioning UX polish + the custom-server-URL self-host hatch tracked in issue **#39**.
4. **`POST /api/device/forget`** (web-side "forget Wi-Fi") — ✅ **done** (PR #132): same effect as the firmware pinhole reset.

## Framework decision

**Recommended: Arduino + GxEPD2.** Issue #57 already plans to validate the production panel with `GxEPD2_576_GDEH0576T81`, so using GxEPD2 across both dev and production keeps one display abstraction. ESP-IDF is the alternative (better deep-sleep control, larger learning curve) — defer unless GxEPD2's power management proves inadequate for the solar budget.

**Open integration risk — framebuffer translation.** The renderer emits a **2-bit packed** buffer (4 px/byte). GxEPD2 does not consume that layout directly — it expects either per-pixel writes or separated bitplanes for grayscale. The firmware must unpack our buffer into the controller's expected format (bit order + how the 4 levels map to the panel's grayscale waveforms). This is the single highest-uncertainty step and can only be validated on hardware (Phase 2). If translation is costly on-device, consider adding a firmware-friendly frame encoding to the API later — do **not** assume it now.

---

## Phases

Each phase is independently verifiable on the bench. Do not advance until the prior phase's "Done when" holds.

### Phase 0 — Prerequisites ✅ done

- reTerminal E1001 in hand, USB-C data cable, Arduino IDE / arduino-cli + ESP32-S3 board support + GxEPD2.
- API reachable from the device's network (run `npm start -w @infobento/api`, note the LAN IP, or use a deployed instance).
- **Mint a bring-up device:** ✅ run `npx tsx scripts/mint-device.ts --config <800x480-config.json>`; it mints a device (`createDevice` + pair code), seeds the config so `/frame` returns 200 (it 404s with no `config_json` — `device.ts:74`), and prints the device **id**.
- **Done when:** `curl http://<api>/api/device/<id>/frame` returns 200 with `X-Frame-Width: 800` (frame width follows the seeded config's resolution).

### Phase 1 — Toolchain + blink ✅ bench-verified

- Flash a minimal sketch; confirm serial logging and the board boots.
- **Done when:** a known-good Seeed reTerminal example draws _anything_ to the panel.

### Phase 2 — Panel bring-up from a static frame ✅ bench-verified (framebuffer translation retired)

- Fetch one frame once (hardcode the URL + device id), translate the 2-bit packed buffer to GxEPD2's format, and push it.
- This is where the framebuffer-translation risk is resolved. Validate grayscale level mapping and bit order against a known test frame.
- **Done when:** the panel shows the cloud-rendered frame correctly (4 levels, no smearing, correct orientation).

### Phase 3 — Wi-Fi + device-pull loop ✅ bench-verified

- Connect Wi-Fi (hardcoded creds), `GET /frame` with the device id, honor `Content-Length` / `X-Frame-Width/Height`, send `If-Modified-Since` from the cached `Last-Modified` and skip the eInk refresh on `304`.
- Optionally `GET /config` first if firmware ever needs config locally (it does not render locally, so this is mainly for future use).
- **Done when:** editing the config server-side → device shows the new frame on next fetch; an unchanged config returns 304 and the panel is not refreshed.

### Phase 4 — Deep sleep + RTC wake (cadence) ✅ bench-verified

- After refresh, enter deep sleep with an RTC timer wake. **Production cadence is 1–3×/day (default 3, ≈8 h between wakes)** ([POWER.md](POWER.md)); a 6h (4×/day) cadence is acceptable for a mains-powered dev unit but should be a config/build constant, not hardcoded, so production can dial it back.
- Cache last `Last-Modified` + framebuffer in flash so a failed fetch shows stale content (`CONNECTIVITY.md:53`).
- Handle clock drift / NTP resync across sleep windows.
- **Done when:** device wakes on schedule, fetches, refreshes only on change, returns to deep sleep; survives power-cycle showing the last good frame.
- **Status:** ✅ bench-verified on the E1001 (`firmware/deep-sleep/`, PR #127; marked bench-verified #130, operator checklist #128). RTC slow memory (`RTC_DATA_ATTR`) persists `Last-Modified` + a boot counter across sleeps, so a 304 wake returns to sleep without touching the panel — no flash framebuffer cache is needed since eInk holds the last frame for free. HTTPS for the production pull added in PR #144. Serial trace + bench power snapshot in [`firmware/README.md`](../../firmware/README.md#phase-status).

### Phase 5 — Resilience ✅ bench-verified

- Wi-Fi failure → show cached frame, back off, sleep (don't hammer; rate limit is 10/min).
- Handle 404 (unprovisioned/no config), 429 (rate limited — honor `Retry-After`), 5xx (render error).
- **Done when:** device degrades gracefully with the API down, wrong creds, and an unprovisioned id.
- **Status:** ✅ bench-verified on the E1001 (`firmware/resilient/`, PR #131). All five cases passed on the bench — API-down (`GET -> -1`), unprovisioned (`404`), Wi-Fi failure, rate-limit (`429` → 60 s back-off), and normal (one `200` draw then `304`); in every failure the panel kept its last good frame and the device slept and recovered on its own. Two correctness fixes over Phase 4: `checkBusy` records a timeout so `drawFrame()` aborts cleanly on a stuck panel, and the cached `Last-Modified` commits to RTC **only after a confirmed draw** (else a failed refresh would 304 the next wake and strand the panel). Operator bench-check steps in [`firmware/README.md`](../../firmware/README.md#phase-status).

### Phase 6 — Captive-portal provisioning (issue #39) ✅ bench-verified

- Replace hardcoded Wi-Fi + device id with AP-mode first-boot: SSID `InfoBento-XXXX`, captive portal, NVS storage, OS auto-launch responses, pinhole reset, optional custom-server-URL field (#80).
- Display the device id during setup so the buyer can pair from the web (#80).
- **Done when:** a factory-reset device can be set up end-to-end from a phone with no hardcoded secrets.
- **Status:** ✅ bench-verified on the E1001 (`firmware/provisioning/`, PR #133; bench-verified + E1001 pinhole pin **GPIO2** in PR #134). The full out-of-box flow was walked on serial: first boot → AP mode + captive portal → phone auto-launch → scan/join → NVS persist → reboot into provisioned. Web-side "forget Wi-Fi" (`POST /api/device/:id/forget`) merged in PR #132. Remaining provisioning UX polish + the custom-server-URL self-host hatch tracked in **#39**. (The later integrated build remapped factory reset from the pinhole to holding the **two white buttons** for 5 s — #171/#172; the GPIO2 pinhole remains on this provisioning-era sketch.)

### Phase 7 — Integrated build ✅ merged (PR #174, issue #173)

- `firmware/integrated/integrated.ino` folds the proven pieces into one sketch: captive-portal provisioning, the dual-orientation deep-sleep pull (`GET /api/device/:id/frames`), the green-button (GPIO3, ext1 wake) orientation flip, and factory reset via the two white buttons held 5 s (#171/#172).

### Remaining — Port to production (GDEH0576T81 + ESP32-C3)

- Grayscale validation on real hardware is done — issue **#57** is closed, with 4-level gray proven on the E1001; the production GDEH0576T81 panel is not yet sourced.
- Swap panel dimensions (920×680), confirm framebuffer translation holds at the new size, re-measure refresh + deep-sleep current against the [power budget](POWER.md).
- Move to ESP32-C3 for production deep-sleep savings (#57 notes ~40% lower sleep current).
- **Done when:** the same loop runs on production hardware within the documented power budget.

## Critical path to "first working firmware flash"

```
Phase 0 (mint device, API up)  ──► Phase 1 (blink) ──► Phase 2 (static frame — RESOLVES framebuffer translation risk)
   ──► Phase 3 (Wi-Fi pull loop)  ──► Phase 4 (deep sleep cadence)
   = first working firmware on dev hardware
Phases 5–6 = ship-ready (resilience + provisioning)
Phase 7 = integrated build (✅ merged PR #174); production port remains, gated on GDEH0576T81 sourcing
```

The earliest "it works" milestone — **end of Phase 4 on the reTerminal** — is **reached**, Phases 0–6 are all bench-verified (resilience and provisioning included), and Phase 7 shipped as the integrated build (PR #174). The remaining long pole is the production port, gated on sourcing the GDEH0576T81 panel (#57 closed — gray rendering proven on the E1001).

## Related issues

- **#57** — dev kit + validate grey rendering — ✅ closed (4-level gray proven on the E1001); production GDEH0576T81 panel sourcing remains the long pole
- **#39** — captive-portal provisioning UX polish (Phase 6 sketch bench-verified; #39 tracks the remainder) — _open_
- **#74** — `/api/pair` route + claim flow — ✅ done (PR #112)
- **#80 / #79** — device sticker + production spec (physical pairing bridge) — _open_; QR generator #78 ✅ done (PR #121)
- **#77** — SaaS-default hosting epic (server side — storage/auth/device-pull mostly built)

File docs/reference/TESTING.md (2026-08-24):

# Testing

## Framework

- **Vitest 3.x** — Fast, ESM-native test runner
- Tests live alongside source: `packages/*/src/**/*.test.ts`
- Run from project root: `npm test`

## Running Tests

```bash
npm test                    # All tests, single run
npm test -- --watch         # Watch mode (TDD)
npm test -- packages/core   # Filter by path substring
```

## Writing Tests

### File Naming

Place tests next to the code they test:

```
packages/core/src/
├── layout.ts
├── layout.test.ts    # Tests for layout.ts
├── index.ts
└── index.test.ts
```

### Test Style

```typescript
import { describe, it, expect } from 'vitest';
import { myFunction } from './myModule.js';

describe('myFunction', () => {
  it('should handle the happy path', () => {
    expect(myFunction(input)).toEqual(expectedOutput);
  });

  it('should handle edge cases', () => {
    expect(myFunction(edgeInput)).toEqual(edgeOutput);
  });
});
```

### What to Test

- **Core:** Layout calculations, type validation, config parsing
- **Data:** Provider fetch/parse logic, cache behavior, upstream error handling
- **Renderer:** Frame buffer generation, pixel correctness, boundary conditions
- **API:** Pure render endpoints (`/api/render`, `/api/preview`, `/api/validate`) as input → output; the stateful auth/pairing/config surface against in-memory SQLite — `createDb(':memory:')` per test, as in `packages/api/src/db.test.ts`
- **Web:** Component behavior (not implementation details), user workflows

### Testing Pure Functions

Most of the codebase is pure functions, which makes testing straightforward:

```typescript
import { frameBufferBytes } from '@infobento/core';

// Input -> expected output, no mocks needed
const result = render(config, device);
// Packed 2 bits per pixel; rows are byte-aligned, so derive the length
// from the helper rather than restating the formula
expect(result.data.length).toBe(frameBufferBytes(device.widthPx, device.heightPx));
```

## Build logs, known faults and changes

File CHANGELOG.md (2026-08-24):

# Changelog

## [0.38.4] - 2026-08-23

### Documentation

- **Repo-wide accuracy sweep ahead of the public flip (#239, #215, #242).** A three-agent audit checked every doc claim against the v0.38.3 code. Fixed: the README and product brief now list all 18 box types (holidays was missing) and drop stale version/blocker references; the Phase 7 firmware story corrected in four docs — `firmware/integrated/` is the merged Phase 7 build, what remains is the production-panel port; `DISPLAY.md`'s gray-level table was inverted (renderer is 0=white → 3=black); the design brief's provider, layout-cap, editor-UI, and gifting-flow claims were brought current; `CONNECTIVITY.md` no longer denies the shipped account system or claims a PWA; `API.md` now matches the real endpoints (`?dual=1` mode, scale default 3, structured validation errors, 28-route accounting); RFC status markers reflect what shipped; and the refresh cadence reads 1–3×/day (default 3) everywhere, with the power summaries honestly rescaled — including the public setup guide, which previously understated the default.

### Fixed

- **Root `package.json` description no longer advertises the removed calendar box (#242).** The npm/GitHub-facing description now names only box types that exist.

## [0.38.3] - 2026-08-23

### Security

- **`jose` 6.2.4 → 6.2.9 (#236).** Picks up upstream hardening in the token library the pairing flow depends on: JWE decryption now rejects colliding Key Management Parameters (6.2.9), enforces a single recipient for `dir`/ECDH-ES key management (6.2.8), and rejects malformed Base64URL, UTF-8, and ASN.1 input (6.2.5).

### Changed

- **Prod dependency bumps (#236).** `@hono/node-server` 1.19.15 → 1.19.17 and `hono` 4.12.32 → 4.13.3 — the hono minor brings upstream fixes for CORS `Vary` on OPTIONS preflight, a CSRF exemption for OPTIONS requests, and router wildcard matching.
- **Dev dependency bumps (#235).** `prettier` 3.9.5 → 3.9.6, `tsx` 4.23.0 → 4.23.12, `typescript-eslint` 8.63.0 → 8.67.0. Toolchain only — no shipped code affected.

## [0.38.2] - 2026-08-21

### Fixed

- **The editor's empty state pointed the wrong way, at a control that no longer existed (#233, #234).** It read _Use "Add Box" above to get started_, and both halves were wrong: the chip palette sits **below** the box list, and nothing named "Add Box" is in the markup — the palette is a set of grouped `+ Label` chips, and the dropdown that name referred to was removed some time ago. A first-time user opening the editor was sent looking upward for a button that isn't there. It now reads _Pick a box type below to get started_.

### Changed

- **Adding a box takes one click (#233, #234).** Each chip was a wrapper holding the add button plus a hover-revealed `×` that hid that type from the palette, with a collapsible "Hidden (N)" section to restore it. The primary action shared its hit area with a secondary one, and a per-user hidden set was carried in editor state to support it. The hide/restore feature is gone: one chip is now one button. Editor configs saved before this still load — the stored `hiddenChips` key is ignored and no longer written back out. The palette is also built once at startup rather than rebuilt on every box add, remove and edit, since it no longer depends on any state.

## [0.38.1] - 2026-08-21

### Fixed

- **The `v0.38.0` deploy could not build the browser bundle (#231, #232).** `safe-fetch.ts` imports `node:dns/promises`, and the `@infobento/data` barrel re-exported it. `packages/web` consumes that barrel, so Vite pulled a Node-only module into the browser graph and rollup failed on `"resolve4" is not exported by "__vite-browser-external"`. The guard now lives behind a `./safe-fetch` export subpath gated on the `node` condition, so the barrel is browser- and edge-safe again and an accidental web-side import fails immediately — `No known conditions for "./safe-fetch" specifier` — instead of producing a cryptic bundler error. The `types` condition is nested inside `node` as well, because a flat `types` is matched by TypeScript in every `moduleResolution` mode and let such an import typecheck clean before failing at bundle time. `v0.38.0` was never served: the deploy failed before its SSH steps ran, so production stayed on 0.37.0 rather than shipping a broken bundle.

### Changed

- **CI now builds what deploy builds (#232).** The web bundle was only ever built in `deploy.yml`, while `ci.yml` ran `tsc -b`, typecheck, tests, lint and format — none of which exercise Vite. A Node-only import reaching `web` therefore passed every pull-request check and failed only when a tag fired a deploy, which is how #231 shipped at all. The bundle is now part of the root `build` script rather than a step duplicated across workflows, so a third workflow cannot silently omit it, and CI's Node version was raised from 20 to 22 to match the deploy environment — a mismatch that would otherwise have let a Node 22-specific failure through the same gap.

## [0.38.0] - 2026-08-21

### Added

- **Public-holidays box type (#221, #223, #226).** Takes the set to 18. Sourced from Nager.Date — free, no API key, ~100 countries — and the first box built from the RFC 0003 rubric rather than picked ad hoc. It shows the next public holiday for a country with a day countdown derived at render time, so a payload cached for its full 12-hour TTL never displays a stale "in N days". The country code is constrained to two ASCII letters at both the schema and the fetch boundary: it is interpolated into the Nager.Date request path, and `GB/../../v2/Other` would otherwise have traversed to an unintended upstream endpoint. Case-insensitive deliberately, because every consumer already uppercases and rejecting `"gb"` from an API caller buys no security.
- **Shared SSRF fetch guard for user-supplied URLs (#225).** `safeFetch()` in `@infobento/data`, added ahead of the RSS headline box (#4) so no user-configurable URL source can proxy requests through the API server. HTTPS only; DNS resolved and then filtered against loopback, RFC1918, link-local (including cloud metadata at 169.254.169.254), the IPv6 equivalents, and IPv4-mapped IPv6 in both dotted and hex form. Redirects are followed manually so scheme and address are re-checked at every hop, under a hop cap. The response body is streamed against a size ceiling rather than trusting `Content-Length`, the whole request is bounded by an `AbortController` timeout, and the outbound request carries only a `User-Agent` — no cookies, auth, or caller-derived headers. 30 adversarial tests cover DNS rebinding, redirect-to-private, oversized bodies with a lying `Content-Length`, and slow-loris. Requires `node:dns/promises`, so this one module is Node-only; the rest of `@infobento/data` stays edge-safe.

### Fixed

- **The countdown box reported the wrong day count across a DST fall-back, and could render "NaN" (#226 review).** `countdown.ts` carried the identical arithmetic to the new holidays box in already-shipped code, found only because the review of the new box prompted a check of its sibling. Both operands are local-midnight timestamps, so a fall-back night spans 25 wall-clock hours and `Math.ceil(25/24)` reported 2 days for a holiday 1 day away. Separately, `Math.max(0, NaN)` is `NaN` — it propagates rather than comparing as less-than-zero — so a malformed date drew the literal string "NaN" as hero text. Both boxes now share `days-until.ts`, and both suites pin the shared helper so neither can regress alone.
- **Invalid dates are rejected by calendar validity, not just shape (#226 review).** A `YYYY-MM-DD` regex accepts `2026-13-99` and `2026-02-30`. The first produced an `Invalid Date` that the new NaN guard turned into a countdown pinned at "Today" for the full 12-hour cache window; the second rolled silently over to March 2 and counted down to the wrong day. A shared `isIsoDateString` in core checks shape and then round-trips the components, and the data fetcher reuses it so the schema and the fetch boundary cannot drift apart.
- **The holidays box no longer paints outside its own bounds (#226 review).** Its overdraw test was `inkIn(data, H, H)` — a loop that never executes — and could not have worked as written, since `render()` allocates a buffer exactly `H` tall and leaves no rows past the box to inspect. Rewriting it honestly against an undersized box surfaced two real defects: `drawHeroText` takes a `maxWidth` but no `maxHeight` and blits unconditionally, and `drawTextWrapped` blits its first line _before_ testing its height bound. Guarded at this box's call sites only — the same pattern is present in every hero box, and changing shared `draw.ts` semantics for all of them is tracked in #229.
- **The editor's country-code field no longer contradicts itself mid-typing.** A single letter passed the `if (!code) return` guard, hit the API, and reported "Country code not found or no upcoming holidays" — implying the code had been queried and rejected — while the field validator simultaneously said the input was incomplete.

### Documentation

- **RFC 0003 — box-type selection rubric and candidate evaluation (#220, #221).** A five-gate rubric for deciding which box types earn a place, applied to a slate of candidates, so the set grows by argument rather than by whichever integration was easiest that week. Writing it forced a durability audit of the existing providers and turned up several claims in the repo that no longer matched the code: the layout cap is a `MAX_ROWS` local derived from display height, not a `MAX_BOXES` constant; the `quote` provider already fetches a community mirror, which the audit's own gate-5 criteria had concluded no precedent existed for; UV is drawn as visible `UV:N` body text in the AQI box rather than carried invisibly; and `ipapi.co` was missing from the enumerated network footprint. Follow-ups filed for the eleven renderer fixtures still pinned at `y: 0` (#227) and a stale JSDoc claim in `horoscope.ts` (#228).

### Chore

- **Removed a stray `.ghost-prompt` committed to the repo root by #226.** An autonomous clone's worktree is its own repo root, so the existing `clones/` ignore rule did not cover a prompt file sitting at that root and a broad `git add` from inside the worktree swept it in. The prompt artifacts are now ignored by name. No secrets were exposed — the file held a task description only.

## [0.37.0] - 2026-08-20

### Added

- **Pollen and UV index box types (#212, #213).** Takes the set from 15 back to 17. Both reuse the Open-Meteo air-quality endpoint that `packages/data/src/air-quality.ts` already calls, so neither adds a provider or an API key. `uv` surfaces the WHO Global Solar UV band for a location — the `uv_index` reading was already being requested and only partially exposed on `AQIData`. `pollen` names the allergen a sufferer would actually notice today, ranked by European Aeroallergen Network risk band, with separate scales for trees and for grasses/weeds because 50 grains of ragweed is a High day while 50 grains of birch is only Moderate. It distinguishes three states deliberately — a reading, a genuine all-clear ("None detected"), and no coverage at all ("No data") — because Open-Meteo serves pollen in Europe during season only, and conflating an all-clear with an absence would mislead the person relying on it.

### Fixed

- **In-row edits now persist, and a newly-paired device gets configured (#116, #191, #192, #204).** All three issues lived in the same web→device config push path, so they were fixed together rather than as three partial changes to one mechanism. `updateConfig()` and `updateConfigList()` mutated `box.config` and re-rendered the preview but never called `persist()` — every other mutator in `state.ts` did — so an edit like the Date box's "show year progress" updated the preview and reached neither localStorage nor the device. Selecting a device that had never been configured now seeds it from the editor's current boxes immediately, instead of leaving it configless while `/frames` returned 404 and the physical unit sat on the setup screen despite pairing and Wi-Fi provisioning both having succeeded. The editor's config read moved to a session-gated `GET /api/me/device/:id/config`, so it no longer depends on the firmware-facing route where the device id alone is the bearer secret.
- **A transient decode failure no longer overwrites a device's real config (#204 review).** An undecodable response body was caught and treated as "device has no config", which routed into the seeding path and PUT the editor's local boxes over whatever the device actually had — silent data loss on a network blip. It is now treated as the transport failure it is.
- **Wrapped text no longer paints into the wrong box (#213 review).** `drawTextWrapped` returns the height it consumed, not an absolute row, but the new UV and pollen placeholders assigned that return straight to a framebuffer Y. Any box not anchored at the top of the panel painted its secondary line into whichever box occupied the first few dozen rows. The renderer test fixtures pinned boxes at `y = 0`, where a height delta and an absolute row are the same number, so the suites could not see it; both now cover an offset box. `aqi.ts` carries a related defect and is tracked separately in #218.
- **Open-Meteo error payloads no longer cache as missing data (#213 review).** The API answers a bad request with HTTP 200 and `{"error":true,"reason":"..."}` and no `current` key, so dereferencing it threw a `TypeError` that the caller's outer `catch` flattened to `null`. A transient rate-limit was therefore indistinguishable from "no reading available today", and the false negative was cached for the full TTL. A shared `readCurrent` guard now covers the UV, pollen, and air-quality providers alike — the last of which had the same latent defect on the same endpoint.
- **Selecting a device no longer flashes the editor (#204 review).** `saveNow()` already dropped to local mode on 401/404, and `selectDevice()` did it again on any failure, re-running the localStorage reload and the render hook for a visible repaint. The save path now reports a three-way outcome so callers can tell "the save failed" from "the save failed and I already exited".

## [0.36.0] - 2026-08-19

### Removed

- **The calendar, habit, and joke box types are gone (#210, #211).** A value-rating pass over all 18 box types put these three at the bottom, and the two lowest scores turned out to mark a structural weakness rather than a matter of taste: `calendar` and `habit` were the only box types with no data provider, so they could change only when their owner opened the web editor — close to inert on a panel that refreshes once or twice a day with no input device. `docs/hardware/CONNECTIVITY.md` had already flagged the calendar box as a known gap pending phone integration. `joke` was live but the lowest-rated of the live boxes, and carried an external API dependency plus a bundled fallback set. Removing them also retired the editor's generic list-editor machinery, which had no other consumers. The pitch copy in the README, product brief, and Kickstarter draft no longer leads with "what's next on your calendar".

### Added

- **Provider cache TTLs now scale to the configured refresh interval (#193, #194).** Fixed per-provider TTLs silently capped fast refresh settings — a device pulling every 15 minutes showed the same quote for six hours. Each provider's freshness ceiling is now scaled down to the device's own pull rate, so the Refresh interval in the editor governs how often boxes actually fetch new content.

### Fixed

- **Configs naming a removed box type still load (#211 review).** Three rounds of review on the removal each surfaced a real defect in the backward-compatibility guard, all fixed here. Stored device configs are stripped of unknown box types before Zod validation, so one stale box no longer fails the whole config and hides every remaining box from its owner. The same guard runs on the localStorage and file-import path, where an unknown type previously reached `buildConfigForm` with no matching form builder and threw. The filter narrows untrusted JSON safely, so a `null` or primitive element in a boxes array is dropped rather than throwing. And an import whose boxes are _all_ stale now reports failure instead of committing an empty layout — `importJSON` only alerts on a false return, so the previous behaviour wiped the user's boxes and looked like a clean import.

### Security

- **A live pair code was published and has been removed (#201).** The setup guide's example sticker image showed the real bench device's pair code and Device ID from a world-readable path on www.infobento.com. Replaced, with the practice documented so it cannot recur.
- **Firmware TLS and bearer-secret exposure documented (#203).** Every sketch that speaks HTTPS calls `client.setInsecure()`, disabling certificate validation, while the device id travels as a bearer secret in the URL path. This documents the posture plainly rather than fixing it; #145 remains open.

### Documentation

- **Public-release corrections pass (#205).** Inaccurate and stale claims corrected ahead of going public.
- **BOM and pricing set from researched figures (#207, #208).** Campaign pricing reworked to $109 early bird / $129 standard / $239 pair so it clears its own costs, with the bill of materials priced against real distributor listings rather than estimates.
- **Founder bio locked (#209).**
- **NOTICE file and npm package metadata added (#201).**
- **README badges for website, licensing, TypeScript, and MCU.**

### Changed

- **The product model and campaign copy are no longer tracked (#206).**
- **Dependency bumps:** production dependencies (#198), development dependencies (#196), and `actions/setup-node` 6 → 7 (#197).

## [0.35.1] - 2026-07-05

### Documentation

- **Setup-guide sticker image is now a real pairing sticker (#188, #189).** The guide's example sticker is rendered from the bench device's actual pairing record instead of the sample CSV. The pair code shown resolves only against the local dev database, so the published QR cannot claim anything on production. Also corrects CLAUDE.md: the web app is public at www.infobento.com — assets under `packages/web/public/` are world-readable, and production pair codes / Device IDs must never be published.

## [0.35.0] - 2026-07-04

### Added

- **First-time user setup guide — web pages + single PDF (#181, #182).** New `/setup-guide` page linked from the site header: six steps from unboxing to designing your bento, each pairing instructions with "what you'll see" expectations for the device, your phone, and the website. The device-screen image is rendered from the same framebuffer baked into the firmware (regenerated by `gen-reset-screen.ts`, so guide and firmware can't drift); the captive portal, pair page, editor, and pairing sticker are real captures. A PDF version is generated at web-build time from the same content module and served at `/setup-guide.pdf`, with the release version stamped on every web page and every PDF page.
- **Default location falls back to London, UK (UTC+0) when detection fails (#183, #184).** Detection now goes same-origin `GET /api/geolocate` (server-side ipapi.co lookup that tracker blocklists like Firefox ETP can't block, with 24 h per-client-IP caching of successes) → direct ipapi.co → the London fallback filling empty rows of every location-parameterized box type. The fallback is a persisted guess — never recorded as the known location — so the next visit retries real detection and a success replaces rows still holding it, while user-edited rows survive. One canonical `LOCATION_PARAM_TYPES` set now drives detection, propagation, and fallback.
- **Date box year-progress is opt-in (#170, #179).**
- **Firmware setup screen step 3 now tells the user to enter the Device ID (#176).**

### Fixed

- **Claude review gate was silently vacuous since June 20 (#185, #186).** In agent mode the review action doesn't inject PR context, so every review "succeeded" in ~4 turns posting nothing. The workflow prompt now names the repo and PR explicitly, requires a "🔍 Review verdict" summary even at zero findings, and a tripwire step fails the check when a run posts no comments.
- **Landscape toggle persists across reloads and defaults to landscape (#159, #180).**

### Changed

- **CI now type-checks the web package (#177, #178).**

### Documentation

- **CONTRIBUTING.md documents the review gate (#187):** label-cycle trigger, expected verdict output, tripwire semantics, and the admin-merge policy for self-modifying review-workflow PRs.

## [0.34.1] - 2026-07-02

### Fixed

- **Date box no longer breaks the editor's live preview.** A config containing a date box threw `ReferenceError: box is not defined` inside `toBentoConfig` (the date case referenced an undefined `box` instead of the `editor` parameter, introduced in the #168 location work). Because that runs in the preview path, the exception aborted the editor's render and the live preview stayed blank on every platform whenever a date box was present. Fixed the reference and added a regression test. (Root cause it slipped through: the `web` package isn't in the root `tsc -b` typecheck graph, so the undefined identifier wasn't caught at build time — wiring web into CI typecheck is tracked separately.)

## [0.34.0] - 2026-07-02

### Added

- **Optional explicit location on the date box (#168).** The date box can now carry its own location (geocoded like the weather boxes), so it renders the correct local date even in a layout with no other location-bearing box. Precedence at pull-time hydration: the date box's own location → a co-located box's timezone (a weather box's already-fetched offset, else the first located box) → the server clock. The location is optional — leaving it blank keeps the zero-config derivation from #166 — and a standalone date box now participates in the editor's IP-based location auto-fill, so it picks up the user's timezone with no manual setup.

## [0.33.0] - 2026-07-01

### Added

- **Combined dual-orientation frame pull (`GET /api/device/:id/frames`, #160, #163, #164).** One request returns both the landscape and portrait framebuffers, with the portrait half pre-rotated server-side into the panel's fixed landscape raster and per-orientation byte lengths declared in `X-Frame-Landscape-Bytes` / `X-Frame-Portrait-Bytes` headers. A device can cache both frames and flip orientation locally with no network round trip, and its upload path stays orientation-agnostic (no on-device transform).

### Fixed

- **Date box now renders the device's local date, not the server's (#166).** The date box computed the date from the server clock (UTC in production), so a device west of UTC showed tomorrow's date after mid-afternoon local. Pull-time hydration now resolves the device location's UTC offset — reusing the offset the weather box already fetches, or a single lookup from another located box when there's no weather box — and the renderer anchors the date to it. With no location configured anywhere, it falls back to server time as before.

### Changed

- RFC 0002 documents the manual orientation toggle on the reTerminal E1001 via the green button (not the reset pinhole); Phase 5 resilience marked bench-verified (#160, #161, #162).
- Routine dependency bumps: prod and dev dependency groups, `actions/checkout` 6 → 7 (#148, #155, #156).

## [0.32.0] - 2026-06-24

### Added

- **Configurable display refresh interval (#152).** A new **Refresh** preset control in the editor (Off → every 15s, default every 8h) sets how often the panel is updated with newly-sourced data. It maps to `refreshesPerDay` (now `0..5760`, where `interval = 86400 / refreshesPerDay`; `0` disables scheduled refresh) and is carried through the exported config. The API derives the data-freshness bucket from it and sends an `X-Refresh-Interval` header on each frame pull; the firmware reads that header and re-times its deep-sleep accordingly (clamped 15s–24h, retained across sleep) — so the editor setting drives a real device end-to-end with no reflash. `IB_SLEEP_SECONDS` becomes the firmware's cold-boot/fallback default (production: 8h).

## [0.31.1] - 2026-06-24

### Fixed

- **All live box data now refreshes on every device pull — not just weather (RFC 0001 §2).** Pull-time hydration previously re-resolved only `weather`, so `forecast`, `forecast3d`, `sun`, `aqi`, `stocks`, `horoscope`, `onthisday`, `quote`, and `joke` boxes redrew the snapshot baked in at edit time and never changed day-to-day — even though the panel was correctly redrawing at each cadence window. Every provider is now re-resolved through the shared in-process cache (per-provider TTL, single-flight herd dedup, upstream timeout): data-bearing boxes fall back to the renderer placeholder on failure, while text-bearing boxes (`horoscope`/`onthisday`) keep their last reading. `quote`/`joke` gained persisted `tags`/`categories` request filters (added to the config schema and carried across the editor round-trip) so their daily-random refresh keeps the user's steer.

## [0.31.0] - 2026-06-20

### Added

- **Pull-time data hydration + freshness (RFC 0001 Phases 3–4).** The API re-resolves live weather server-side on each device pull — through an in-process TTL cache with single-flight and an upstream timeout — and advances `Last-Modified` at each cadence window (`effectiveLastModified`, bucketed on the denormalized `refreshes_per_day`). A device now shows **current** data on every scheduled refresh without anyone re-opening the editor, instead of a frozen snapshot of the last edit. `INFOBENTO_DATA_BUCKET_SECONDS` overrides the bucket for bench testing.
- **Firmware HTTPS for the deep-sleep pull.** A compile-time `IB_API_TLS` toggle (default on) switches the deep-sleep sketch to `WiFiClientSecure` + `https://`, so a flashed device can reach the production server (`www.infobento.com`) and not just a LAN dev API.

## [0.30.0] - 2026-06-20

### Added

- **`@infobento/data` shared provider package (RFC 0001 Phase 1).** Consolidated the 10 box-data providers (weather/forecast/sun/AQI + quote/joke/horoscope/on-this-day/stocks) into a new pure, browser-/edge-safe package with a `Cache` interface (TTL + stale-while-revalidate + per-key single-flight) and a global Nominatim 1 req/sec queue. `server.ts`'s proxy routes are now thin wrappers, so the web editor and (future) pull-time hydration share one implementation.
- **Operator device-mint CLI.** `npm run mint -w @infobento/api` (compiled into the deployed build) registers a device row + pair code on the production host, so a provisioned device can be claimed under **Devices** — closing the gap where minting was only possible via an undeployed script.
- **Web-side "forget Wi-Fi."** `POST /api/device/:id/forget` lets an owner remotely queue a credential reset that the device picks up on its next pull (`X-Device-Forget` header) — the web equivalent of the physical pinhole reset.
- **Per-device QR sticker generator.** `scripts/generate-stickers.ts` produces SVG/PDF pairing artwork from a CSV of device IDs and pair codes.
- **Firmware deep-sleep pull loop (Phases 4–6).** RTC-timer wake with `Last-Modified`/`304`-skip to protect the solar/battery budget, resilience handling for provider/network failures, and a captive-portal provisioning sketch for first-boot Wi-Fi setup.

### Fixed

- **`@infobento/data` provider hardening.** An unrecognized stocks `duration` now returns `null` → `400` instead of silently degrading to `1d`; `STOCK_RANGE_MAP` is frozen; `fetchForecast` caps the span at Open-Meteo's 16-day max; and the hourly forecast anchors to the location's timezone so a UTC server selects the correct hour.
- **OAuth start misconfiguration is now visible.** A missing client id logs a warning and redirects with `?auth_error=oauth_unconfigured` instead of failing silently.
- **`better-sqlite3` native binary rebuilt after `npm ci`.** The deploy now runs `npm rebuild better-sqlite3`, so opening the DB no longer 500s with a missing-bindings error.
- **E1001 pinhole reset pin corrected** to GPIO2 (J2 header pin 4); Phase 6 marked bench-verified.

### Changed

- **Deploy contract hardened.** The systemd unit is version-controlled (`deploy/infobento.service`) and refreshed on deploy; local dev SQLite files (`dev.db*`) are gitignored.

### Documentation

- **RFC 0001 — server-side fresh-on-pull data resolution.** The multi-phase design for moving live box-data fetching from edit-time to device-pull time (Phase 1 ships in this release).
- **Firmware bench bring-up.** Phase 1–3 sketches + README, a Phase 4 operator bench-verification checklist, and Phase 4 marked bench-verified.

## [0.29.0] - 2026-06-15

### Added

- **Drop-in device config export.** The editor's `Export` now emits a renderer `BentoConfig` — including the active device profile's `width`/`height` — so the downloaded file loads straight into a device's stored `config_json`. `Import` accepts this shape (and still reads legacy version-1/2 files), so exported configs round-trip back into the editor. Previously the export omitted dimensions, which made the renderer fall back to its default resolution and garble the panel.

### Fixed

- **Live preview no longer renders blank.** `preview.ts` referenced `getDeviceProfile`/`getCornerRadius` without importing them; the runtime `ReferenceError` was swallowed by the preview's silent catch, so the server-rendered frame was fetched but never mounted (it only appeared after toggling orientation).
- **Strict typecheck restored for editor state.** `hydrateBoxes` (localStorage config hydration) now type-checks cleanly — the config cast narrows through `unknown`, and split markers keep their `'left' | 'right'` literal type. No behavior change.

### Documentation

- **reTerminal E1001 bench walkthrough.** Added `docs/hardware/walkthrough-E1001-hw-setup.md` — the verified hardware bring-up: toolchain, framebuffer translation, and the Wi-Fi + device-pull loop (flashed and confirmed on hardware). Firmware Phase 0 (device-minting) marked done.

## [0.28.0] - 2026-06-14

### Added

- **Device pairing claim flow.** A signed-in user binds a physical device to their account by its printed pair code: `POST /api/pair` (session-authenticated, per-account rate-limited, with 404-vs-409 disambiguation) plus a `/pair/:code` web page reached from the device's QR deep link. (#112)
- **Account binding + cloud-config switch in the editor.** Signed-in users with a paired device now read/write that device's config server-side instead of `localStorage`, so edits reach the real device: header-menu sign-in (Google/Apple OAuth) and a Devices panel (list / switch / unpair), debounced cloud saves via `PUT /api/device/:id/config` (auth + ownership), and a `GET /api/me/devices` listing. Signed-out users keep the local-only flow unchanged. Unpairing wipes the stored config so it can't leak to a future owner. (#113)
- **Device-minting path.** A `mintDevice` helper and `scripts/mint-device.ts` CLI create a device record with a unique, unambiguous 6-char pair code (optionally seeding a starter config) — the missing first step before a device can be paired. (#109)

### Fixed

- **Reference config validates against the schema.** `docs/reference/infobento-config.json` was stale; it now satisfies `BentoConfigSchema` (box ids, config-type discriminators, `refreshesPerDay`). (#111)

### Documentation

- **Firmware bring-up plan.** Added `docs/hardware/FIRMWARE_BRINGUP.md` — the dev-first path to a first working firmware (reTerminal E1001 → production GDEH0576T81). (#107)

### Dependencies

- Bumped the prod-dependencies group (2 updates) and the dev-dependencies group (3 updates). (#114, #115)

## [0.27.0] - 2026-06-08

### Changed

- **Antialiased box corners.** Rounded corners are now smoothed with 3× supersampling, replacing the hard dark→white step with a soft light-grey band tracing the curve.
- **Compact hourly/daily forecast.** The condition text now sits just past the temperatures (column sized to the actual widest temp) instead of after a fixed wide column, tightening each row horizontally while keeping columns aligned.
- **Preview matches real hardware size.** The simulated display renders 1.5× larger so its on-screen physical size matches the real panel — the CSS 96px-per-inch reference under-sized it on high-DPI monitors (calibrated against the reTerminal E1001).
- **Corner radius range capped at 7** (was 10); saved values above the new max are clamped down on load.

### Fixed

- **White bars at the simulated display edges.** The eInk preview backing was white, so the rounded-corner clip and any letterboxing flashed light bars against the dark field; the backing now matches the field colour.

## [0.26.0] - 2026-06-08

### Added

- **Font Weight control.** A new slider sets body text weight across the full range of Inter static weights (Thin → Black, 100–900; default Regular), backed by all nine weight files. Headings and hero numbers render a few steps heavier to preserve hierarchy. The weight is threaded explicitly through the renderer's font metrics — no global state, `render()` stays pure — and the API validates it on a 0.1 step grid. (#105)

### Changed

- **Proportional text anti-aliasing.** Glyph edge coverage now maps proportionally across each text color's own tonal range instead of snapping to fixed thresholds and clamping to the fill color — so dark-grey text gets a real white→light→dark edge ramp rather than a flattened, harsh edge. Paired with **3× supersampling** (10 coverage levels vs the previous 4) for smoother curves at every size. (#105)
- **Dark render background.** The gaps and margins between boxes now fill dark grey so the white boxes float on a dark field, and the editor's preview backdrop is black. (#105)

## [0.25.1] - 2026-06-08

### Fixed

- Boxes that don't fit the panel (shown below the "won't fit" divider) are now marked with a **red accent** — card border, header rule, and focus/hover — at full strength, instead of being greyed out. They stay fully legible and editable. (#103)

## [0.25.0] - 2026-06-08

### Added

- **Adjustable forecast counts.** Hourly and Daily forecast boxes now have a −/+ stepper for how many hours/days to show — Hourly 1–24, Daily 1–20 (daily capped at Open-Meteo's 16-day limit), default 3. The renderer, fetch, and Zod validation all honor the configured count. (#102)
- **Grouped, always-available Add-box palette.** Box-type chips are organized into themed groups (Weather & Sky, Time & Dates, Personal, Fun & Discovery, Utility) and stay visible at all times; any box type can now be added more than once. Each chip has a hover × to hide it, and hidden chips collapse into a persisted "Hidden (N)" list that restores on click. (#102)
- **"Won't fit" editor indicator.** When a layout's content can't fit the panel, the box list de-emphasizes the dropped boxes and shows a divider naming them, updating live per orientation. (#102)

### Changed

- **Box headers show the editor label + a font-scaled icon.** With "Show Box Headers" on, every box renders its editor label verbatim (its own case) beside the box-type icon, which now scales to the font size instead of a fixed 28px. Default labels are durable ("Hourly Forecast" / "Daily Forecast") regardless of count. A shared `drawBoxHeader` helper removes the header code previously duplicated across all box renderers. (#102)
- **Temperatures show just the degree symbol** ("62°", "H:68° L:55°"), with the value following the IP locale — °F values in the US (and a few territories), °C elsewhere. The weather box is more compact: the condition wraps one word per line beside the hero temperature. (#102)

### Fixed

- **Over-stuffed layouts no longer lose part of a merged row or render invisible boxes** on short panels (e.g. the reTerminal E1001 in landscape). The layout caps visual rows (not raw boxes) and drops overflow rows whole at a row boundary — never severing a merged pair or starving a box to 0px — based on content-aware height. (#102)
- **The eInk preview no longer clips behind the editor.** A wide landscape preview scales to fit its cell (via `max-width` + `aspect-ratio`) instead of being cut off on the right. (#102)

## [0.24.0] - 2026-06-07

### Changed

- **opentype.js upgraded 1.3.4 → 2.0.0.** The 2.x release runs GSUB layout substitution inside `Font.getPath`, which throws on Inter's unsupported lookup type (6 / substFormat 2) and would break all TTF text rendering. The renderer now positions each glyph via `glyph.getPath` through a shared `walkGlyphs` helper (advance + kerning applied, composite glyphs resolved) — behavior-neutral versus 1.x. (#101)
- Dependency maintenance: safe in-range npm updates applied, and Dependabot now ignores npm major bumps so they can be migrated manually. (#99)
- CI: `actions/setup-node` bumped 4 → 6 and `actions/checkout` bumped 4 → 6. (#94, #95)

## [0.23.2] - 2026-06-07

### Fixed

- Exported config JSON now preserves merged rows. `exportJSON` had dropped `split`/`splitRatio`, so an export→import round-trip lost every merged row and its divider position. Export and persistence now share one serializer, and import also restores `fontSize`/`cornerRadius`/`padding`. (#98)

## [0.23.1] - 2026-06-07

### Added

- Standard GitHub community-health files: Code of Conduct (Contributor Covenant 2.1), `SECURITY.md`, pull-request and issue templates, Dependabot config (weekly npm + GitHub Actions updates), and `CODEOWNERS`. (#93)

## [0.23.0] - 2026-06-07

### Added

- **Open-source-hardware licensing** — Apache-2.0 for software (`LICENSE`), CERN-OHL-P-2.0 for hardware (`hardware/LICENSE`), and CC-BY-4.0 for docs (`docs/LICENSE`); all three permit building and selling devices from the design. `LICENSING.md` explains the split and SPDX identifiers were added to every `package.json`. (#92)
- **Simulator display-resolution selector** — the web preview switches panels via a `DEVICE_PROFILES` list in `@infobento/core` (default: Seeed reTerminal E1001 7.5" 800×480; also the 5.76" GDEH0576T81 920×680). The preview renders at the panel's **true physical size** (96px = 1in), so a lower-resolution 7.5" panel correctly appears larger than the 5.76" one. `renderBoth()` now derives both orientations from the selected panel.
- **Merged-row divider slider** — `splitRatio` is now a numeric width percentage (20–80) with a fine slider instead of three fixed positions; legacy 1/2/3 values migrate to 33/50/67.
- **Location rows default to your location** — weather, forecast, sunrise/sunset, and air-quality rows auto-fill from IP-based detection (no permission prompt) on startup and when added; the config form then fetches data automatically.

### Changed

- **Display described neutrally as "eInk"** — the color-vs-monochrome decision is tabled; dropped "B&W" / "2-bit grayscale" product claims across the docs, `CLAUDE.md`, and the web UI.
- **Reconciled all documentation and the project model to the 5.76" GDEH0576T81 spec** (920×680, 198 DPI, SSD2677) and removed the round-by-round design-history scaffolding so the docs present only the current design.
- **Editor add-box chips** are hidden once that box type is in use, and now flow directly after the boxes instead of being pinned to the bottom of the column.
- Prototyping now targets the off-the-shelf Seeed reTerminal E1001 (7.5", 800×480) with the GDEH0576T81 as the production target (`docs/hardware/DISPLAY.md`).

### Removed

- **Sensor / presence / interaction bundle** (Core AQ + Presence) and its docs (`docs/hardware/SENSORS.md`, the paired-system RFC) — the product is a calm dashboard.
- **Box-height S/M/L (weight) controls** — content-aware auto-sizing supersedes them.
- Dead prototype editors (`prototypes/`).

### Fixed

- `splitRatio` Zod validation now accepts the numeric percentage (was hard-coded to 1/2/3, which would reject the new slider values).
- Flaky `auth/session` signature test made deterministic.
- Simulator landscape preview no longer clipped by the editor column.
- Claude review workflow tool allowlist fixed so PR reviews post reliably.

## [0.22.0] - 2026-04-29

### Added

- **Device-pull config and frame endpoints** — `GET /api/device/:id/config` returns the bound `BentoConfig` JSON; `GET /api/device/:id/frame?orientation=landscape|portrait` returns the rendered 2-bit framebuffer bytes (~157 KB per orientation). Both endpoints carry `Last-Modified` headers and honor `If-Modified-Since` with `304 Not Modified` (second-precision compare). The device id is the bearer secret (no auth header — long opaque token, treated like an API key). Per-device-id token-bucket rate limiter at 10/min in-memory, returns `429` with `Retry-After: 60` when exceeded. New `packages/api/src/device.ts` (pure helpers) + `packages/api/src/rate-limit.ts` (token bucket); 21 new tests cover 200/304/404 paths, rate-limit enforcement, corrupt-config 500, orientation default. Closes #75. Part of epic #77 (SaaS-default hosting).

### Documentation

- Reconciled `README.md`, `docs/product-brief.md`, and `.tux/project.json` with the v0.21.0 code: 18 box types (no longer mentions removed `tasks`/`worldclock`), correct 8-hour / 8-day forecast labels, corner radius 0–10, version v0.21.0, and a Round 13 implementation note covering v0.15.0 → v0.21.0 (auth, type switcher, tasks/worldclock removal, stocks duration, location button, chip rail).

## [0.21.0] - 2026-04-28

### Changed

- **Add box chips** — replaces the two-step select + "Add Box" button with a wrapping row of pill-shaped chips, one per box type sorted alphabetically. Single click adds a box directly with no intermediate step.

## [0.20.0] - 2026-04-28

### Added

- **Location button on all location fields** — weather, forecast, 3-day forecast, sun, and AQI boxes now show a small location icon inline with the LOCATION label. Clicking it calls ipapi.co (no browser permission required) to detect the device's city via IP and fills the field immediately, also propagating to any other empty location boxes in the layout.

## [0.19.0] - 2026-04-27

### Added

- **Duration shown on rendered stock box** — the change line now appends ` · 1mo` (or whichever preset is selected) after the change/percent so a `+2.45 (+1.23%) · 1mo` move is unambiguous about its time horizon. No suffix when the box has no duration set, preserving the prior look for older configs.

## [0.18.0] - 2026-04-27

### Added

- **Stocks duration selector** — every stocks box now carries a `Duration` dropdown alongside `Symbol`, with seven presets: 1 Day (default), 5 Days, 1 Month, 3 Months, 6 Months, 1 Year, 5 Years. Changing the duration triggers a debounced refetch and updates the change/percent against that range's baseline. New `StockDuration` type, `STOCK_DURATIONS` preset list, and `DEFAULT_STOCK_DURATION='1d'` exported from `@infobento/core`; Zod-validated. `/api/stocks` accepts a `duration` query parameter and maps it to Yahoo Finance `range`/`interval` pairs (`1d→2d/1d`, `1y→1y/1wk`, `5y→5y/1mo`, etc.); change is computed against `meta.chartPreviousClose` for `1d` and against the first non-null close in the returned series for longer ranges.

## [0.17.0] - 2026-04-27

### Added

- **Landscape preview toggle** — preview shows one orientation at a time (portrait by default), swapped by a new "Landscape" checkbox in the preview controls. Both PNGs are still fetched in one round-trip so the toggle is instant. Replaces the always-on dual-preview layout.

### Changed

- **Editor cards reflow horizontally and tighten vertically** — the box-config form inside each card uses flex-wrap, so multi-field forms (date+label, city+entries, etc.) sit side-by-side when there's room and stack only on narrow widths. Tighter padding/labels/inputs and a 40px-min textarea (down from 72px) let several boxes fit on screen without scrolling at typical desktop widths.

### Documentation

- Reconciled `README.md`, `docs/`, and `.tux/project.json` with the actual code: 18 box types (was 15/17, with stale `tasks`/`worldclock` and missing `horoscope`/`joke`/`onthisday`); `forecast3d` correctly described as 3-day; dropped phantom "ESP32-L" mentions; surfaced tilt-switch hardware (REQ-012) in README and POWER.md; removed stale "Mid-pivot status" section from `ARCHITECTURE.md` (`DisplayId` is gone); aligned bezel spec at ≤4mm; bumped REQ-001 from "3-6" to "up to 10" boxes to match `MAX_BOXES`.

## [0.16.0] - 2026-04-26

### Added

- **In-place box type switcher** — every box-card header now carries a `<select>` that swaps the box's type without disturbing layout. `split` partner, `weight`, `splitRatio`, and ordering are preserved; `config` is reset to the new type's defaults; the label is overwritten with the new default only when it still matches the old default (so a user-edited label like "Today" survives a type change). New `changeBoxType(id, newType)` action in `state.ts`; `LABELS` exported as `BOX_TYPE_LABELS`. Tests cover type+config reset, default-label overwrite, custom-label preservation, layout preservation, and no-op self-swap. (#88)
- **Text box honors `\n`** — `drawTextWrapped` now splits on explicit newlines first and word-wraps within each segment, preserving blank lines from consecutive newlines. `countWrappedLines` (used by content-aware layout) gets the same treatment so multi-line text reserves the right height. Lets a single Text box function as a one-item-per-row list. (#84)

### Removed

- **Tasks** and **World Clock** box types removed end-to-end. A device that refreshes once or twice a day can't truthfully show a clock, and a checkbox list is overkill on a passive surface — newline-delimited text in a Text box now does that job (see above). 17 → 15 box types across `@infobento/core`, `@infobento/renderer`, `@infobento/web`. (#84)

### Changed

- `claude-review` GitHub Action `--max-turns` raised from 10 to 25 — medium-sized PRs (4–5 files across two packages, plus inline comments) routinely needed more than 10 turns. (#86)

### Notes

- Pre-existing user configs containing `tasks` or `worldclock` boxes will fail Zod validation on `/api/render` and render as placeholder boxes in the editor's preview. Acceptable break — pre-1.0, single-user product.

## [0.15.0] - 2026-04-26

### Added

- **SQLite storage layer** for the SaaS hosting tier — `accounts` and `devices` tables in a single file at `/var/lib/infobento/data.db` (override via `INFOBENTO_DB_PATH`). Helpers for account creation/lookup, device pair-code claim (idempotent per account, rejects cross-account claims), config write, and per-account device listing. Schema accommodates the planned passkey + OAuth columns without future migration. Foundation for epic #77. (#72)
- **Passkey + OAuth authentication** — `@simplewebauthn/server` for WebAuthn (registration + authentication ceremonies, sign-counter rollback rejection with 0→0 pass-through), `jose` for OIDC + PKCE flows for Sign in with Apple and Google. HMAC-signed session cookies (`{account_id, exp}`, 90-day TTL, HttpOnly, SameSite=Lax, Secure in production) decoupled from credential type. Stateless 5-minute challenge cookies bridge `/options`↔`/verify` and `/start`↔`/callback` without a server-side store. Account upsert surfaces a `linkedToExistingEmail` flag so the editor can confirm before linking, never silently merges. (#73)
- Seven new auth endpoints in `@infobento/api`: `POST /api/auth/passkey/register/{options,verify}`, `POST /api/auth/passkey/login/{options,verify}`, `GET /api/auth/oauth/{apple,google}/{start,callback}`, `POST /api/auth/signout`, `GET /api/auth/session`.

### Changed

- Production deploy workflow now forwards `SESSION_SECRET`, `RP_ID`, `RP_ORIGIN`, `OAUTH_REDIRECT_BASE`, and the Apple/Google OAuth secrets from GitHub secrets. The deploy script writes them to `/etc/infobento/auth.env` (mode 640, root:www-data) for the systemd unit to pick up via `EnvironmentFile`; values omitted from a given run preserve their prior value rather than wiping.
- README documents the new env vars and Apple Developer / Google Cloud OAuth setup for self-hosters.

### Notes

- Phase 2 of epic #77 (SaaS-default hosting). Remaining sub-issues: #74 pair-code claim flow, #75 device-pull config/frame endpoints, #76 web editor account binding.
- 30 new tests in `packages/api/src/auth/` cover session sign/verify (tampering, expiry, missing/short secret), challenge type-tag binding, passkey config + sign-count replay defense, and OAuth callback paths (state mismatch, fresh account, email link, idempotent re-sign-in, audience mismatch, provider error) via local JWKS + injected fetch.

## [0.14.0] - 2026-04-25

### Added

- **Bundled local fallback** for `/api/quote`, `/api/joke`, `/api/horoscope` proxies — when the upstream provider fails (network, non-2xx, empty), proxy returns a random matching entry from a built-in JSON set with `fallback: true`. Bundle: 243 quotes (filtered to ≤120 chars from quotable mirror, multi-tag), 37 jokes (Programming/Misc/Pun via JokeAPI safe-mode), 30 evergreen sign-agnostic horoscope readings (#71)
- Curated 5-box first-time-user default: `[Date | Weather]` merged + Forecast + Quote + On This Day, all auto-populated on first render. Replaces dev-test mocks (Portland weather + sample task/quote) (#70)

### Changed

- Geolocation hook (`detectLocation`) now triggers when the weather city is empty, not when it equals `Portland, OR` — supports the new empty-by-default config
- `npm run build` chains a `node scripts/post-build.mjs` step that copies non-`.ts` static assets (the fallback JSON bundles) from each package's `src/` into `dist/`. ESLint config ignores `**/*.mjs` matching the existing `.js`/`.cjs` convention

### Notes

- Fallback bundle came in at ~50KB total (Round 12 Q3 estimated ~180KB; lighter because of the quote-length filter + smaller-than-spec joke / horoscope sets)

## [0.13.0] - 2026-04-25

### Added

- Wired 5 box types (stocks, tasks, calendar, habit, worldclock) into the web editor — they shipped as renderers in v0.8.0 but only became user-configurable now (#53)
- Add Box dropdown gains: Calendar, Habits, Stocks, Tasks, World Clock
- List-editor primitive in `box-config.ts` (`buildListField`) used by tasks/calendar/habit/worldclock; per-row remove + bottom Add button
- Generic `updateConfigList` / `appendToConfigList` / `removeFromConfigList` mutators in state — in-row edits keep input focus; add/remove rows trigger setState rebuild

### Changed

- Layout engine now applies content-aware minimum heights to **all** box types, not just quote/horoscope/joke/onthisday (#54). Each box reports its renderer-specific height (header + content + padding); short-content boxes shrink so list-heavy boxes get the space they need.
- `extractWrappedText` replaced with a comprehensive `computeMinHeight` helper covering all 17 types

### Notes

- Stocks live price fetch is intentionally deferred — no free no-key quote API exists today. Box renders `No data` until a future release wires one in.

## [0.12.0] - 2026-04-25

### Added

- **On This Day** box: surfaces a Wikipedia event/birth/death/holiday for today's UTC date. Category dropdown (Events, Births, Deaths, Holidays, All) re-fetches on change. Server picks one entry randomly so the client never sees the full Wikipedia day payload (#61). Completes epic #62.
- "On This Day" entry in the Add Box dropdown
- On This Day box auto-resizes to fit text, matching Quote/Horoscope/Joke behavior

## [0.11.0] - 2026-04-25

### Added

- **Horoscope** box: pick your zodiac sign (12 options) and refresh for a daily reading via api-ninjas (#59)
- **Joke** box: optional category filter (Programming, Misc, Pun, Dark, Spooky, Christmas) with safe-mode and content blacklist always on, via JokeAPI (#60)
- Quote box optional **tag steering** — comma-separated tags (e.g. `wisdom, life`) steer random selection
- Quote box tag changes auto-refresh debounced (~500ms after last keystroke)
- "Horoscope" and "Joke" entries in the Add Box dropdown

### Changed

- Quote provider switched from `zenquotes.io` to the actively-hosted `api.quotable.kurokeita.dev` mirror — enables tag filtering and improves reliability
- `fetchQuote` retry-for-length loop dropped; server enforces `maxLength` upstream so a single fetch suffices
- Horoscope and Joke boxes now expand to fit their text, matching Quote box behavior

### Fixed

- Reordering an unpaired box around a split pair no longer strips the pair's split markers (which made the merge buttons disappear); existing corrupted localStorage state is repaired automatically on next load
- CHANGELOG.md prettier compliance — escape `*` so CI format check passes

## [0.10.0] - 2026-04-24

### Added

- Merge/split box pairs: "Merge into row" button between adjacent boxes creates a side-by-side split pair; "Split apart" undoes it
- [L]/[R] badges and blue accent group border on paired boxes in the editor
- Adjustable box height weight (S/M/L buttons on each box card) for proportional height allocation
- Adjustable split ratio (left arrow/equal/right arrow) on merged pairs for 1:3, 1:2, 2:3 width distribution
- +/- stepper buttons replace range sliders for font size, corners, and padding (better mobile UX)
- Preview and editor side-by-side on wide screens (>=1024px)
- Add box toolbar moved to bottom of editor

### Changed

- Previews stacked vertically (portrait first, landscape below)
- Show Box Headers toggle moved after stepper controls
- Layout engine distributes height by total weight instead of even split
- Merged row height uses max weight of the two boxes in the pair
- Quote boxes are always content-sized (S/M/L controls hidden)
- Quote author rendered as "— Name" on its own line in light grey (em dash, no wrapping issues)
- Quote height hints account for split pair width and correct line height

### Fixed

- S/M/L weight buttons now trigger full re-render (was preview-only)
- Quote height hint uses correct drawTextWrapped line height (fontSize \* 1.3)
- Right box in split pair was using left box's weight for height calculation

## [0.9.1] - 2026-04-24

### Fixed

- Quote box layout: author attribution positioned directly after wrapped text instead of at bottom of allocated space
- Quote height hint respects showHeaders flag and removes extra padding, giving weather/forecast boxes more vertical space at large font sizes
- drawTextWrapped returns actual pixel height consumed (was void)

### Added

- Product brief (`docs/product-brief.md`) — hardware, software, rendering, box types, power budget, competitive positioning
- Design brief (`docs/design-brief.md`) — work roles, user classes, design principles, requirements, scenarios, wireframes, config delivery, rendering pipeline

### Changed

- Enclosure shrunk from ~18x12cm to ~14x11cm to fit GDEH0576T81 panel closely
- Config delivery: captive portal for first-time setup + cloud poll for OTA updates
- Server-side rendering with device-side framebuffer caching for offline resilience

## [0.9.0] - 2026-04-24

### Added

- Debounced auto-fetch (500ms) on all city inputs — weather, forecast, forecast3d, sun, aqi update live as you type
- Auto-fetch random quote when quote box is added with empty fields
- Browser geolocation on first load — detects user's city and populates default boxes with real local data
- Bento box grid SVG favicon (replaces default React/Vite logo)
- CSS for `.weather-status` and `.btn-random-quote` elements
- Mobile-responsive preview controls — sliders wrap instead of overflowing on narrow viewports

### Changed

- Three-tier text contrast: hero text in dark grey (large, doesn't need max contrast), important body text in black, supporting metadata in light grey
- Portrait preview shown first, landscape second
- Box card headers: label input shrinks on mobile, remove button stays visible
- All docs updated from 1-bit to 2-bit grayscale terminology
- Kickstarter copy updated from color eInk to B&W GDEH0576T81 spec
- Consent dialog simplified — product descriptions removed, version bumped

## [0.8.1] - 2026-04-24

### Changed

- Default font size set to 38px (was 20px)
- Default boxes: Weather (Portland, OR), 8-Day Forecast (8 entries), Quote (Mark Manson)
- Default headers off
- Corner radius range extended from 0–5 to 0–10
- Device ID updated to `infobento-5.76`

## [0.8.0] - 2026-04-24

### Added

- 5 new box types: stocks, tasks, calendar, habit, worldclock — each with renderer, tests, 14x14 icons, types, and validation schemas
- Dynamic `FontMetrics` system replaces hardcoded font constants — all sizing derived from user-chosen body font size
- Content-aware quote height allocation — layout engine accepts height hints so quote boxes expand to fit wrapped text
- Antialiased rounded box borders using signed distance field (SDF) rendering
- `drawRoundedRect()` and `roundedRectSDF()` drawing primitives in `draw.ts`
- Grey background behind boxes (GRAY_LIGHT fill) with white box interiors
- Configurable corner radius (0–5) and display padding (0–10) with live web UI slider controls
- Font size max raised from 24px to 42px
- Display spec locked to Good Display GDEH0576T81 (5.76", 920x680, 198 DPI, SSD2677)

### Changed

- Layout engine derives padding and gap from `config.padding` instead of hardcoded constants (`BOX_DIVIDER_PX` and `DISPLAY_PADDING_PX` removed)
- Box gap matches edge padding for uniform spacing
- Split-pair boxes now have a gap between left/right halves
- Moon phase layout: bitmap vertically centered relative to text, divider clears whichever is taller
- Preview containers use CSS variable `--eink-radius` synced to framebuffer corner radius
- Preview shows full display area — orientation header labels ("Landscape 920x680") removed
- All docs updated from color eInk / Spectra 6 to B&W GDEH0576T81 spec

### Removed

- Per-box bottom divider lines (`drawHLine` rules) from all 16 box renderers — replaced by bordered boxes
- `BOX_DIVIDER_PX` and `DISPLAY_PADDING_PX` constants (now config-driven)

## [0.7.1] - 2026-04-23

### Fixed

- TTF rasterizer replaced with fast scanline fill — preview renders in ~200ms (was 504 timeout)
- Test suite runs in ~7s (was ~65s)
- Preview updates debounced by 150ms to avoid thrashing on keystrokes
- Empty-state message clears immediately when boxes are added

## [0.7.0] - 2026-04-23

### Added

- TrueType font rendering via opentype.js with Inter (OFL) — body 20px, hero 52px
- 4x supersampled anti-aliasing with 4-level grayscale output at native resolution
- 2-bit grayscale framebuffer (4 levels: white, light gray, dark gray, black)
- Gray level constants and optional `level` parameter on all drawing primitives
- `getPixel()` export for reading pixel values from framebuffer
- `setPixel()` now accepts gray level (0-3) instead of boolean
- Year progress bar with day count in date box
- CSS `image-rendering: pixelated` for crisp eInk preview

### Changed

- Display resolution upgraded from 240x200 to 920x680 (native)
- Replaced BSD-licensed Spleen bitmap font with Inter TrueType (OFL)
- Web preview now fetches server-rendered PNG from `/api/preview` (enables TTF rendering)
- Preview endpoint skips validation for live editing (renders placeholders for empty fields)
- Box headers: icons in light gray, labels in dark gray, divider rules in dark gray
- Date box simplified: removed week number/day-of-year options, added stacked layout with year progress
- Sun box simplified: stacked RISE/SET/DAY layout with aligned label columns
- Alphabetized add-box dropdown
- Box padding scaled for 920x680 resolution (4px → 16px)

### Removed

- Bitmap font data (5x7 body, 8x16 hero) — replaced by TTF rendering
- `showWeekNumber` and `showDayOfYear` config options from date box

## [0.6.0] - 2026-04-23

### Added

- New **8-day forecast** box type (`forecast3d`) with daily high/low temps and conditions
- `fetchForecast3D()` API helper using Open-Meteo daily forecast endpoint
- 7x7 pixel-art icon for 8-day forecast box header
- All box types (sun, aqi, moon, date, progress) now available in the add-box dropdown

### Changed

- Hourly forecast extended from 3 entries to 8 (label: "8hr Forecast")
- Daily forecast extended from 3 days to 8 (label: "8-Day Forecast")
- Location-based box headers now show the city name (e.g., "PORTLAND, OR" instead of "WEATHER")
- Applies to: weather, hourly forecast, daily forecast, sunrise/sunset, and air quality boxes
- Hourly forecast time/temp column spacing increased for readability

## [0.5.1] - 2026-04-23

### Fixed

- Claude Code review workflow: added `Read`, `Grep`, `Glob` to `--allowedTools` (reviews were silently producing zero comments); narrowed trigger to `labeled` event only (was triple-firing on PR creation)

### Added

- Production deploy workflow (`.github/workflows/deploy.yml`) modeled on webmap.dev: builds all packages + Vite, SSH deploys to DigitalOcean droplet, restarts systemd, health-checks `/api/health`, rollback on failure
- SSH retry helper (`scripts/ssh-retry.sh`) with exponential backoff
- Server-side deploy script (`scripts/deploy-infobento.sh`) with backup/extract/verify/rollback pattern

### Changed

- **REQ-009 upgraded to 2-bit grayscale**: v1 ships 4-level grayscale (black, dark gray, light gray, white) instead of 1-bit. All candidate panels support this natively at zero BOM cost. Enables anti-aliased fonts and tone-based visual hierarchy.
- Design principle renamed "1-Bit Elegance" → "Grayscale Elegance" with 4-tone hierarchy examples
- Two-Font Bitmap System principle updated: both fonts can be anti-aliased using grayscale edge pixels
- **REQ-012 updated**: IMU replaced with two mechanical tilt switches (zero standby current, ~$0.10 BOM)

### Documentation

- `.tux/project.json` fully audited: 22 stale color/clamshell/phone references fixed across description, requirements, design principles, scenarios, wireframes, hardware platform, market positioning, and campaign plan
- Round 11 annotation added to Round 10 RFC (#25)
- All open GitHub issues (#25, #36-39, #41-45) audited for stale color references and updated
- Issue #47 expanded: 21 panel candidates across 5 tiers with purchase links and spec pages, including budget 4.26" panels at $10-19 and 219 DPI
- Issue #52 created: 2-bit grayscale framebuffer + anti-aliased font rendering
- New issues: #47 (B&W panel sourcing), #48 (tilt switch hardware), #49 (auto-rotate software), #50 (SCAD enclosure), #51 (configurable dimensions)

## [0.5.0] - 2026-04-23

### Added

- 5 new box types: **date** (hero day number + day-of-week), **moon** (lunar phase with 20px bitmap), **sun** (sunrise/sunset via Open-Meteo), **aqi** (air quality + UV index via Open-Meteo), **progress** (year/custom range progress bar) (#41-45, PR #46)
- Web editor support for all 11 box types: type picker, config forms, live preview
- `fetchSunTimes()` and `fetchAirQuality()` in web API layer (Open-Meteo + Nominatim geocoding)
- 5 new 7x7 pixel-art icons for box headers (calendar, crescent, sunrise, leaf, progress bar)
- Moon phase computation from synodic period (reference epoch 2000-01-06T18:14Z)
- AQI category mapping (US EPA scale) and dominant pollutant display

### Changed

- **Collapsed dual-display to single-display model** (Phase 2, #29, PR #40):
  - Removed `DisplayId` type and `displayId` field from `BentoConfig` across all packages
  - Web editor: 2x2 grid → single column (preview on top, editor below)
  - localStorage schema bumped to v2 with backward-compatible v1 migration
  - CSS: grid layout → flex column, removed `.column-heading` and grid-area rules
- Claude Code review workflow: added `Read`, `Grep`, `Glob` to `--allowedTools` (was missing, causing zero review comments); narrowed trigger to `labeled` event only (was triple-firing)
- 73 → 100 tests (27 new tests for 5 box types; 1 removed: `displayId` validation)

### Strategic direction (Round 11, 2026-04-23)

- **V1 ships B&W only** (REQ-009) — color eInk deferred to v2. Phase 3 (#30-33) relabeled as v2.
- **Bento-box form factor** (REQ-010) — device sized ~18x12cm, golden-ratio display (1.618:1 target)
- **High DPI + minimal bezel** (REQ-011) — ≥200 DPI target, ≤3mm bezel
- **Tilt switch auto-rotate** (REQ-012) — two mechanical tilt switches, 4-orientation detection, zero standby current
- **Configurable display dimensions** (#51) — BentoConfig accepts optional width/height
- New hardware issues: B&W panel sourcing (#47), tilt switch hardware (#48), auto-rotate software (#49), SCAD enclosure (#50)

### Documentation

- Pivot Phase 1 strategic artifacts (#26, #27): README, hardware docs, architecture docs rewritten for counter-only
- Connectivity locked: Wi-Fi direct + PWA-only, ESP32-C3, captive-portal setup, no companion app
- Kickstarter copy draft committed (`docs/kickstarter-copy.md`)
- `.tux/project.json` fully audited and updated for Round 11 (B&W, bento, tilt switches, golden ratio)

## [0.4.0] - 2026-04-21

### Added

- All 5 MVP box types: countdown, weather, QR (qrcode-generator), quote, text
- Spleen 8x16 hero font embedded in renderer with `drawHeroText`/`drawHeroChar`
- Hero font + whitespace layout in all box renderers (replaces border-based design)
- Dual-display type system: `displayId: 'D' | 'P'` on BentoConfig
- Display toggle in web editor (D Phone / P Counter tabs)
- Client-side 1-bit canvas renderer in web editor (replaces CSS mock)
- localStorage persistence — config auto-saves and restores on page load
- JSON import button (completes export/import cycle)
- Vanilla JS web editor scaffold with reactive state (no framework)
- 128x296 portrait display resolution (standard 2.9" eInk panel)
- Preview images regenerated using real renderer pipeline
- OpenSCAD mockup for 3D printing (hardware/infobento.scad + STL)
- Physical mode diagrams: closed, peek 90°, counter ~100°, flat 180°
- Dual-display mode diagram with D/P/S/M surface labels
- 3-color (BWR) rendering prototype
- Font comparison: Spleen 8x16 vs Tamzen vs baseline

### Changed

- Display resolution: 240x200 → 128x296 (frame buffer 6000 → 4736 bytes)
- Form factor: 320° hinge → 180° standard friction hinge
- Price target: $25 → $30
- Battery placement: display half → solar half (grip flex safety)
- Folded thickness: ~8mm → ~7.2mm (dual display, thinner battery)
- Dual-display architecture: two 2.9" eInk panels back-to-back
- Preview script: 437 lines custom drawing → 230 lines render() calls
- Web editor: React stub → vanilla JS with reactive state
- Box renderers: borders → whitespace + thin rules + hero font

### Documentation

- Hardware design exploration (issue #22): component layout, GPIO allocation, BOM analysis
- 8 rounds of open question decisions captured in project model
- README rewritten for dual-display clamshell form factor
- All hardware docs updated (display, power, BLE, architecture)

## [0.3.0] - 2026-04-21

### Added

- PNG preview endpoint `POST /api/preview` with optional `?scale=N` upscaling (#19)
- REQ-008: live PNG preview requirement for web config experience
- MagSafe clamshell form factor design — 320-degree hinge, three physical modes (phone-mounted, counter-standing, collapsed)
- Hardware platform decision: ESP32-C3, solar drip charger, MagSafe reverse-charge
- Value proposition: "See less. Know enough." — anti-phone positioning for $25 Kickstarter
- Dual-mode power budget: low-power counter mode (1-2x/day) and phone-mounted mode (minute-level partial refresh)
- Phone-back peek scenario and updated morning glance scenario for new form factor
- Display resolution finding: 240x200 (codebase) vs 296x128 (standard 2.9" panels)

### Changed

- Project phase advanced from `design` to `implement`
- README rewritten around MagSafe clamshell form factor and value proposition
- Hardware docs (display, power, BLE) updated for dual operating modes and ESP32-C3
- Architecture docs updated with physical modes table and new system overview
- "Zero Daily Interaction" design principle refined to "Zero Device Interaction"
- Device Owner role and Desk Decorator user class updated for new form factor
- API docs: preview endpoint updated from "planned" to implemented

## [0.2.0] - 2026-04-13

### Added

- Core types: `TextBoxConfig`, `BoxConfig`, `LayoutBox`, `LayoutResult`
- Layout engine: `calculateLayout()` with QR-aware height allocation
- Embedded 5x7 bitmap font (ASCII 32-126, 95 glyphs)
- Drawing primitives: `setPixel`, `drawHLine/VLine`, `drawRect`, `drawChar`, `drawText`, `drawTextWrapped`
- Text box renderer with border, label header, and word-wrapped content
- Placeholder renderer for unimplemented box types
- 28 tests across layout, drawing, font, and integration

### Changed

- `render()` now calculates layout and dispatches to box-type renderers
- Constants extracted to `constants.ts` to break circular imports

## [0.1.0] - 2026-04-13

### Added

- Monorepo scaffold: `@infobento/core`, `@infobento/renderer`, `@infobento/api`, `@infobento/web`
- GitHub Actions CI pipeline and Claude review workflow
- Husky hooks: pre-commit, commit-msg (conventional commits), pre-push
- Hono server with same-port architecture (API + static web UI)
- Documentation: CLAUDE.md, CONTRIBUTING.md, AGENT_POLICY.md, AGENTS.md, 12 docs/ files
- tux UX model: 23 artifacts (work roles, user classes, design principles, requirements, scenarios, wireframes)

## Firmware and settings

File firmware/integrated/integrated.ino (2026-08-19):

// InfoBento firmware — Phase 7 integrated build (reTerminal E1001, issue #173).
//
// One sketch, no secrets.h. Unifies the previously-separate phases:
//   * captive-portal provisioning (#39 / firmware/provisioning) — now also
//     captures the DEVICE ID, and stores ssid/pass/server/deviceid in NVS,
//   * deep-sleep dual-orientation pull + green-button flip (#160 / #165), driven
//     by the stored NVS config instead of compile-time secrets, and
//   * the resident factory-reset screen + two-white-button reset (#171 / #172).
//
// Boot flow (setup()):
//   not configured (no deviceid/ssid)  -> draw setup screen, AP mode + portal
//   configured, cold/timer wake        -> Wi-Fi -> GET /frames -> draw -> sleep
//   configured, green-button wake       -> flip cached orientation, radio off
//   configured, white-combo wake        -> factory reset (draw screen, wipe NVS)
//
// Reset: hold BOTH white buttons (GPIO4 + GPIO5) 5s — works awake (AP loop) and
// from deep sleep (ext1 wakes on GPIO4, then we poll for the 5s combo). Green =
// GPIO3 (orientation flip when configured; reset-screen flip in AP mode).
//
// ⚠️ BENCH-MVP, NOT hardware-verified. Highest-risk item: reset-from-deep-sleep
// (ext1 GPIO3+GPIO4 + post-wake combo poll). Flash 8 MB:
//   arduino-cli compile -u -p /dev/cu.usbserial-XXXX \
//     --fqbn 'esp32:esp32:esp32s3:UploadSpeed=115200,FlashSize=8M,PartitionScheme=default_8MB' firmware/integrated

#include <WiFi.h>
#include <HTTPClient.h>
#include <WiFiClientSecure.h>
#include <WebServer.h>
#include <DNSServer.h>
#include <SPI.h>
#include <esp_sleep.h>
#include <LittleFS.h>
#include <Preferences.h>
#include "driver/rtc_io.h"
#include "reset_screen.h"

// ----- Panel (UC8179) + buttons --------------------------------------------
#define EPD_SCK_PIN 7
#define EPD_MOSI_PIN 9
#define EPD_CS_PIN 10
#define EPD_DC_PIN 11
#define EPD_RES_PIN 12
#define EPD_BUSY_PIN 13
#define EPD_W 800
#define EPD_H 480
#define IB_FRAME_LEN (EPD_W * EPD_H / 4)  // 96000

#define GREEN_BTN_GPIO 3    // orientation flip (dashboard) / reset-screen flip (AP)
#define WHITE_BTN_R_GPIO 4  // right white — the only ext1 wake-capable white button
#define WHITE_BTN_L_GPIO 5  // left white
#define RESET_HOLD_MS 5000

#define ORIENT_FILE "/frames.bin"
#define ORIENT_TMP "/frames.tmp"
#define ORIENT_LANDSCAPE 0
#define ORIENT_PORTRAIT 1

#define DNS_PORT 53
#define HTTP_PORT 80
#define JOIN_TIMEOUT_MS 15000
#define IB_SLEEP_SECONDS 28800  // 8h production default; server X-Refresh-Interval overrides

static const char* NVS_NAMESPACE = "infobento";
static const char* DEFAULT_SERVER = "https://www.infobento.com";

// ----- persisted across deep sleep (RTC slow memory) -----
RTC_DATA_ATTR char g_lastModified[48] = {0};
RTC_DATA_ATTR uint32_t g_bootCount = 0;
RTC_DATA_ATTR uint32_t g_sleepSeconds = 0;
RTC_DATA_ATTR uint8_t g_orientation = ORIENT_LANDSCAPE;

// ----- runtime config (loaded from NVS in setup) -----
Preferences g_prefs;
String g_ssid, g_pass, g_server, g_deviceid;
bool g_provisioned = false;

DNSServer dns;
WebServer server(HTTP_PORT);
const IPAddress AP_IP(192, 168, 4, 1);
const IPAddress AP_MASK(255, 255, 255, 0);
static bool g_apMode = false;
static bool g_comboDown = false;
static unsigned long g_comboStart = 0;
static bool g_greenDown = false;

SPIClass hspi(HSPI);
SPISettings spiSet(2000000, MSBFIRST, SPI_MODE0);
static uint8_t* g_fb = nullptr;

// ----- vendored UC8179 grayscale driver (identical to firmware/orientation) -----
static const uint8_t LUT_VCOM_GRAY[] = {
  0x00,0x00,0x06,0x08,0x07,0x01, 0x00,0x06,0x0A,0x0B,0x0A,0x01,
  0x00,0x03,0x03,0x00,0x00,0x03, 0x00,0x05,0x09,0x06,0x06,0x01,
  0x00,0x02,0x02,0x0A,0x0A,0x01, 0x00,0x0A,0x11,0x06,0x07,0x01,
  0x00,0x02,0x01,0x02,0x01,0x01 };
static const uint8_t LUT_WW_GRAY[] = {
  0x15,0x00,0x06,0x08,0x07,0x01, 0x54,0x06,0x0A,0x0B,0x0A,0x01,
  0x90,0x03,0x03,0x00,0x00,0x03, 0x2A,0x05,0x09,0x06,0x06,0x01,
  0xAA,0x02,0x02,0x0A,0x0A,0x01, 0x00,0x0A,0x11,0x06,0x07,0x01,
  0x28,0x02,0x01,0x02,0x01,0x01 };
static const uint8_t LUT_KW_GRAY[] = {
  0x2A,0x00,0x06,0x08,0x07,0x01, 0x59,0x06,0x0A,0x0B,0x0A,0x01,
  0x90,0x03,0x03,0x00,0x00,0x03, 0x5A,0x05,0x09,0x06,0x06,0x01,
  0xA8,0x02,0x02,0x0A,0x0A,0x01, 0x45,0x0A,0x11,0x06,0x07,0x01,
  0xA8,0x02,0x01,0x02,0x01,0x01 };
static const uint8_t LUT_WK_GRAY[] = {
  0x16,0x00,0x06,0x08,0x07,0x01, 0xA0,0x06,0x0A,0x0B,0x0A,0x01,
  0x90,0x03,0x03,0x00,0x00,0x03, 0x99,0x05,0x09,0x06,0x06,0x01,
  0xA0,0x02,0x02,0x0A,0x0A,0x01, 0x40,0x0A,0x11,0x06,0x07,0x01,
  0x20,0x02,0x01,0x02,0x01,0x01 };
static const uint8_t LUT_KK_GRAY[] = {
  0x26,0x00,0x06,0x08,0x07,0x01, 0x6A,0x06,0x0A,0x0B,0x0A,0x01,
  0x90,0x03,0x03,0x00,0x00,0x03, 0x65,0x05,0x09,0x06,0x06,0x01,
  0x50,0x02,0x02,0x0A,0x0A,0x01, 0x10,0x0A,0x11,0x06,0x07,0x01,
  0x10,0x02,0x01,0x02,0x01,0x01 };
static const uint8_t CMD_USER_GRAY[] = { 0x17,0x3F,0x3F,0x07,0x06,0x12 };

void checkBusy(uint16_t timeoutMs = 10000) {
  delay(10);
  unsigned long t0 = millis();
  while (!digitalRead(EPD_BUSY_PIN)) {
    if (millis() - t0 > timeoutMs) { Serial.println("[IB] WARN: BUSY timeout"); break; }
    delay(10);
  }
}
void writeCommand(uint8_t c) {
  hspi.beginTransaction(spiSet);
  digitalWrite(EPD_DC_PIN, LOW); digitalWrite(EPD_CS_PIN, LOW);
  hspi.transfer(c);
  digitalWrite(EPD_CS_PIN, HIGH); digitalWrite(EPD_DC_PIN, HIGH);
  hspi.endTransaction();
}
void writeData(uint8_t d) {
  hspi.beginTransaction(spiSet);
  digitalWrite(EPD_CS_PIN, LOW); hspi.transfer(d); digitalWrite(EPD_CS_PIN, HIGH);
  hspi.endTransaction();
}
void writeLUT(uint8_t c, const uint8_t* l, uint16_t n) { writeCommand(c); for (uint16_t i=0;i<n;i++) writeData(l[i]); }
void initGrayMode() {
  digitalWrite(EPD_RES_PIN, LOW); delay(10); digitalWrite(EPD_RES_PIN, HIGH); delay(10); checkBusy();
  writeCommand(0x01); writeData(0x07);
  writeData(CMD_USER_GRAY[0]); writeData(CMD_USER_GRAY[1]); writeData(CMD_USER_GRAY[2]); writeData(CMD_USER_GRAY[3]);
  writeCommand(0x30); writeData(CMD_USER_GRAY[4]);
  writeCommand(0x82); writeData(CMD_USER_GRAY[5]);
  writeCommand(0x06); writeData(0x27); writeData(0x27); writeData(0x28); writeData(0x17);
  writeCommand(0x04); delay(100); checkBusy();
  writeCommand(0x00); writeData(0x3F);
  writeCommand(0xE3); writeData(0x88);
  writeCommand(0x50); writeData(0x10); writeData(0x07);
  writeCommand(0x52); writeData(0x00);
  writeCommand(0x61); writeData(EPD_W>>8); writeData(EPD_W&0xFF); writeData(EPD_H>>8); writeData(EPD_H&0xFF);
  writeLUT(0x20, LUT_VCOM_GRAY, sizeof(LUT_VCOM_GRAY)); checkBusy();
  writeLUT(0x21, LUT_WW_GRAY, sizeof(LUT_WW_GRAY)); checkBusy();
  writeLUT(0x22, LUT_KW_GRAY, sizeof(LUT_KW_GRAY)); checkBusy();
  writeLUT(0x23, LUT_WK_GRAY, sizeof(LUT_WK_GRAY));
  writeLUT(0x24, LUT_KK_GRAY, sizeof(LUT_KK_GRAY));
}
void uploadFrame(const uint8_t* fb) {
  const uint32_t bpr = EPD_W / 4;
  for (uint8_t plane = 0; plane < 2; plane++) {
    writeCommand(plane == 0 ? 0x10 : 0x13);
    hspi.beginTransaction(spiSet); digitalWrite(EPD_CS_PIN, LOW);
    for (uint16_t row = 0; row < EPD_H; row++) {
      const uint8_t* rp = fb + uint32_t(row) * bpr;
      for (uint16_t c8 = 0; c8 < EPD_W/8; c8++) {
        uint8_t out = 0;
        for (uint8_t b = 0; b < 8; b++) {
          uint16_t px = c8*8 + b;
          uint8_t sh = (3 - (px & 3)) * 2;
          uint8_t gray = 3 - ((rp[px/4] >> sh) & 0x03);
          uint8_t want = (plane == 0) ? (gray & 0x01) : (gray & 0x02);
          if (want) out |= (0x80 >> b);
        }
        hspi.transfer(out);
      }
    }
    digitalWrite(EPD_CS_PIN, HIGH); hspi.endTransaction();
  }
}
void refreshDisplay() { writeCommand(0x12); delay(100); checkBusy(); }
void sleepDisplay() { writeCommand(0x02); checkBusy(); writeCommand(0x07); writeData(0xA5); }

// Draw whatever is in g_fb (native -> panel canvas via per-byte NOT).
void drawFrame() {
  for (uint32_t i = 0; i < IB_FRAME_LEN; i++) g_fb[i] = ~g_fb[i];
  unsigned long t0 = millis();
  initGrayMode(); uploadFrame(g_fb); refreshDisplay(); sleepDisplay();
  Serial.printf("[IB] drew frame in %lu ms\n", millis() - t0);
}

void epdBegin() {
  pinMode(EPD_CS_PIN, OUTPUT);  digitalWrite(EPD_CS_PIN, HIGH);
  pinMode(EPD_DC_PIN, OUTPUT);  digitalWrite(EPD_DC_PIN, HIGH);
  pinMode(EPD_RES_PIN, OUTPUT); digitalWrite(EPD_RES_PIN, HIGH);
  pinMode(EPD_BUSY_PIN, INPUT);
  hspi.begin(EPD_SCK_PIN, -1, EPD_MOSI_PIN, -1);
}

// Draw one baked reset/setup screen from PROGMEM (into g_fb, then drawFrame).
void drawResetScreen(uint8_t orientation) {
  const uint8_t* src = (orientation == ORIENT_PORTRAIT) ? RESET_SCREEN_PORTRAIT : RESET_SCREEN_LANDSCAPE;
  memcpy_P(g_fb, src, IB_FRAME_LEN);
  drawFrame();
  Serial.printf("[IB] drew reset screen (%s)\n", orientation == ORIENT_PORTRAIT ? "portrait" : "landscape");
}

// ----- LittleFS cached frame pair (from firmware/orientation) ---------------
bool mountFS() {
  if (LittleFS.begin(true)) return true;
  Serial.println("[IB] LittleFS mount FAILED");
  return false;
}
bool readFrameFromFlash(uint8_t orientation) {
  File f = LittleFS.open(ORIENT_FILE, "r");
  if (!f) { Serial.println("[IB] no cached frames yet"); return false; }
  if (f.size() < (size_t)IB_FRAME_LEN * 2) { f.close(); return false; }
  f.seek((size_t)orientation * IB_FRAME_LEN);
  size_t got = f.read(g_fb, IB_FRAME_LEN);
  f.close();
  return got == IB_FRAME_LEN;
}
bool drawOrientationFromFlash(uint8_t orientation) {
  if (!readFrameFromFlash(orientation)) return false;
  drawFrame();
  return true;
}

// ----- NVS config -----------------------------------------------------------
void loadConfig() {
  g_prefs.begin(NVS_NAMESPACE, true);
  g_provisioned = g_prefs.getBool("provisioned", false);
  g_ssid = g_prefs.getString("ssid", "");
  g_pass = g_prefs.getString("pass", "");
  g_server = g_prefs.getString("server", "");
  g_deviceid = g_prefs.getString("deviceid", "");
  uint8_t nvsOrient = g_prefs.getUChar("orient", ORIENT_LANDSCAPE);
  g_prefs.end();
  if (g_server.length() == 0) g_server = DEFAULT_SERVER;
  // Cold boot clears RTC — restore orientation from NVS so a battery pull doesn't
  // silently revert to landscape.
  esp_sleep_wakeup_cause_t cause = esp_sleep_get_wakeup_cause();
  if (cause != ESP_SLEEP_WAKEUP_EXT1 && cause != ESP_SLEEP_WAKEUP_TIMER) g_orientation = nvsOrient;
}
void persistOrientation(uint8_t orientation) {
  g_orientation = orientation;
  g_prefs.begin(NVS_NAMESPACE, false);
  g_prefs.putUChar("orient", orientation);
  g_prefs.end();
}
void saveConfig(const String& ssid, const String& pass, const String& serverUrl, const String& deviceid) {
  g_prefs.begin(NVS_NAMESPACE, false);
  g_prefs.putString("ssid", ssid);
  g_prefs.putString("pass", pass);
  g_prefs.putString("server", serverUrl);
  g_prefs.putString("deviceid", deviceid);
  g_prefs.putBool("provisioned", true);
  g_prefs.end();
}
void clearConfig() {
  g_prefs.begin(NVS_NAMESPACE, false);
  g_prefs.clear();  // wipe the whole namespace so the device boots pristine
  g_prefs.end();
  LittleFS.remove(ORIENT_FILE);  // the cached frames belonged to the old device
}
bool haveConfig() { return g_provisioned && g_deviceid.length() && g_ssid.length(); }

// ----- Wi-Fi + /frames pull (from orientation, NVS-driven) ------------------
bool ensureWifi() {
  if (WiFi.status() == WL_CONNECTED) return true;
  Serial.printf("[IB] Wi-Fi connecting to '%s' ...\n", g_ssid.c_str());
  WiFi.mode(WIFI_STA);
  WiFi.disconnect(true);
  delay(100);
  WiFi.begin(g_ssid.c_str(), g_pass.c_str());
  for (int i = 0; i < 40 && WiFi.status() != WL_CONNECTED; i++) { delay(500); Serial.print('.'); }
  Serial.println();
  if (WiFi.status() == WL_CONNECTED) { Serial.print("[IB] Wi-Fi OK, IP "); Serial.println(WiFi.localIP()); return true; }
  Serial.println("[IB] Wi-Fi FAILED");
  return false;
}
bool readExact(WiFiClient* s, uint8_t* buf, int len) {
  int got = 0;
  unsigned long idle = millis();
  const unsigned long start = millis();
  while (got < len && millis() - idle < 15000 && millis() - start < 60000) {
    int avail = s->available();
    if (avail > 0) { int n = (int)s->readBytes(buf + got, (size_t)min(avail, len - got)); got += n; idle = millis(); }
    else delay(1);
  }
  return got == len;
}
void adoptRefreshInterval(HTTPClient& http) {
  String ri = http.header("X-Refresh-Interval");
  if (!ri.length()) return;
  long secs = ri.toInt();
  if (secs <= 0) return;
  if (secs < 15) secs = 15;
  if (secs > 86400) secs = 86400;
  g_sleepSeconds = (uint32_t)secs;
  Serial.printf("[IB] refresh interval -> %lu s\n", (unsigned long)secs);
}
bool streamHalfToFile(WiFiClient* s, File& f) {
  if (!readExact(s, g_fb, IB_FRAME_LEN)) return false;
  return f.write(g_fb, IB_FRAME_LEN) == (size_t)IB_FRAME_LEN;
}
void pullFrames() {
  if (!ensureWifi()) return;
  bool tls = g_server.startsWith("https");
  String url = g_server + "/api/device/" + g_deviceid + "/frames";
  WiFiClientSecure secureClient;
  WiFiClient plainClient;
  WiFiClient* client;
  if (tls) { secureClient.setInsecure(); client = &secureClient; }  // pin ISRG Root X1 to harden (#145)
  else client = &plainClient;

  HTTPClient http;
  http.begin(*client, url);
  const char* collect[] = { "Last-Modified", "X-Refresh-Interval", "X-Frame-Landscape-Bytes", "X-Frame-Portrait-Bytes" };
  http.collectHeaders(collect, 4);
  if (g_lastModified[0]) http.addHeader("If-Modified-Since", g_lastModified);
  int code = http.GET();
  Serial.printf("[IB] GET /frames -> %d\n", code);
  adoptRefreshInterval(http);

  if (code == 304) { Serial.println("[IB] 304 -> keep cached frames"); http.end(); return; }
  if (code != 200) { Serial.printf("[IB] status %d -> keep last frame\n", code); http.end(); return; }

  long landBytes = http.header("X-Frame-Landscape-Bytes").toInt();
  long portBytes = http.header("X-Frame-Portrait-Bytes").toInt();
  if (landBytes != (long)IB_FRAME_LEN || portBytes != (long)IB_FRAME_LEN) {
    Serial.printf("[IB] WARN bad frame sizes L=%ld P=%ld (want %d) -> skip\n", landBytes, portBytes, (int)IB_FRAME_LEN);
    http.end(); return;
  }
  WiFiClient* stream = http.getStreamPtr();
  if (stream == nullptr) { Serial.println("[IB] ERROR: null stream"); http.end(); return; }

  bool ok = false;
  {
    File f = LittleFS.open(ORIENT_TMP, "w");
    if (!f) Serial.println("[IB] ERROR: open tmp");
    else { ok = streamHalfToFile(stream, f) && streamHalfToFile(stream, f); f.close(); }
  }
  http.end();
  if (!ok) { Serial.println("[IB] ERROR: short read -> keep prior cache"); LittleFS.remove(ORIENT_TMP); return; }
  LittleFS.remove(ORIENT_FILE);
  if (!LittleFS.rename(ORIENT_TMP, ORIENT_FILE)) { Serial.println("[IB] ERROR: rename failed"); LittleFS.remove(ORIENT_TMP); return; }

  String lm = http.header("Last-Modified");
  if (lm.length()) { strncpy(g_lastModified, lm.c_str(), sizeof(g_lastModified) - 1); g_lastModified[sizeof(g_lastModified) - 1] = '\0'; }
  Serial.printf("[IB] stored both frames, Last-Modified: %s\n", g_lastModified);
  if (!drawOrientationFromFlash(g_orientation)) Serial.println("[IB] WARN: draw-after-store failed");
}

// ----- Captive portal (streamlined from firmware/provisioning) --------------
String apSsid() {
  uint8_t mac[6];
  WiFi.macAddress(mac);
  char ssid[16];
  snprintf(ssid, sizeof(ssid), "InfoBento-%02X%02X", mac[4], mac[5]);
  return String(ssid);
}
String htmlEscape(const String& s) {
  String o;
  for (size_t i = 0; i < s.length(); i++) {
    char c = s[i];
    if (c == '&') o += "&amp;"; else if (c == '<') o += "&lt;"; else if (c == '>') o += "&gt;";
    else if (c == '"') o += "&quot;"; else o += c;
  }
  return o;
}
String setupPage(const String& err) {
  String h = "<!doctype html><html><head><meta charset='utf-8'>"
             "<meta name='viewport' content='width=device-width,initial-scale=1'>"
             "<title>Set up InfoBento</title><style>"
             "body{background:#fff;color:#000;font-family:ui-monospace,Menlo,Consolas,monospace;max-width:24rem;margin:2rem auto;padding:0 1rem}"
             "h1{font-size:1.2rem;border-bottom:1px solid #000;padding-bottom:.5rem}"
             "label{display:block;margin:1rem 0 .25rem;font-size:.85rem}"
             "input{width:100%;padding:.6rem;font:inherit;background:#fff;border:1px solid #000;box-sizing:border-box}"
             "button{width:100%;margin-top:1.5rem;padding:.6rem;font:inherit;cursor:pointer;font-weight:bold;border:1px solid #000;background:#fff}"
             "button:hover{background:#000;color:#fff}.err{color:#a00;margin-top:1rem}</style></head><body>"
             "<h1>Set up InfoBento</h1>";
  if (err.length()) h += "<div class='err'>" + htmlEscape(err) + "</div>";
  h += "<form method='POST' action='/save'>"
       "<label>Wi-Fi network</label><input name='ssid' placeholder='Your Wi-Fi name'>"
       "<label>Wi-Fi password</label><input name='pass' type='password' placeholder='(blank if open)'>"
       "<label>Device ID (from the sticker / pairing page)</label><input name='deviceid' placeholder='xxxxxxxx-...'>"
       "<label>Server (optional)</label><input name='server' placeholder='https://www.infobento.com'>"
       "<button type='submit'>Connect</button></form></body></html>";
  return h;
}
void redirectToPortal() {
  server.sendHeader("Location", String("http://") + AP_IP.toString() + "/");
  server.send(302, "text/plain", "");
}
void handleRoot() { server.send(200, "text/html", setupPage("")); }
bool tryJoin(const String& ssid, const String& pass) {
  Serial.printf("[IB] joining '%s' ...\n", ssid.c_str());
  WiFi.begin(ssid.c_str(), pass.c_str());
  unsigned long start = millis();
  while (WiFi.status() != WL_CONNECTED && millis() - start < JOIN_TIMEOUT_MS) { dns.processNextRequest(); delay(50); }
  if (WiFi.status() == WL_CONNECTED) { Serial.print("[IB] joined, IP "); Serial.println(WiFi.localIP()); return true; }
  Serial.println("[IB] join FAILED");
  WiFi.disconnect(false);
  return false;
}
void handleSave() {
  String ssid = server.arg("ssid"); ssid.trim();
  String pass = server.arg("pass");
  String deviceid = server.arg("deviceid"); deviceid.trim();
  String serverUrl = server.arg("server"); serverUrl.trim();
  if (!ssid.length()) { server.send(200, "text/html", setupPage("Enter your Wi-Fi network name.")); return; }
  if (ssid.length() > 32) { server.send(200, "text/html", setupPage("Network name is too long (max 32).")); return; }
  if (pass.length() && (pass.length() < 8 || pass.length() > 63)) { server.send(200, "text/html", setupPage("Password must be 8-63 characters.")); return; }
  if (!deviceid.length()) { server.send(200, "text/html", setupPage("Enter the Device ID from the sticker.")); return; }
  if (serverUrl.length() && !serverUrl.startsWith("http://") && !serverUrl.startsWith("https://")) {
    server.send(200, "text/html", setupPage("Server URL must start with http:// or https://.")); return;
  }
  if (tryJoin(ssid, pass)) {
    saveConfig(ssid, pass, serverUrl, deviceid);
    Serial.println("[IB] provisioned -> config saved, rebooting into dashboard");
    server.send(200, "text/html", "<!doctype html><meta charset=utf-8><h1>Connected</h1><p>Your InfoBento is setting up its display now.</p>");
    delay(1500);
    ESP.restart();
  } else {
    server.send(200, "text/html", setupPage("Could not join that network. Check the password and try again."));
  }
}
void startAP() {
  String ssid = apSsid();
  Serial.printf("[IB] no config -> AP mode, SSID '%s' (open)\n", ssid.c_str());
  WiFi.mode(WIFI_AP_STA);
  WiFi.softAPConfig(AP_IP, AP_IP, AP_MASK);
  WiFi.softAP(ssid.c_str());
  delay(100);
  dns.start(DNS_PORT, "*", AP_IP);
  server.on("/", HTTP_GET, handleRoot);
  server.on("/save", HTTP_POST, handleSave);
  server.on("/hotspot-detect.html", HTTP_GET, redirectToPortal);
  server.on("/generate_204", HTTP_GET, redirectToPortal);
  server.on("/gen_204", HTTP_GET, redirectToPortal);
  server.on("/ncsi.txt", HTTP_GET, redirectToPortal);
  server.on("/connecttest.txt", HTTP_GET, redirectToPortal);
  server.onNotFound(redirectToPortal);
  server.begin();
  g_apMode = true;
  Serial.println("[IB] captive portal up");
}

// ----- Reset + orientation flip ---------------------------------------------
void factoryReset() {
  Serial.println("[IB] WHITE x2 5s -> factory reset (draw screen, wipe config)");
  drawResetScreen(g_orientation);
  clearConfig();
  delay(200);
  ESP.restart();
}
// Both white buttons held 5s (awake AP-mode polling path).
void checkResetCombo() {
  bool both = (digitalRead(WHITE_BTN_R_GPIO) == LOW) && (digitalRead(WHITE_BTN_L_GPIO) == LOW);
  if (both) {
    if (!g_comboDown) { g_comboDown = true; g_comboStart = millis(); Serial.println("[IB] both white down — hold 5s to reset"); }
    else if (millis() - g_comboStart >= RESET_HOLD_MS) factoryReset();
  } else {
    if (g_comboDown) Serial.println("[IB] white combo released");
    g_comboDown = false;
  }
}
// Green flips the reset screen (AP-mode polling path).
void checkGreenButton() {
  bool pressed = (digitalRead(GREEN_BTN_GPIO) == LOW);
  if (pressed && !g_greenDown) {
    delay(20);
    if (digitalRead(GREEN_BTN_GPIO) == LOW) {
      g_orientation = (g_orientation == ORIENT_LANDSCAPE) ? ORIENT_PORTRAIT : ORIENT_LANDSCAPE;
      drawResetScreen(g_orientation);
    }
  }
  g_greenDown = pressed;
}
// Flip the cached DASHBOARD orientation (deep-sleep green-wake path).
void handleOrientationFlip() {
  uint8_t next = (g_orientation == ORIENT_LANDSCAPE) ? ORIENT_PORTRAIT : ORIENT_LANDSCAPE;
  Serial.printf("[IB] green -> flip to %s\n", next == ORIENT_PORTRAIT ? "portrait" : "landscape");
  if (drawOrientationFromFlash(next)) persistOrientation(next);
  else Serial.println("[IB] no cached frame to flip to -> no-op");
}
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
void loop() {
  // Reached only in AP/provisioning mode; the configured path ends in deep sleep.
  if (g_apMode) {
    dns.processNextRequest();
    server.handleClient();
  }
  checkResetCombo();
  checkGreenButton();
  delay(5);
}

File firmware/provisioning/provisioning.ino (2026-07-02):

// InfoBento firmware — Phase 6: captive-portal provisioning (reTerminal E1001).
//
// First-boot Wi-Fi onboarding. On power-on with no saved credentials the device
// comes up as its own open access point, runs a captive portal, and lets the
// user pick their home Wi-Fi and type the password from any phone or laptop —
// no app, no hardcoded secrets. Once it joins the home network the creds are
// persisted to NVS and subsequent boots run the normal pull/deep-sleep firmware
// (Phases 3-5). Holding BOTH white buttons for 5s factory-resets back to AP mode
// and shows a resident reset screen on the panel (issue #171).
//
// This is the gate to a shippable out-of-box flow (see docs/hardware/
// CONNECTIVITY.md "First-time setup flow"). Unlike the earlier phases there is
// NO secrets.h: the whole point is that the device has no credentials to begin
// with, so this sketch compiles and runs with nothing pre-baked.
//
// State machine (setup):
//   no creds in NVS                 -> AP mode + captive portal (provisioning)
//   creds in NVS, join succeeds     -> "provisioned"; hand off to the pull loop
//   creds in NVS, join fails        -> fall back to AP mode so a moved/renamed
//                                      network (or a wrong saved password) can be
//                                      re-provisioned without a factory reset
//
// Captive portal (AP mode), served from the on-board web server at 192.168.4.1:
//   GET  /            setup page: server-side Wi-Fi scan -> <select>, + manual
//                     SSID field (hidden networks), password, optional custom
//                     server URL (self-host hatch, #80). Pure HTML, no JS.
//   POST /save        persist creds, join the home Wi-Fi (AP+STA), report result
//   OS probe URLs     Apple hotspot-detect.html / Android generate_204 /
//                     Microsoft ncsi.txt + any unknown path -> 302 to / so the
//                     OS auto-opens the captive-portal browser
//
// Bench-checkable, but AP mode + the portal + a phone can't be CI-verified —
// this sketch is COMPILE-CLEAN; the operator bench-check lives in
// firmware/README.md (Phase 6).
//
// UC8179 panel driver is intentionally NOT vendored here: provisioning never
// touches the panel (the eInk holds its last image at zero power), so this
// sketch stays focused on the radio + NVS + HTTP. Panel + provisioning compose
// in the integrated production firmware (Phase 7).
//
// Board:  esp32:esp32:esp32s3
// Build:  arduino-cli compile --fqbn esp32:esp32:esp32s3 firmware/provisioning
// Upload: arduino-cli upload -p /dev/cu.usbserial-XXXX \
//           --fqbn 'esp32:esp32:esp32s3:UploadSpeed=115200' firmware/provisioning

#include <WiFi.h>
#include <WebServer.h>
#include <DNSServer.h>
#include <Preferences.h>
#include <esp_system.h>
#include <SPI.h>
#include "reset_screen.h"  // baked landscape+portrait reset frames (issue #171)

// ----- Buttons (E1001; Phase 7 ESP32-C3 re-pins) ---------------------------
// Factory reset moved off the recessed GPIO2 pinhole onto the two front WHITE
// buttons: hold BOTH for 5s. No case-opening, no bridging the J2 header — it
// uses affordances the user can see. Verified against Seeed's reTerminal E1001
// wiki: green=GPIO3, white-right=GPIO4 (the only ext1 wake-capable white button),
// white-left=GPIO5; all active-LOW on INPUT_PULLUP. The GREEN button (GPIO3,
// shared with the orientation flip, #160) toggles the reset screen between
// landscape and portrait. Panel SPI uses 7/9/10/11/12/13, so 3/4/5 are clear.
// TODO(#57 Phase 7): re-pin for the production ESP32-C3.
#define GREEN_BTN_GPIO 3
#define WHITE_BTN_R_GPIO 4
#define WHITE_BTN_L_GPIO 5
#define RESET_HOLD_MS 5000  // both white buttons held this long => factory reset

// ----- UC8179 grayscale panel (vendored from firmware/orientation) ----------
// Provisioning normally never touches the panel, but the factory-reset screen
// must be shown with no network (before any SSID exists), so this sketch gains
// the driver + the two baked frames (reset_screen.h). Identical draw path to the
// deep-sleep / orientation sketches: native bytes are per-byte NOT-flipped to the
// panel canvas (0=white..3=black -> 0=black..3=white), then uploaded.
#define EPD_SCK_PIN 7
#define EPD_MOSI_PIN 9
#define EPD_CS_PIN 10
#define EPD_DC_PIN 11
#define EPD_RES_PIN 12
#define EPD_BUSY_PIN 13
#define EPD_W 800
#define EPD_H 480
#define IB_FRAME_LEN (EPD_W * EPD_H / 4)  // 96000
#define RESET_LANDSCAPE 0
#define RESET_PORTRAIT 1

static SPIClass hspi(HSPI);
static SPISettings spiSet(2000000, MSBFIRST, SPI_MODE0);

static const uint8_t LUT_VCOM_GRAY[] = {
  0x00,0x00,0x06,0x08,0x07,0x01, 0x00,0x06,0x0A,0x0B,0x0A,0x01,
  0x00,0x03,0x03,0x00,0x00,0x03, 0x00,0x05,0x09,0x06,0x06,0x01,
  0x00,0x02,0x02,0x0A,0x0A,0x01, 0x00,0x0A,0x11,0x06,0x07,0x01,
  0x00,0x02,0x01,0x02,0x01,0x01 };
static const uint8_t LUT_WW_GRAY[] = {
  0x15,0x00,0x06,0x08,0x07,0x01, 0x54,0x06,0x0A,0x0B,0x0A,0x01,
  0x90,0x03,0x03,0x00,0x00,0x03, 0x2A,0x05,0x09,0x06,0x06,0x01,
  0xAA,0x02,0x02,0x0A,0x0A,0x01, 0x00,0x0A,0x11,0x06,0x07,0x01,
  0x28,0x02,0x01,0x02,0x01,0x01 };
static const uint8_t LUT_KW_GRAY[] = {
  0x2A,0x00,0x06,0x08,0x07,0x01, 0x59,0x06,0x0A,0x0B,0x0A,0x01,
  0x90,0x03,0x03,0x00,0x00,0x03, 0x5A,0x05,0x09,0x06,0x06,0x01,
  0xA8,0x02,0x02,0x0A,0x0A,0x01, 0x45,0x0A,0x11,0x06,0x07,0x01,
  0xA8,0x02,0x01,0x02,0x01,0x01 };
static const uint8_t LUT_WK_GRAY[] = {
  0x16,0x00,0x06,0x08,0x07,0x01, 0xA0,0x06,0x0A,0x0B,0x0A,0x01,
  0x90,0x03,0x03,0x00,0x00,0x03, 0x99,0x05,0x09,0x06,0x06,0x01,
  0xA0,0x02,0x02,0x0A,0x0A,0x01, 0x40,0x0A,0x11,0x06,0x07,0x01,
  0x20,0x02,0x01,0x02,0x01,0x01 };
static const uint8_t LUT_KK_GRAY[] = {
  0x26,0x00,0x06,0x08,0x07,0x01, 0x6A,0x06,0x0A,0x0B,0x0A,0x01,
  0x90,0x03,0x03,0x00,0x00,0x03, 0x65,0x05,0x09,0x06,0x06,0x01,
  0x50,0x02,0x02,0x0A,0x0A,0x01, 0x10,0x0A,0x11,0x06,0x07,0x01,
  0x10,0x02,0x01,0x02,0x01,0x01 };
static const uint8_t CMD_USER_GRAY[] = { 0x17,0x3F,0x3F,0x07,0x06,0x12 };

static void epdCheckBusy(uint16_t timeoutMs = 10000) {
  delay(10);
  unsigned long t0 = millis();
  while (!digitalRead(EPD_BUSY_PIN)) {
    if (millis() - t0 > timeoutMs) { Serial.println("[IB] WARN: BUSY timeout"); break; }
    delay(10);
  }
}
static void epdCmd(uint8_t c) {
  hspi.beginTransaction(spiSet);
  digitalWrite(EPD_DC_PIN, LOW); digitalWrite(EPD_CS_PIN, LOW);
  hspi.transfer(c);
  digitalWrite(EPD_CS_PIN, HIGH); digitalWrite(EPD_DC_PIN, HIGH);
  hspi.endTransaction();
}
static void epdData(uint8_t d) {
  hspi.beginTransaction(spiSet);
  digitalWrite(EPD_CS_PIN, LOW); hspi.transfer(d); digitalWrite(EPD_CS_PIN, HIGH);
  hspi.endTransaction();
}
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

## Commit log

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2026-04-14 feat(api): add PNG preview endpoint (#19)
    * feat(api): add PNG preview endpoint (#18)
    POST /api/preview returns a scaled PNG image of the rendered bento layout.
    Uses pngjs (pure JS) to convert 1-bit frame buffer to grayscale PNG with
    configurable scale factor (default 3x). 33 tests passing.
    Closes #18
    * docs: add sample preview.png showing 3-box text rendering
    3x scale PNG of a 3-box layout (two text boxes + weather placeholder).
    For visual verification of the rendering pipeline.
    * fix: address PR #19 review — RGBA stride, scale validation, circul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
2026-04-21 feat(preview): switch hero font to Spleen 8x16 across all previews
    Replace 2x-scaled 5x7 baseline with purpose-designed Spleen 8x16
    bitmap font. Cleaner curves on numerals, better weight balance,
    same vertical footprint as the old 10x14.
    Also adds font comparison script and individual variant PNGs.
    Vanilla JS selected for web framework (over Preact).
2026-04-21 docs: bump price target to $35, accept glass panel and ~8mm thickness
    BOM analysis showed $25 was not feasible with charging subsystem
    ($13-18), hinge ($4-30), and glass eInk display ($5-8). Glass panel
    kept over flex (saves $7-10/unit). ~8mm folded thickness positioned
    as "slim enough for a back pocket" (thinner than MagSafe Battery Pack).
2026-04-21 docs(ux): sync project model with all decisions through round 7
    Fix 12 stale artifacts:
    - Description, price refs ($25->$35), REQ-001/002/003
    - 1-Bit Elegance principle: whitespace > borders
    - Embedded Font -> Two-Font Bitmap System (Spleen 8x16 + 5x7)
    - eInk wireframe: hero/data hierarchy, horizontal subdivision
    - Web editor wireframe: vanilla JS, client-side render, up/down arrows
    - Hardware Platform note: full component layout from issue #22
    - Text Box prototype: remove stale "no PNG" limitation
    - Design research finding: status addressed
    - Open questions: separate resolved from still-open
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2026-04-21 feat(web): vanilla JS config editor with reactive state
    Replace React stub with vanilla JS editor (svelte-editor.html pattern):
    - Reactive state with clear-and-rebuild on mutation
    - Box list with up/down reorder, add/remove, inline-editable labels
    - Type-specific config forms for all 5 box types
    - CSS mock eInk preview (client-side renderer integration next)
    - Export JSON button
    - 2.4KB gzipped JS, no framework dependencies
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2026-04-21 feat(web): wire client-side renderer for live eInk preview
    Replace CSS mock preview with real 1-bit canvas rendering:
    - Import @infobento/renderer as workspace dependency
    - Convert EditorBox state to BentoConfig discriminated unions
    - Paint FrameBuffer to canvas at 3x scale (384x888)
    - MSB-first bit unpacking matches renderer format
    - Stub pngjs in Vite config (Node-only, not needed in browser)
    - Preview updates live on every config change
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2026-04-22 chore(hardware): add OpenSCAD mockup for 3D printing
    Dual-display clamshell mockup with:
    - Display half: D and P panel recesses, ESP32 + battery cavities
    - Solar half: solar panel recess, MagSafe ring recess
    - Hinge barrels with pin holes along short edge
    - Weight insert holes for mass simulation
    - Print layout (side by side) and closed view modes
    Dimensions: 70.6x140mm, 3.2mm display half, 3.25mm solar half.
    Ready for PCBWay FDM printing.
    [mockup.scad]
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2026-04-22 fix(hardware): move battery to solar half to avoid grip flex risk
    LiPo between two glass eInk panels in the hand-squeeze zone risks
    mechanical fatigue degradation from daily phone gripping. Battery
    moved to solar half where it is never squeezed.
    - Display half: 3.2mm (panels + ESP32 only, no battery)
    - Solar half: ~4.0mm (adds 2.5mm GM251534 battery)
    - Folded: ~7.2mm (up from 6.5mm, still thinner than 8mm single-display)
    - Power through hinge FPC: 2 wires, ~100mA, proven safe
    [infobento.scad]
2026-04-22 docs: fix stale thickness (6.5mm->7.2mm) and battery placement refs
    Battery is on solar half, not display half. Thickness is 7.2mm
    folded (3.2mm display + 4.0mm solar), not 6.5mm.
2026-04-22 feat(core): add displayId ('D' | 'P') to BentoConfig for dual-display
    Each BentoConfig now targets a specific physical display:
    - D = outer display (phone-mounted, real-time content)
    - P = inner display (counter/peek, ambient content)
    All tests and web preview updated with displayId: 'D'.
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2026-04-22 feat(web): localStorage persistence and JSON import
    Config auto-saves to localStorage on every change and restores
    on page load. Import button reads JSON files in the same format
    as export: { version, D: BentoConfig, P: BentoConfig }.
2026-04-22 docs(ux): full project model sync for v0.4.0
    Fix 7 stale artifacts:
    - First-time config scenario: 240x200 -> 128x296, add D/P toggle
    - Rendering pipeline: update scope to all 5 box types + dual display
    - Resolution finding: status open -> fixed
    - Web editor prototype: mark as superseded by packages/web/
    - Round 8 P-side label: PCB -> inner eInk display
    - Kickstarter pitch: single -> dual display
    - Round 5: remove collapsed mode (eliminated with 180° hinge)
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2026-04-22 fix(api): health endpoint reads version from package.json at startup
    Replaces hardcoded '0.2.0' with dynamic read from ../package.json.
    Version automatically stays current after releases.
2026-04-22 feat: complete phase 2-4 remaining items (#24)
    Phase 2 (core):
    - Zod validation with field-level error paths (validateBentoConfig)
    - Horizontal split layout (split: 'left' | 'right' on BentoBox)
    - 10 new tests (7 validation + 3 split layout)
    Phase 4 (api):
    - Structured error responses via Zod (replaces hand-written validation)
    - Box-types endpoint trimmed to 5 implemented types only
    - All endpoints use Zod validation (covers displayId)
    - Re-export frameToPng from api package
    - Health endpoint already reads from package.json (done earlier)
    Phase 3 (renderer): renderer stays pure — API fetch deferred to web/api
    Phase 5 (web): complete — polish moved to Kickstarter issue #23
    73 tests acr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
2026-04-23 feat(web): dual-display editor, consent dialog, Nominatim geocoding, 3hr forecast
    Editor layout
    - Replaced D/P toggle with always-visible 2x2 grid: Outer/Inner previews
    on top, corresponding editors below. Preview clipping bug (top ~22%
    of layout was being cut off by hard-coded #eink-display dimensions)
    fixed by sizing the panel from the canvas via CSS variables.
    - Header: title 'InfoBento' + 'EDITOR vX.Y.Z' badge, single Menu
    dropdown (Import / Export JSON) with fade+slide transition.
    - Mobile (<=720px) stacks all four panels vertically.
    - Consent dialog: first-load Privacy + Terms modal, persisted in
    localStorage with CONSENT_VERSION for future re-prompting.
    Geocoding
    - Switched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
2026-04-23 docs(pivot): apply Phase 1 strategic artifacts (#26, #27)
    Counter-only color decorator pivot — Phase 1 only (no code changes).
    Closes #26 (.tux/project.json edits) and #27 (README + docs rewrite).
    Full pivot tracked under #25 RFC and the pivot/counter-color milestone.
    .tux/project.json (#26):
    - description rewritten for monolithic counter device, no clamshell
    - Daily Glancer demoted from primary; Desk Decorator + Gift Giver lead
    - Device Owner work-role responsibilities reframed for counter placement
    - 1-Bit Elegance design principle replaced with Limited-Palette Elegance
    - MagSafe Dual-Display Clamshell design principle replaced with
    Solar-Powered Counter Display
    - Scenario 'Phone-back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
2026-04-23 docs(pivot): lock connectivity (Wi-Fi direct, ESP32-C3, no app, DO hosting)
    Connectivity, MCU, recovery affordance, and cloud hosting decisions
    locked 2026-04-22 after the user-class fit + cost analysis discussion.
    Closes the connectivity portion of #35; panel SKU still pending in #35.
    Adds new sub-issue #39 for captive-portal provisioning UX firmware.
    Decisions locked:
    - MCU: ESP32-C3 (Wi-Fi 4 + BLE 5; BLE radio reserved for v2 bridge mode)
    - Connectivity: Wi-Fi direct + PWA-only, no companion phone app for v1
    - Setup: captive-portal flow on first boot
    - Recovery: recessed pinhole reset on back-lower (paperclip + 5s)
    - Cloud hosting: DigitalOcean droplet (co-tenant with tiles/webmap.dev),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
2026-04-23 docs(campaign): commit Kickstarter copy draft + cross-link from project.json
    Adds docs/kickstarter-copy.md as the canonical, page-ready Kickstarter
    draft. Incorporates all locked decisions through the Round 10 counter
    pivot (color eInk, ESP32-C3, Wi-Fi direct, no companion app, captive
    portal + pinhole reset, white monolithic body, 4ft drop survival,
    solar-powered, no subscriptions). Also includes the "Tidbyt vs InfoBento
    — still vs kinetic" positioning preamble for use during campaign-team
    discussions.
    Cross-links:
    - .tux/project.json "Market & Distribution" note now points to
    docs/kickstarter-copy.md as the canonical source. The note keeps
    high-level positioning, competitive landsca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
2026-04-23 docs(tux): update project.json for Phase 2 completion and new box types
    Reflect current state after #29 merge and #41-45 creation:
    - Phase 2 (dual-display collapse) marked done
    - Web editor wireframe: single-column layout, localStorage v2
    - REQ-002: BLE replaced with Wi-Fi direct (round 10 pivot)
    - REQ-003: phone-mounted mode references removed
    - REQ-004: box count updated from 5 to 11
    - Free by Default principle: expanded for all 11 box types
    - Zero Device Interaction principle: updated for Wi-Fi/counter-only
    - Morning glance scenario: rewritten for counter-only device
    - First-time config scenario: single-column editor, no D/P toggle
    - Prototype description: 240x200, no displayId, 11 render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
2026-04-23 docs(tux): add B&W-only, bento form factor, golden ratio, IMU requirements
    Round 11 direction changes:
    - REQ-009: v1 ships B&W only — color deferred to v2 (de-scopes Phase 3)
    - REQ-010: bento-box form factor (~18x12cm) with golden-ratio display (1.618:1)
    - REQ-011: high DPI (>=200 target) and minimal bezel (<=3mm)
    - REQ-012: always-on IMU (LIS2DW12TR or BMA400, <1uA) with hardware
    orientation interrupt for auto-rotate (landscape flat, portrait on end)
    Design principle reverted from "Limited-Palette Elegance" (7-color) back
    to "1-Bit Elegance". Wireframe and Solar-Powered Counter Display principle
    updated for B&W, golden ratio, IMU, and minimal bezel.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
2026-04-23 docs(tux): update REQ-012 to tilt switches, remove IMU references
    Two mechanical tilt switches at 90° replace the discrete IMU (LIS2DW12/
    BMA400). Zero standby current, ~$0.10 BOM, 4-orientation detection on
    two GPIO pins. Updated REQ-012 and Solar-Powered Counter Display principle.
2026-04-23 docs(tux): audit fix — purge stale color/clamshell/phone references
    Fixes 22 inconsistencies found by project.json audit after Round 11:
    Critical (12): top-level description → B&W bento; REQ-003 source →
    B&W power; Hardware Platform note rewritten (B&W panel candidates,
    tilt switches, bento dimensions, ≤3mm bezel, updated BOM); Market &
    Distribution note rewritten (B&W positioning, "Tidbyt glows, InfoBento
    reads"); Campaign Phase Plan updated (Phase 3 de-scoped, issue refs
    #47/#50 replace #34/#35); morning glance scenario → B&W; web editor
    wireframe → 1-bit preview; display finding → #47; Solar-Powered
    Counter Display → tilt switches not IMU.
    Moderate (10): Device Owner/Gif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
2026-04-23 chore: bump version to 0.5.0 and update changelog
    v0.5.0: 5 new box types (date, moon, sun, aqi, progress), dual-display
    collapsed to single-column, Round 11 strategic direction (B&W only,
    bento form factor, golden ratio, tilt switch auto-rotate).
    15 test files, 121 tests passing.
2026-04-23 docs(tux): upgrade REQ-009 to 2-bit grayscale, add anti-aliased fonts
    All candidate eInk panels natively support 4 grayscale levels via
    their driver ICs (UC8179, SSD1677) at zero additional BOM cost.
    Changes:
    - REQ-009: "1-bit framebuffer" → "2-bit framebuffer (4 grayscale
    levels: black, dark gray, light gray, white)"
    - Design principle renamed: "1-Bit Elegance" → "Grayscale Elegance"
    with tone-based hierarchy examples
    - Two-Font Bitmap System: notes anti-aliased rendering capability
    - Wireframe: updated framebuffer and content rendering annotations
    - Removed "Anti-aliased fonts" from counterExamples (now a feature)
    Issue #52 created for renderer implementation.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
2026-04-23 chore: bump version to 0.5.1 and update changelog
    v0.5.1: deploy workflow, Claude review fix, REQ-009 upgraded to 2-bit
    grayscale, tilt switches replace IMU, project.json audit (22 fixes),
    panel sourcing expanded to 21 candidates.
2026-04-24 feat: 2-bit grayscale framebuffer, custom font, 920x680 native resolution
    - Replace BSD-licensed Spleen hero font with original 8x16 bitmap font
    - Upgrade framebuffer from 1-bit to 2-bit (4-level grayscale)
    - New pixel API: setPixel(fb, x, y, level=3), getPixel(fb, x, y)
    - Gray constants: GRAY_WHITE=0, GRAY_LIGHT=1, GRAY_DARK=2, GRAY_BLACK=3
    - All drawing primitives accept optional gray level parameter
    - Box headers rendered in dark gray, icons in light gray, rules in dark gray
    - Display resolution upgraded from 240x200 to 920x680
    - Font rendering at native resolution via 4x-expanded glyph data at load time
    - Body font 20x28px, hero font 32x64px, icons 28x28px
    - Simplified date box (removed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
2026-04-24 docs: update hardware spec to Good Display GDEH0576T81 5.76" 920x680 198DPI
    Lock display spec to actual panel. Update CLAUDE.md hardware context
    and .tux project description with correct panel model, resolution,
    active area, driver IC, and form factor details.
2026-04-24 docs: update all docs from color eInk to B&W GDEH0576T81 spec
    Replace all color eInk / Spectra 6 / ACeP references with the locked
    Good Display GDEH0576T81 5.76" B&W panel (920x680, 198 DPI, SSD2677).
    Update README with 17 box types, 2-bit grayscale rendering, and active
    development status. Update DISPLAY.md, ARCHITECTURE.md, POWER.md with
    correct refresh times, power budget, and framebuffer format.
2026-04-24 fix(defaults): set editor defaults from infobento-config.json template
    Default boxes: Weather (Portland, OR with data), 8-Day Forecast
    (8 entries), Quote (Mark Manson). Headers off, font size 39px.
    Device ID updated to infobento-5.76 across renderer and tests.
2026-04-24 docs: fix stale 1-bit/color refs, update .tux model to 17 box types and Inter TTF
    - Replace all "1-bit framebuffer" with "2-bit grayscale" across CLAUDE.md,
    AGENTS.md, SETUP.md, API.md, INTENT_TEMPLATES.md
    - Update kickstarter copy from color eInk to B&W GDEH0576T81 spec
    - Advance .tux model: 17 box types, Inter TTF fonts, SDF borders,
    configurable layout controls, correct panel/driver references
    - Simplify consent dialog: remove product descriptions, bump version
2026-04-24 chore: advance .tux model — 17 box types, locked panel, SDF borders, TTF fonts
    Update all stale .tux artifacts: REQ-004 (11→17 box types), prototype
    scope (920x680, SDF borders, content-aware layout), wireframe (server
    PNG preview, rounded borders, configurable controls), hardware platform
    (GDEH0576T81 locked, remove panel candidates), resolution finding
    (resolved), scenarios (2-bit grayscale preview).
2026-04-24 feat(web): debounced auto-fetch, geolocation, auto-quote, portrait-first preview
    - Replace blur-based fetch with 500ms debounced input on all 5 city
    inputs (weather, forecast, forecast3d, sun, aqi)
    - Auto-fetch random quote when quote box is added with empty fields
    - Browser geolocation on first load (after consent) reverse-geocodes
    via Nominatim and populates default boxes with local weather data;
    falls back to Portland, OR on denial/error
    - Portrait preview shown first, landscape second
    - CSS for weather-status and random-quote button
    Closes #58
2026-04-24 fix(web): preview controls and box headers wrap on mobile instead of overflowing
    - Preview controls flex-wrap so Corners/Padding sliders wrap to next
    line on narrow viewports instead of going off-screen
    - Mobile: tighter control gaps, smaller slider widths, smaller font
    - Box label input gets min-width:0 so it shrinks for the remove button
    - Order controls and remove button get flex-shrink:0 to stay visible
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2026-04-25 feat(web): merge/split box pairs, replace sliders with +/- steppers
    - Add mergeBoxes() and splitBoxes() to state layer with split field
    on EditorBox, persisted to localStorage and JSON export/import
    - Merge button between unpaired adjacent boxes creates a left/right
    split pair; split-apart button below paired group undoes it
    - Paired boxes show [L]/[R] badges and blue accent group border
    - moveBox() moves paired boxes as a unit; removeBox() clears orphaned
    split on partner
    - toBentoBox() preserves split field for layout engine
    - Replace range sliders with +/- stepper buttons for font size,
    corner radius, and padding (better mobile UX)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
2026-06-16 docs(firmware): bench bring-up sketches + README (#106 Phases 1–3) (#122)
    Capture the dev-first firmware bench work for epic #106, all verified on the
    reTerminal E1001:
    - blink (Phase 1): toolchain + boot + serial path
    - static-frame (Phase 2): native 2bpp → UC8179 two-plane upload, retiring the
    framebuffer-translation risk
    - device-pull (Phase 3): Wi-Fi + GET /api/device/<id>/frame poll loop with
    If-Modified-Since/304 refresh skip
    device-pull also carries the review hardening from #119: null-check on
    getStreamPtr, non-empty Last-Modified guard, a hard total deadline in readExact,
    and WiFi.disconnect(true) before reconnect.
    Adds firmware/README.md (toolchain, phase status, framebu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
    [blink.ino, device-pull.ino, static-frame.ino]
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2026-06-17 feat(firmware): Phase 4 deep sleep + RTC wake (#106) (#127)
    * feat(firmware): Phase 4 deep sleep + RTC wake (#106)
    Replace the device-pull loop() busy-wait with a single-cycle, deep-sleep
    firmware — the "first working firmware" milestone that makes the 1–2
    refreshes/day solar/battery budget real.
    - Whole lifecycle runs in setup() and ends in esp_deep_sleep_start() for
    the IB_SLEEP_SECONDS build constant (bench 30 s; production 12h).
    - Last-Modified persists across sleeps in RTC slow memory (RTC_DATA_ATTR),
    so a 304 wake returns straight to sleep without an eInk refresh — the
    power win. A 200 fetches, caches the token (before drawFrame's in-place
    ~g_fb flip), draws, then sleep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
    [deep-sleep.ino]
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2026-06-18 feat(firmware): Phase 5 resilience (#106) (#131)
    * feat(firmware): Phase 5 resilience (#106)
    New firmware/resilient/ sketch building on deep-sleep. Every failure mode
    degrades gracefully and the device recovers on its own — the "survives the
    API being down / wrong creds / unprovisioned id" milestone.
    Failure policy ("just resume cadence"): Wi-Fi down / wrong creds / 404 /
    5xx / transport error -> don't draw, sleep the normal cadence, retry next
    wake; the eInk panel holds its last good frame at zero power, so stale
    content on failure is free (no flash framebuffer cache needed). 429 ->
    honor Retry-After. Brownout reset -> skip the fetch, sleep a longer
    recovery interval (battery/solar reco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
    [resilient.ino]
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2026-06-19 fix(firmware): E1001 pinhole pin (GPIO2) + mark Phase 6 bench-verified (#134)
    * fix(firmware): E1001 pinhole pin (GPIO2) + mark Phase 6 bench-verified
    The provisioning pinhole used PINHOLE_GPIO 9 — the production ESP32-C3
    strapping pin — but on the E1001 dev board GPIO9 is the panel SPI MOSI
    line, so it reads LOW and false-triggers a factory-reset reboot loop.
    GPIO0/BOOT is no good either (wired to the USB-serial auto-reset, reads
    LOW whenever serial is attached). Add an IB_DEV_E1001 branch that uses
    GPIO2 (expansion header J2 pin 4) for bench bring-up; production keeps
    GPIO9.
    With the pin fixed, the full Phase 6 out-of-box flow bench-verified on
    the E1001: AP-mode first boot, OS auto-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
    [provisioning.ino]
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2026-06-25 feat: configurable display refresh interval (#152) (#153)
    * feat(core): widen refreshesPerDay to 0..5760 with shared bounds (#152)
    The display refresh interval is becoming user-configurable. Replace the
    1|2 literal union with an integer count 0..5760 (interval = 86400/n):
    0 disables scheduled refresh, 3 (new default) = every 8h, 5760 ≈ every
    15s for bench testing. Export DEFAULT_REFRESHES_PER_DAY and
    MAX_REFRESHES_PER_DAY so api/web/firmware share one source of truth.
    * feat(api): generalize refresh bucket + X-Refresh-Interval wake hint (#152)
    - dataBucketMs now divides DAY_MS by any refreshesPerDay (8h for the new
    default 3); r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
    [deep-sleep.ino]
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2026-07-02 feat(firmware): orientation toggle sketch — cache both frames, green-button flip (#160) (#165)
    * feat(firmware): orientation toggle sketch — cache both frames, green-button flip (#160)
    RFC 0002 Phases B+C, drafted for bench flashing (Arduino C++, not CI-compilable).
    Extends the Phase 4 deep-sleep pull:
    - Phase B (flash store): GET /api/device/<id>/frames fetches BOTH orientations in
    one response; stores the pair to LittleFS atomically (tmp + rename, so a short
    read never destroys the prior good cache); 304 keeps the cache untouched (the
    Phase 4 power win). Built-in default_8MB partition scheme (1.5MB LittleFS).
    - Phase C (button wake): ext1 deep-sleep wake on GPIO3 (the green but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
    [orientation.ino]
2026-07-02 feat(firmware): remap factory reset to the two white buttons + resident reset screen (#171) (#172)
    * feat(firmware): remap factory reset to the two white buttons + resident reset screen (#171)
    Replaces the recessed GPIO2 pinhole with the two front white buttons held
    together for 5s, and shows a baked-in reset screen on the panel so a wiped
    device guides its own re-setup with no network.
    - provisioning.ino: reset trigger GPIO2 pinhole -> both white buttons
    (GPIO4 right + GPIO5 left, active-low, verified vs Seeed's E1001 wiki) held
    5s; green button (GPIO3) flips the reset screen landscape<->portrait
    (default landscape); vendored UC8179 driver + drawResetScreen() draws the
    resident fr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
    [provisioning.ino]
2026-07-02 feat(firmware): Phase 7 integrated sketch — provision -> NVS -> deep-sleep dashboard (#173) (#174)
    One secrets.h-free sketch that unifies the phase sketches so a provisioned device
    boots straight into the dashboard:
    - Captive portal now captures a DEVICE ID (+ ssid/pass/optional server) and
    persists all of it to NVS; server defaults to https://www.infobento.com.
    - Configured boot: Wi-Fi from NVS -> GET <server>/api/device/<deviceid>/frames
    -> cache both orientations -> draw -> deep sleep (Phase 4/5 core, #165).
    - Green button (GPIO3): flips the dashboard orientation when configured, or the
    reset screen in AP mode. White combo (GPIO4+GPIO5, 5s): factory reset + resident
    reset scree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
    [integrated.ino]
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2026-08-24 fix(docs,web): accuracy sweep before public flip — stale versions, Phase 7 story, hardware claims, API reference (#242)
    * fix(docs,web): accuracy sweep before public flip — stale versions, Phase 7 story, hardware claims, API reference (#239)
    * fix(docs): finish the refresh-cadence sweep — 1-3x/day (default 3) everywhere
    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
    [deep-sleep.ino]
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

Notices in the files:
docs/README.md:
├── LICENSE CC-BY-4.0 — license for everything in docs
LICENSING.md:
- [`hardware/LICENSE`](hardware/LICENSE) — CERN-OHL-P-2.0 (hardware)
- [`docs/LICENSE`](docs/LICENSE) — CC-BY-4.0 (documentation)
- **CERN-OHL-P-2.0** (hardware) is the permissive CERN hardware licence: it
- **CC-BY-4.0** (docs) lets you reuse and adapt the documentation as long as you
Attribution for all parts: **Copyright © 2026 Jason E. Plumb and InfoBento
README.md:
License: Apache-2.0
